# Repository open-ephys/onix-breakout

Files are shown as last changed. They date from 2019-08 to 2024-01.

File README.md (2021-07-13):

# ONIX Breakout Board
This board allows bench access to the IO provided by the [ONIX FMC Host
Board](https://github.com/open-ephys/onix-fmc-host). It features:

- 4x coax headstage ports, each with a physical power switch
- BNC, IDC (ribbon), or direct wire access to 12 analog inputs or outputs
- IDC (ribbon) or direct wire access to 8 digital outputs and 8 digital inputs
  (5 volt tolerate)
- 6x buttons for marking experimental events
- 41x state-indication LEDs
- 3x high-speed clock feed throughs
- Full-speed, USB 2.0 access to the onboard [TinyFPGA
  BX](https://www.crowdsupply.com/tinyfpga/tinyfpga-bx) for communication,
  programming, and customization 
- [HARP bus](https://www.cf-hw.org/harp)
- Rugged M6 or 1/4-20 mounting options compliant with 19" racks and optical
  tables
- Open-source [gateware](./gateware) created using open-source FPGA toolchain:
  [yosys](http://www.clifford.at/yosys/) & [nextpnr](https://github.com/YosysHQ/nextpnr)

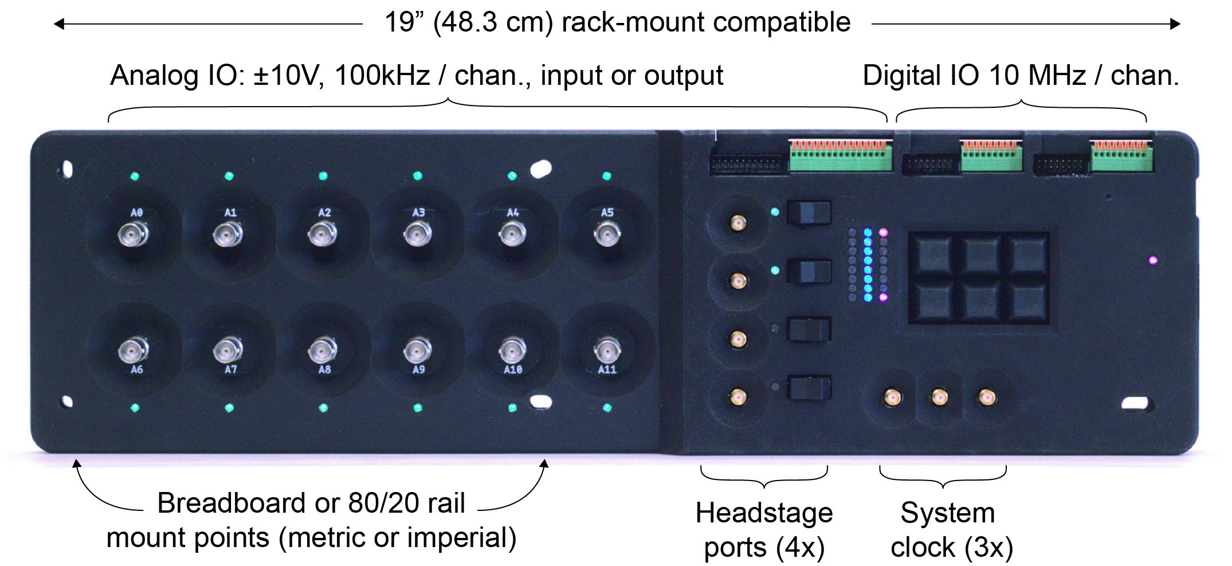
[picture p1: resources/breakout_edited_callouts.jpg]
ONIX Breakout Board revision 1.5


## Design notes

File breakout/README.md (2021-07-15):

## Bill of Materials
The bill of materials for this device can be found
[here](https://docs.google.com/spreadsheets/d/1dZ0ANEF8czLGsupTHfIfsVSbmfPmiTM9wAFmvc-KBbU/edit?usp=sharing).

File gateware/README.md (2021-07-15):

# Breakout Board Gateware
The breakout board contains a [TinyFPGA BX](https://tinyfpga.com/bx/guide.html)
(Lattice ICE40 breakout board) for digital input serialization, digital output
deserialization, interpreting user input, and driving indication LEDs.

## Build Steps
The build process is governed by the included Makefile. There are a few key
targets:

1. `make`: makes the bit file
1. `make sim`: Perform RTL-level simuatation using iverilog
1. `make postsim`: Perform RTL-level simuatation using iverilog
1. `make prog`: makes the bit file and attempts to programm the FPGA using `tinyprog`
1. `make test`: makes the testbenches
1. `make view-test`: makes the testbenches if required and attempts to view resulting waveforms using GTKWave
1. `make clean`: cleans all built artifacts

To build and program the bit file, you will need the
[`yosys`](http://www.clifford.at/yosys/),
[`nextpnr`](https://github.com/YosysHQ/nextpnr), and
[`tinyprog`](https://pypi.org/project/tinyprog/). To build, simulate, and view
the testbenches you will need `yosys`,
[`iverilog`](http://iverilog.icarus.com/), and
[`gtkwave`](http://gtkwave.sourceforge.net/).

### Installing the Toolchain
Install `yosys`:

```
sudo apt install yosys
```

Next, you will need to build and install `nextpnr` as described
[here](https://github.com/YosysHQ/nextpnr#nextpnr-ice40).

### Installing the Programmer
Install `APIO` and `tinyprog`, open up a terminal and run the following
commands:

```
pip install apio==0.4.0b5 tinyprog
apio install system scons icestorm iverilog
apio drivers --serial-enable
```

On Unix systems, you may need to add yourself to the dialout group in order for
your user to be able to access serial ports. You can do that by running:

```
sudo usermod -a -G dialout $USER
```

Connect your TinyFPGA BX board(s) and make sure the bootloader is up to date by
running the following command:

```
tinyprog --update-bootloader
```

Now you can program the FPGA using

```
make prog
```

This will create all required bit files etc before programming

### Building and Examining the Testbenches
Simulation is done with Icrarus Verilog

```
sudo apt install iverilog
sudo apt install gtkwave
```

Then simply `make sim`. You can look at the resulting `.vcd` files using
gtkwave using `make view-test`.

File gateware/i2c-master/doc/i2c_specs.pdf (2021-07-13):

I

2

# C-Master Core Specification

# Author: Richard Herveille

### rherveille@opencores.org

### Rev. 0.9 July 3, 2003

## This page has been intentionally left blank

### Revision History

Rev. | Date | Author | Description
0.1 | 17/02/01 | Richard Herveille | First draft release
0.2 | 01/03/01 | Richard Herveille | Some cleaning up throughout the document Added ‘Programming Examples’ section
0.3 | | Richard Herveille | Added some comments after core-changes - added BUSY bit (status register) - changed I2C IO for ASIC support - added comment for FGPA IO
0.4 | 10/19/01 | Richard Herveille | Changed core’s databus size to 8bit. Changed documentation to reflect changes. Changed port names to new naming convention.
0.5 | 18/02/02 | Richard Herveille | Changed table headers. Added OpenCores logo.
0.5a | 05/02/02 | Richard Herveille | Reviewed entire document.
0.6 | 21/03/02 | Richard Herveille | Added Appendix A, Synthesis Results
0.7 | 25/06/02 | Richard Herveille | Changed Prescale Register formula
0.8 | 30/12/02 | Richard Herveille | Added Multi-Master capabilities. New timing diagrams.
0.9 | 03/07/03 | Richard Herveille | Changed ‘0x5C’ to ‘0xAC’ in Example1. Changed ‘RW’ to ‘W’ in Command Register. Changed ‘RW’ to ‘W’ in Transmit Register.

OpenCores | I²
C-Master core | 7/3/2003
www.opencores.org | Rev 0.8 Preliminary | 1 of 15

1

# Introduction

I

2
C is a two-wire, bi-directional serial bus that provides a simple and efficient method of data exchange between devices. It is most suitable for applications requiring occasional communication over a short distance between many devices. The I²
C standard is a true
multi-master bus including collision detection and arbitration that prevents data corruption if two or more masters attempt to control the bus simultaneously.

The interface defines 3 transmission speeds:
- Normal: 100Kbps
- Fast: 400Kbps
- High speed: 3.5Mbps

Only 100Kbps and 400Kbps modes are supported directly. For High speed special IOs are needed. If these IOs are available and used, then High speed is also supported.

## FEATURES

- Compatible with Philips I²
C standard
- Multi Master Operation
- Software programmable clock frequency
- Clock Stretching and Wait state generation
- Software programmable acknowledge bit
- Interrupt or bit-polling driven byte-by-byte data-transfers
- Arbitration lost interrupt, with automatic transfer cancelation
- Start/Stop/Repeated Start/Acknowledge generation
- Start/Stop/Repeated Start detection
- Bus busy detection
- Supports 7 and 10bit addressing mode
- Operates from a wide range of input clock frequencies
- Static synchronous design
- Fully synthesizable

2

# IO ports

## 2.1 Core Parameters

Parameter | Type | Default | Description
ARST_LVL | Bit | 1’b0 | Asynchronous reset level

### 2.1.1 ARST_LVL

The asynchronous reset level can be set to either active high (1’b1) or active low (1’b0).

## 2.2 WISHBONE interface signals

Port | Width | Direction | Description
wb_clk_i | 1 | Input | Master clock
wb_rst_i | 1 | Input | Synchronous reset, active high
arst_i | 1 | Input | Asynchronous reset
wb_adr_i | 3 | Input | Lower address bits
wb_dat_i | 8 | Input | Data towards the core
wb_dat_o | 8 | Output | Data from the core
wb_we_i | 1 | Input | Write enable input
wb_stb_i | 1 | Input | Strobe signal/Core select input
wb_cyc_i | 1 | Input | Valid bus cycle input
wb_ack_o | 1 | Output | Bus cycle acknowledge output
wb_inta_o | 1 | Output | Interrupt signal output

The core features a WISHBONE RevB.3 compliant WISHBONE Classic interface. All output signals are registered. Each access takes 2 clock cycles.
arst_i is not a WISHBONE compatible signal. It is provided for FPGA implementations. Using [arst_i] instead of [wb_rst_i] can result in lower cell-usage and higher performance, because most FPGAs provide a dedicated asynchronous reset path. Use either [arst_i] or [wb_rst_i], tie the other to a negated state.

## 2.3 External connections

Port | Width | Direction | Description
scl_pad_i | 1 | Input | Serial Clock line input
scl_pad_o | 1 | Output | Serial Clock line output
scl_pad_oe | 1 | Output | Serial Clock line output enable
sda_pad_i | 1 | Input | Serial Data line input
sda_pad_o | 1 | Output | Serial Data line output
sda_pad_oe | 1 | Output | Serial Data line output enable

The I²
C interface uses a serial data line (SDA) and a serial clock line (SCL) for data transfers. All devices connected to these two signals must have open drain or open collector outputs. Both lines must be pulled-up to VCC by external resistors.

The tri-state buffers for the SCL and SDA lines must be added at a higher hierarchical level. Connections should be made according to the following figure:

For FPGA designs the compiler can automatically insert these buffers using the following VHDL code:

scl <= scl_pad_o when (scl_padoen_oe = ‘0’) else ‘Z’;
sda <= sda_pad_o when (sda_padoen_oe = ‘0’) else ‘Z’;
scl_pad_i <= scl;
scl_pad_i <= sda;

Verilog code:

assign scl = scl_padoen_oe ? 1’bz : scl_pad_o; assign sda = sda_padoen_oe ? 1’bz: sda_pad_o; assign scl_pad_i = scl;
assign sda_pad_i = sda;

scl_pad_i

scl_pad_o

scl_padoen_o
sda_pad_i

sda_pad_o

sda_padoen_o

SCL

SDA

3

# Registers

## 3.1 Registers list

Name | Address | Width | Access | Description
PRERlo | 0x00 | 8 | RW | Clock Prescale register lo-byte
PRERhi | 0x01 | 8 | RW | Clock Prescale register hi-byte
CTR | 0x02 | 8 | RW | Control register
TXR | 0x03 | 8 | W | Transmit register
RXR | 0x03 | 8 | R | Receive register
CR | 0x04 | 8 | W | Command register
SR | 0x04 | 8 | R | Status register

## 3.2 Register description

### 3.2.1 Prescale Register

This register is used to prescale the SCL clock line. Due to the structure of the I² C
interface, the core uses a 5*SCL clock internally. The prescale register must be programmed to this 5*SCL frequency (minus 1). Change the value of the prescale register only when the ‘EN’ bit is cleared.

Example: wb_clk_i = 32MHz, desired SCL = 100KHz
1 | 63 ( | ) | 3 ( | ) 5 100
32 | dec | F hex
KHz
MHz prescale | − = | = ∗ =

Reset value: 0xFFFF

### 3.2.2 Control register

Bit # | Access | Description
7 | RW | EN, I² C core enable bit. When set to ‘1’, the core is enabled. When set to ‘0’, the core is disabled.
6 | RW | IEN, I² C core interrupt enable bit. When set to ‘1’, interrupt is enabled. When set to ‘0’, interrupt is disabled.
5:0 | RW | Reserved
Reset Value: 0x00

The core responds to new commands only when the ‘EN’ bit is set. Pending commands are finished. Clear the ‘EN’ bit only when no transfer is in progress, i.e. after a STOP command, or when the command register has the STO bit set. When halted during a transfer, the core can hang the I²
C bus.

### 3.2.3 Transmit register

Bit # | Access | Description
7:1 | W | Next byte to transmit via I² C
0 | W | In case of a data transfer this bit represent the data’s LSB. In case of a slave address transfer this bit represents the RW bit. ‘1’ = reading from slave ‘0’ = writing to slave

Reset value: 0x00

### 3.2.4 Receive register

Bit # | Access | Description
7:0 | R | Last byte received via I² C
Reset value: 0x00

### 3.2.5 Command register

Bit # | Access | Description
7 | W | STA, generate (repeated) start condition
6 | W | STO, generate stop condition
5 | W | RD, read from slave
4 | W | WR, write to slave
3 | W | ACK, when a receiver, sent ACK (ACK = ‘0’) or NACK (ACK = ‘1’)
2:1 | W | Reserved
0 | W | IACK, Interrupt acknowledge. When set, clears a pending interrupt.
Reset Value: 0x00

The STA, STO, RD, WR, and IACK bits are cleared automatically. These bits are always read as zeros.

### 3.2.6 Status register

Bit # | Access | Description
7 | R | RxACK, Received acknowledge from slave. This flag represents acknowledge from the addressed slave. ‘1’ = No acknowledge received ‘0’ = Acknowledge received
6 | R | Busy, I² C bus busy ‘1’ after START signal detected ‘0’ after STOP signal detected
5 | R | AL, Arbitration lost This bit is set when the core lost arbitration. Arbitration is lost when: • a STOP signal is detected, but non requested • The master drives SDA high, but SDA is low. See bus-arbitration section for more information.
4:2 | R | Reserved
1 | R | TIP, Transfer in progress. ‘1’ when transferring data ‘0’ when transfer complete
0 | R | IF, Interrupt Flag. This bit is set when an interrupt is pending, which will cause a processor interrupt request if the IEN bit is set. The Interrupt Flag is set when: • one byte transfer has been completed • arbitration is lost

Reset Value: 0x00

Please note that all reserved bits are read as zeros. To ensure forward compatibility, they should be written as zeros.

4

# Operation

## 4.1 System Configuration

The I²
C system uses a serial data line (SDA) and a serial clock line (SCL) for data transfers. All devices connected to these two signals must have open drain or open collector outputs. The logic AND function is exercised on both lines with external pull-up resistors.

Data is transferred between a Master and a Slave synchronously to SCL on the SDA line on a byte-by-byte basis. Each data byte is 8 bits long. There is one SCL clock pulse for each data bit with the MSB being transmitted first. An acknowledge bit follows each transferred byte. Each bit is sampled during the high period of SCL; therefore, the SDA line may be changed only during the low period of SCL and must be held stable during the high period of SCL. A transition on the SDA line while SCL is high is interpreted as a command (see START and STOP signals).

## 4.2 I² C Protocol

Normally, a standard communication consists of four parts:
1) START signal generation
2) Slave address transfer
3) Data transfer
4) STOP signal generation
S | A7 | A6 | A5 | A4 | A3 | A2 | A1 | RW ACK | D7 | D6 | D5 | D4 | D3 | D2 | D1 | D0 NACK | P

SCL

SDA

1 | 2 | 3 | 4 | 5 | 6 | 7 | 8 | 9
MSB | LSB
1 | 2 | 3 | 4 | 5 | 6 | 7 | 8 | 9
MSB | LSB

### 4.2.1 START signal

When the bus is free/idle, meaning no master device is engaging the bus (both SCL and SDA lines are high), a master can initiate a transfer by sending a START signal. A START signal, usually referred to as the S-bit, is defined as a high-to-low transition of SDA while SCL is high. The START signal denotes the beginning of a new data transfer. A Repeated START is a START signal without first generating a STOP signal. The master uses this method to communicate with another slave or the same slave in a different transfer direction (e.g. from writing to a device to reading from a device) without releasing the bus.

The core generates a START signal when the STA-bit in the Command Register is set and the RD or WR bits are set. Depending on the current status of the SCL line, a START or Repeated START is generated.

### 4.2.2 Slave Address Transfer

The first byte of data transferred by the master immediately after the START signal is the slave address. This is a seven-bits calling address followed by a RW bit. The RW bit signals the slave the data transfer direction. No two slaves in the system can have the same address. Only the slave with an address that matches the one transmitted by the master will respond by returning an acknowledge bit by pulling the SDA low at the 9th SCL clock cycle.

Note: The core supports 10bit slave addresses by generating two address transfers. See the Philips I²
C specifications for more details.

The core treats a Slave Address Transfer as any other write action. Store the slave device’s address in the Transmit Register and set the WR bit. The core will then transfer the slave address on the bus.

### 4.2.3 Data Transfer

Once successful slave addressing has been achieved, the data transfer can proceed on a byte-by-byte basis in the direction specified by the RW bit sent by the master. Each transferred byte is followed by an acknowledge bit on the 9th SCL clock cycle. If the slave signals a No Acknowledge, the master can generate a STOP signal to abort the data transfer or generate a Repeated START signal and start a new transfer cycle.

If the master, as the receiving device, does not acknowledge the slave, the slave releases the SDA line for the master to generate a STOP or Repeated START signal.

To write data to a slave, store the data to be transmitted in the Transmit Register and set the WR bit. To read data from a slave, set the RD bit. During a transfer the core set the TIP flag, indicating that a Transfer is In Progress. When the transfer is done the TIP flag is reset, the IF flag set and, when enabled, an interrupt generated. The Receive Register contains valid data after the IF flag has been set. The user may issue a new write or read command when the TIP flag is reset.

### 4.2.4 STOP signal

The master can terminate the communication by generating a STOP signal. A STOP signal, usually referred to as the P-bit, is defined as a low-to-high transition of SDA while SCL is at logical ‘1’.

## 4.3 Arbitration Procedure

### 4.3.1 Clock Synchronization

The I²
C bus is a true multimaster bus that allows more than one master to be connected on it. If two or more masters simultaneously try to control the bus, a clock synchronization procedure determines the bus clock. Because of the wired-AND connection of the I²
C signals a high to low transition affects all devices connected to the bus. Therefore a high to low transition on the SCL line causes all concerned devices to count off their low period. Once a device clock has gone low it will hold the SCL line in that state until the clock high state is reached. Due to the wired-AND connection the SCL line will therefore be held low by the device with the longest low period, and held high by the device with the shortest high period.

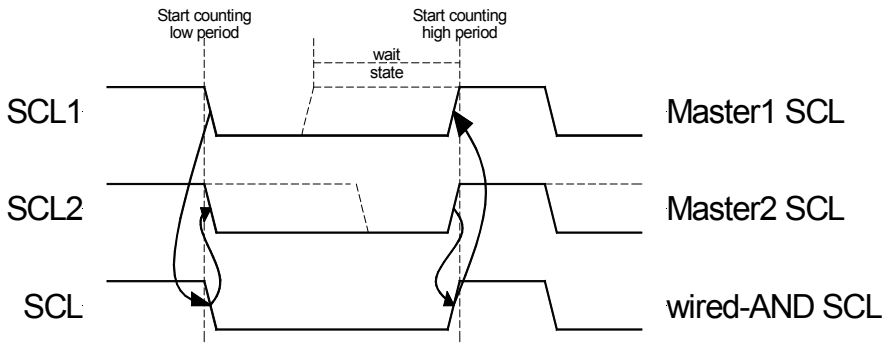
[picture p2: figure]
Start counting low period; wait state; Start counting high period; SCL1; SCL2; SCL; Master1 SCL; Master2 SCL; wired-AND SCL

### 4.3.2 Clock Stretching

Slave devices can use the clock synchronization mechanism to slow down the transfer bit rate. After the master has driven SCL low, the slave can drive SCL low for the required period and then release it. If the slave’s SCL low period is greater than the master’s SCL low period, the resulting SCL bus signal low period is stretched, thus inserting wait-states.

5

# Architecture

The I2C core is built around four primary blocks; the Clock Generator, the Byte Command Controller, the Bit Command Controller and the DataIO Shift Register. All other blocks are used for interfacing or for storing temporary values.

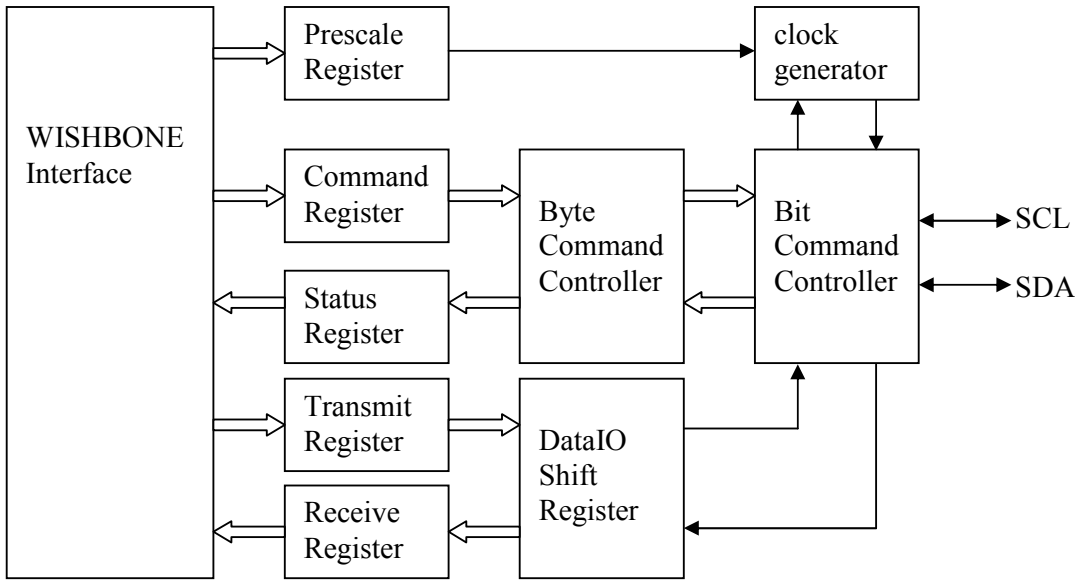
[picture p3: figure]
SCL; SDA; Prescale Register; clock generator; Command Register; Status Register; Byte Command Controller; Bit Command Controller; WISHBONE Interface; Transmit Register; Receive Register; DataIO Shift Register

## 5.1 Clock Generator

The Clock Generator generates an internal 4*Fscl clock enable signal that triggers all synchronous elements in the Bit Command Controller. It also handles clock stretching needed by some slaves.

## 5.2 Byte Command Controller

The Byte Command Controller handles I2C traffic at the byte level. It takes data from the Command Register and translates it into sequences based on the transmission of a single byte. By setting the START, STOP, and READ bit in the Command Register, for example, the Byte Command Controller generates a sequence that results in the

Fig. 5.1 Internal structure I2C Master Core

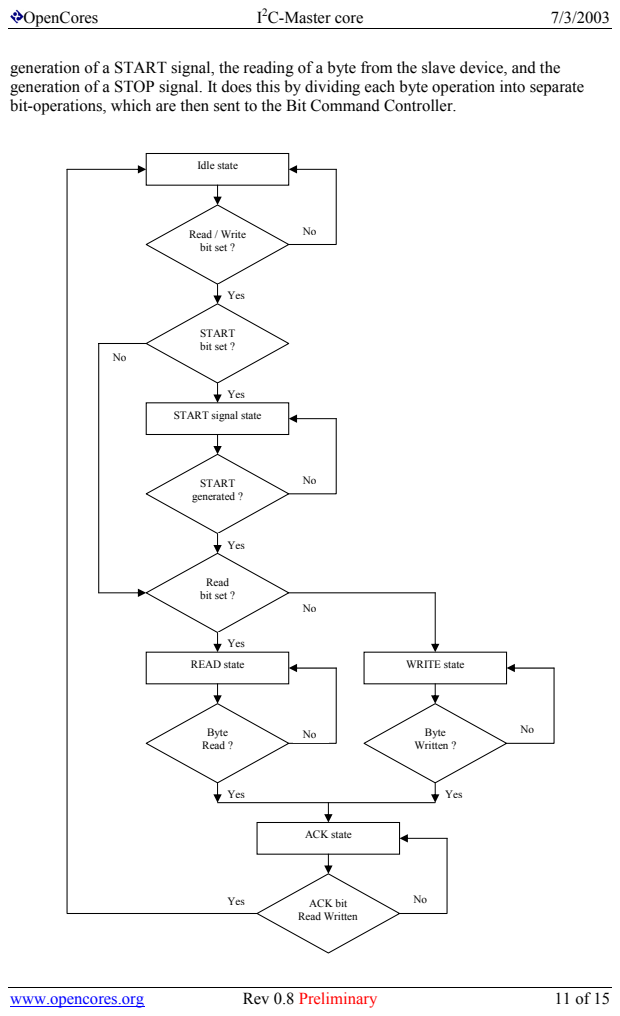
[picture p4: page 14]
Idle state; Read / Write bit set ?; Yes; START bit set ?; Read bit set ?; READ state; Byte Read ?; ACK state; WRITE state; Byte Written ?; ACK bit Read Written

generation of a START signal, the reading of a byte from the slave device, and the
generation of a STOP signal. It does this by dividing each byte operation into separate
bit-operations, which are then sent to the Bit Command Controller.

START signal state

START generated ?

## 5.3 Bit Command Controller

The Bit Command Controller handles the actual transmission of data and the generation of the specific levels for START, Repeated START, and STOP signals by controlling the SCL and SDA lines. The Byte Command Controller tells the Bit Command Controller which operation has to be performed. For a single byte read, the Bit Command Controller receives 8 separate read commands. Each bit-operation is divided into 5 pieces (idle and A, B, C, and D), except for a STOP operation which is divided into 4 pieces (idle and A, B, and C).

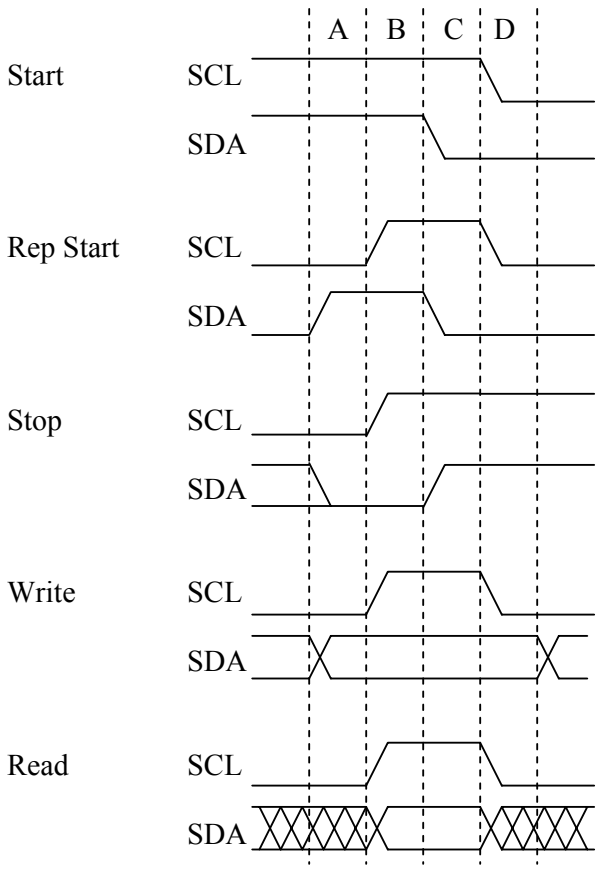
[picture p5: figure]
Start; SCL; SDA; Rep Start; Stop; Write; Read

## 5.4 DataIO Shift Register

The DataIO Shift Register contains the data associated with the current transfer. During a read action, data is shifted in from the SDA line. After a byte has been read the contents are copied into the Receive Register. During a write action, the Transmit Register’s contents are copied into the DataIO Shift Register and are then transmitted onto the SDA line.

6

# Programming examples

## Example 1

Write 1 byte of data to a slave.

Slave address = 0x51 (b”1010001”) Data to write = 0xAC

I2C Sequence:
1) generate start command
2) write slave address + write bit
3) receive acknowledge from slave
4) write data
5) receive acknowledge from slave
6) generate stop command

Commands:
1) write 0xA2 (address + write bit) to Transmit Register, set STA bit, set WR bit. -- wait for interrupt or TIP flag to negate --
2) read RxACK bit from Status Register, should be ‘0’.
write 0xAC to Transmit register, set STO bit, set WR bit.
-- wait for interrupt or TIP flag to negate --
3) read RxACK bit from Status Register, should be ‘0’.

Please note that the time for the Interrupt Service Routine is not shown here. It is assumed that the ISR is much faster then the I²
C cycle time, and therefore not visible.

## Example 2

Read a byte of data from an I2C memory device.

Slave address = 0x4E
Memory location to read from = 0x20

I2C sequence:
1) generate start signal
2) write slave address + write bit
3) receive acknowledge from slave
4) write memory location
5) receive acknowledge from slave
6) generate repeated start signal
7) write slave address + read bit
8) receive acknowledge from slave
9) read byte from slave
10) write no acknowledge (NACK) to slave, indicating end of transfer
11) generate stop signal

Commands:
1) write 0x9C (address + write bit) to Transmit Register, set STA bit, set WR bit. -- wait for interrupt or TIP flag to negate --
2) read RxACK bit from Status Register, should be ‘0’.
write 0x20 to Transmit register, set WR bit.
-- wait for interrupt or TIP flag to negate --
3) read RxACK bit from Status Register, should be ‘0’.
write 0x9D (address + read bit) to Transmit Register, set STA bit, set WR bit. -- wait for interrupt or TIP flag to negate --
4) set RD bit, set ACK to ‘1’ (NACK), set STO bit

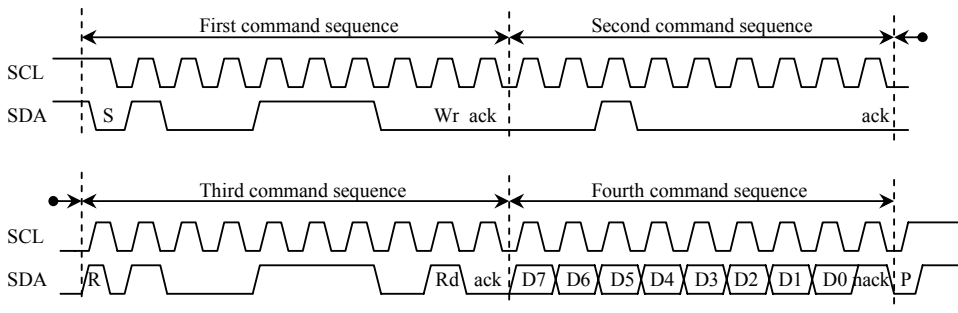
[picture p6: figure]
First command sequence; Second command sequence; SDA; Wr ack; ack; SCL; Third command sequence; Fourth command sequence

Please note that the time for the Interrupt Service Routine is not shown here. It is assumed that the ISR is much faster then the I²
C cycle time, and therefore not visible.
SDA | R | Rd ack | D7 D6 D5 D4 D3 D2 D1 D0 nack | P

# Appendix A

# Synthesis results

Synthesis tool: Synplify Pro

Technology | Device | Speed grade | Fmax | Resource usage
ACTEL | A54SX16ATQ100 | std | 58MHz | Modules: 352
Altera | EP10K50ETC144 | -3 | 82MHz | LCs: 294
| EP20K30ETC144 | -3 | 74MHz | ATOMS: 257
Xilinx | 2s15CS144 | -5 | 82MHz | LUTs: 229
| XCV50ECS144 | -8 | 118MHz | LUTs: 230

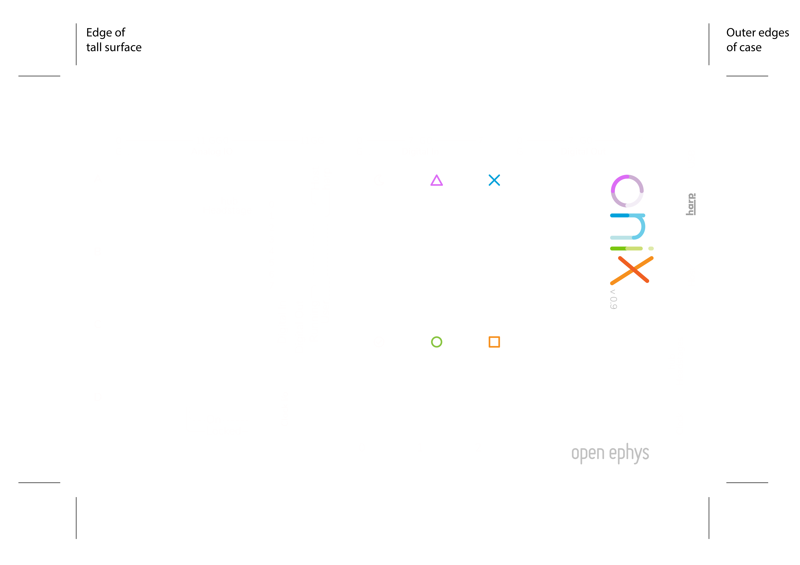
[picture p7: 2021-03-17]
mechanical/label/top_label_600ppi.png

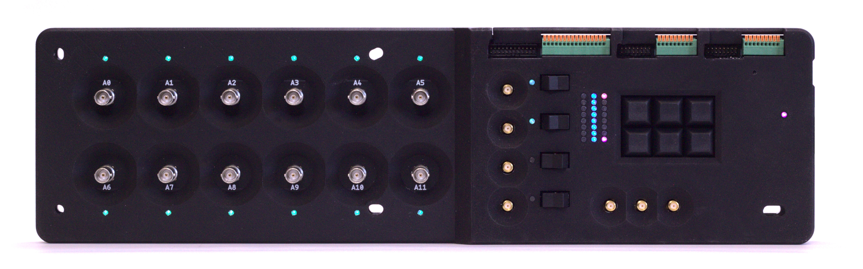
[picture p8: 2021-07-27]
resources/breakout_edited.jpg

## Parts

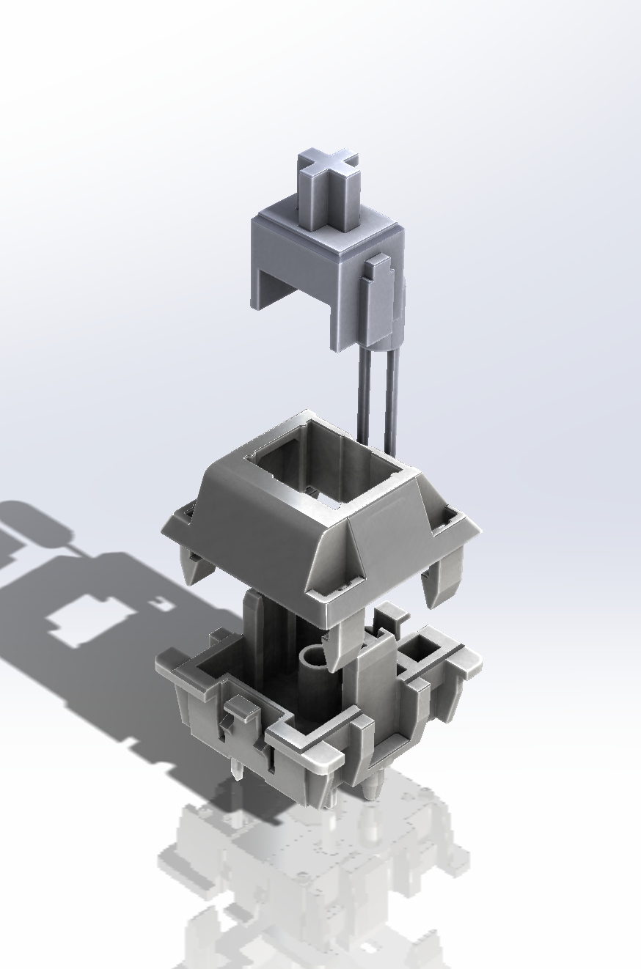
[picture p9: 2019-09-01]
mechanical/case/components/cherryMX/Renderings/屏幕截图(27)_副本.jpg

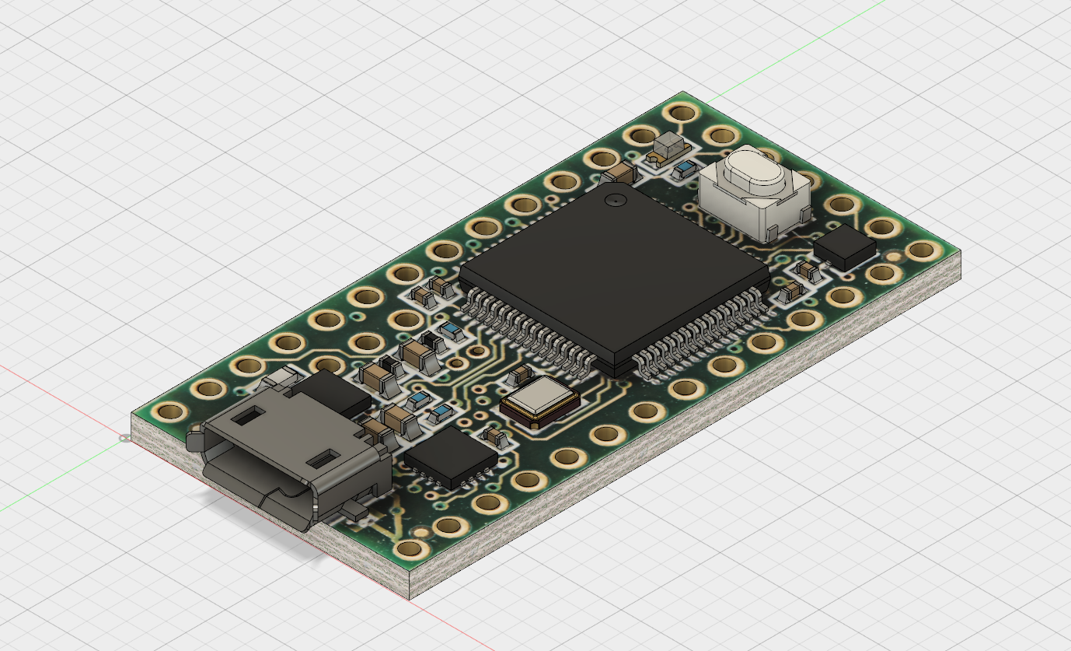
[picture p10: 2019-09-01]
mechanical/case/components/teensy/Teensy_3_1 v13.png

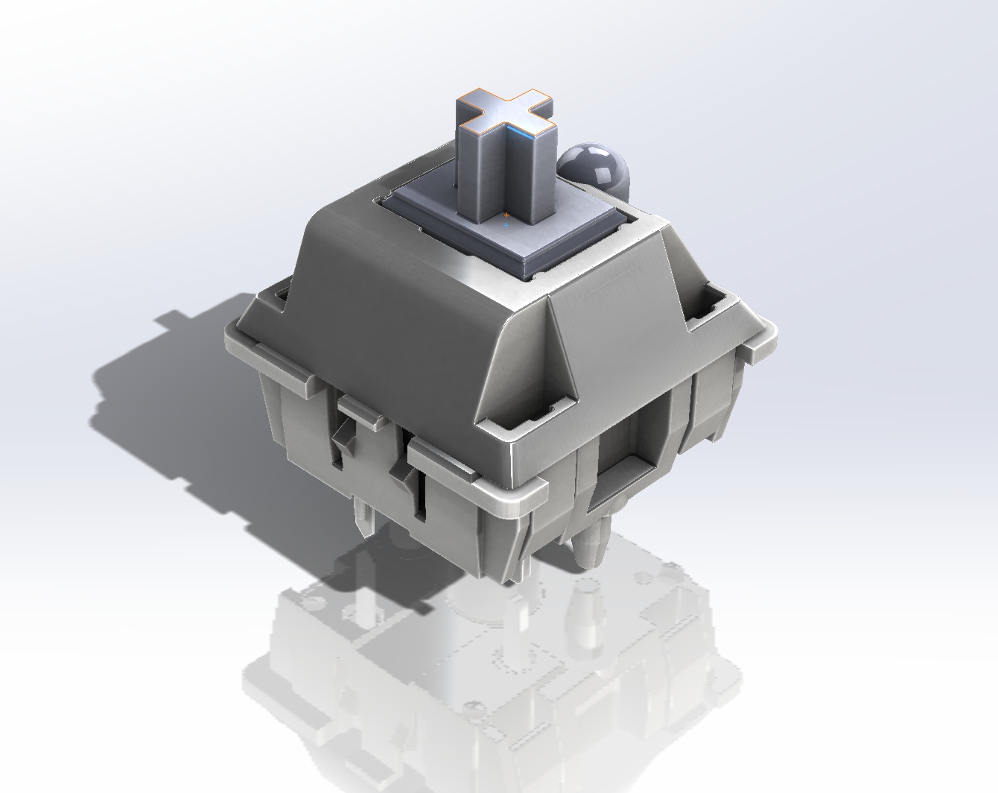
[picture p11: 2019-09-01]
mechanical/case/components/cherryMX/Renderings/屏幕截图(23).jpg

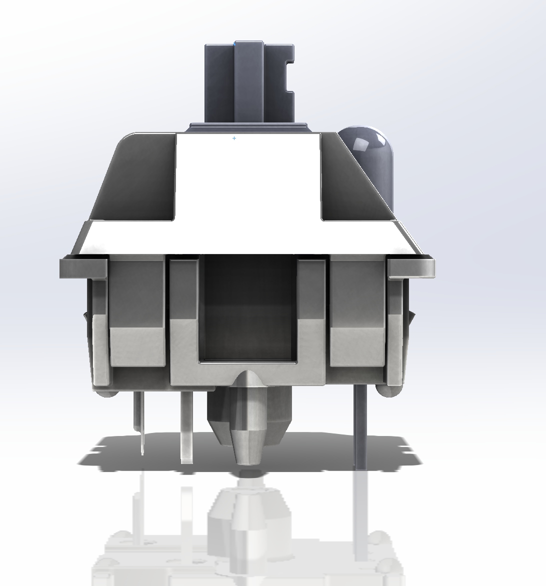
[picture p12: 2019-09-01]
mechanical/case/components/cherryMX/Renderings/屏幕截图(26).jpg

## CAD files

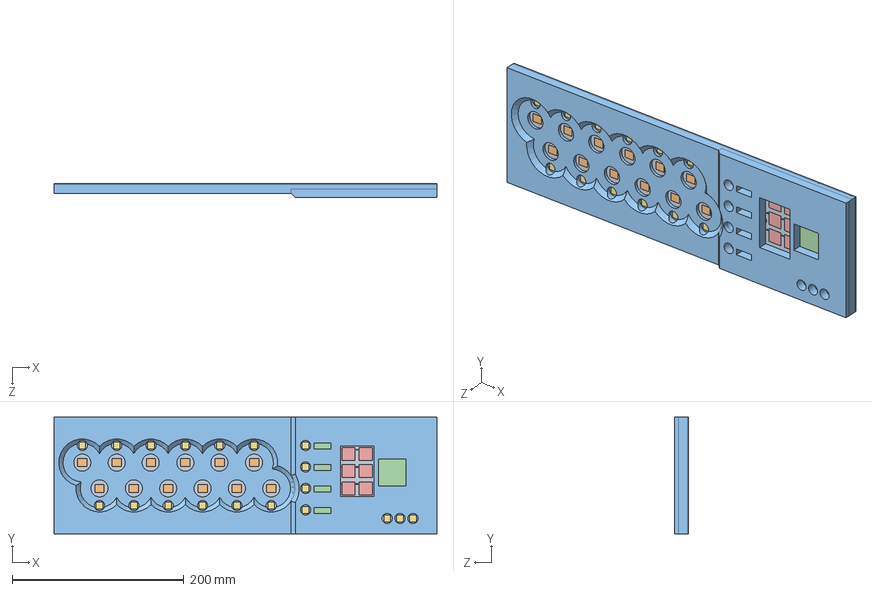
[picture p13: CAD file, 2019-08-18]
case/analog-io-breakout_assembly.SLDASM
446.0 x 136.0 x 16.6 mm
Board.step
0731010360.step x 12
FE10-2.step
MMCX-J-P-X-RA-SM1.step x 7
SCREW2.step x 2
SCREW8.step x 2
SMA_JACK_142-0701-201.step x 19
TESTPOINT_2MM.step
DIODE-ESD-BIDIRECTIONALDO-214AA.step x 12
TEENSY_3.1_BASIC.step
1503_02.step
ADAFRUIT_1_5_OLED.step
CHERRY-MX.step x 6
12226-8250-00FR.step
1k.step x 34
SJ_2_0201.step x 2
LTC2875_DFN.step
FIN1032MTCX.step
SN65LVDS9638DGN.step x 2
ROCKER_SWITCH.step x 4
G6KU-2F-RF-TR09DC5.step x 4
LTM4622A.step
10uF.step
47uF.step x 2
B1,27.step x 2
TCA9555.step
breakout_case_top_shell

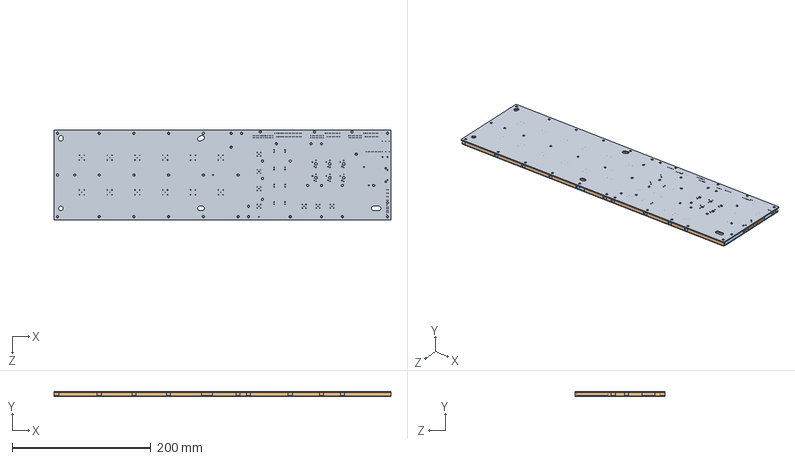
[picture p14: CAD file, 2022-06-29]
mechanical/case/breakout_assembly_bottom_only_lasercut.SLDASM
485.0 x 7.10 x 130.0 mm
breakout_case_pcb_3
pcb_spacer_lasercut
pcb_bottom_waterjet

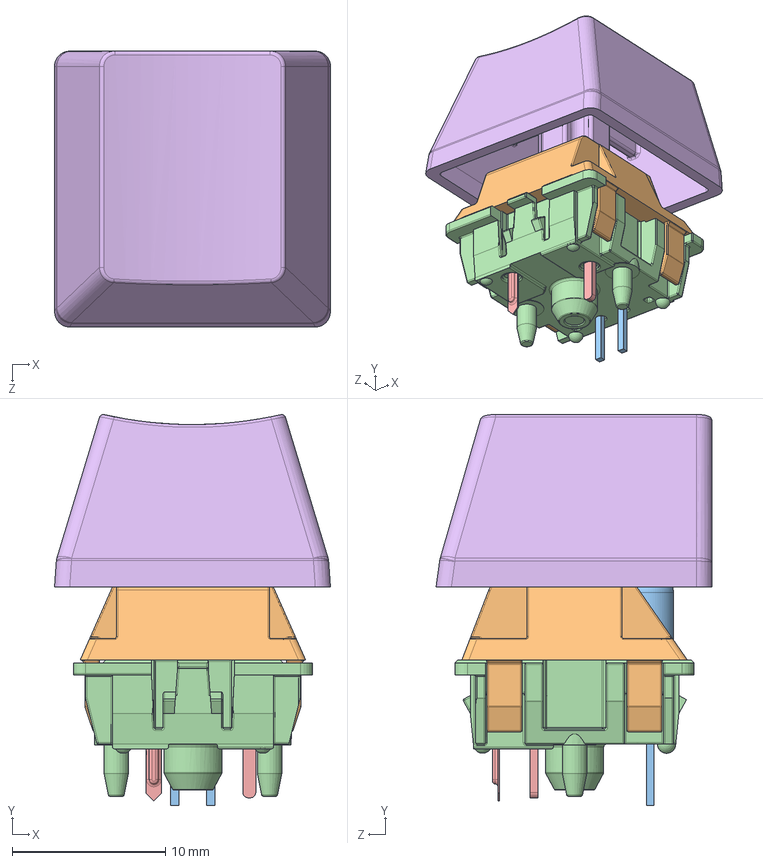
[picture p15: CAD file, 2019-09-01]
mechanical/case/components/cherryMX/MX 按键.SLDASM
18.0 x 25.5 x 18.0 mm
MX 轴 按键
MX 轴 轴体
MX轴 无帽LED
MX轴 轴体 底部
针脚
MX 轴标准键帽

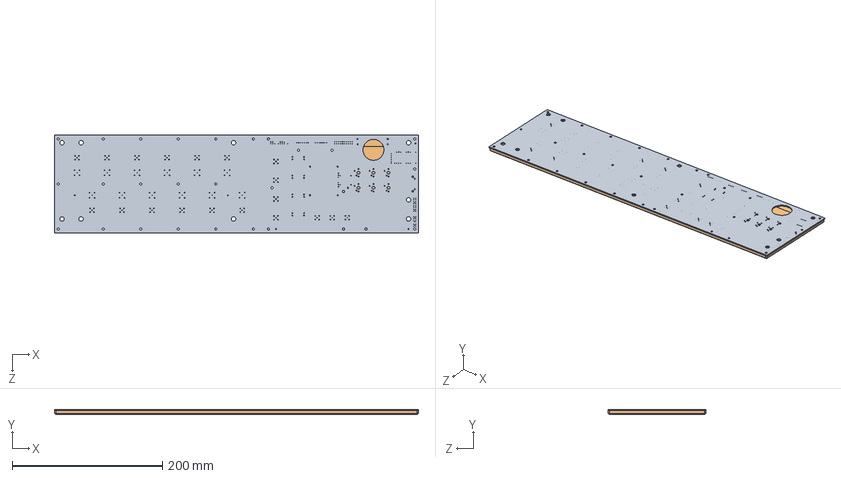
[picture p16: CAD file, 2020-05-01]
mechanical/case/breakout_assembly_bottom_only.SLDASM
485.0 x 6.60 x 130.0 mm

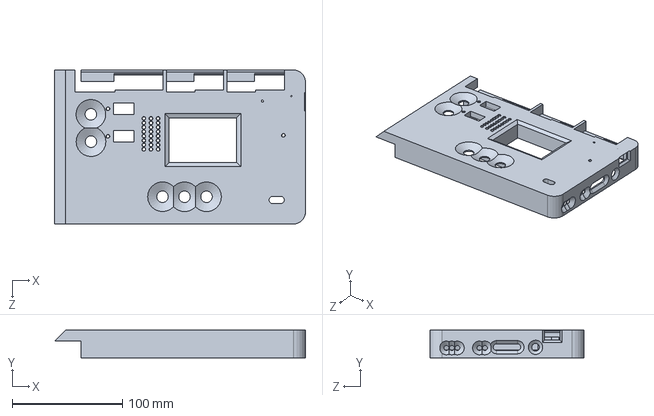
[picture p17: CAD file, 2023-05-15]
mechanical/case/breakout_case_top_shell_2-headstage_b.SLDPRT
228.0 x 25.0 x 140.0 mm

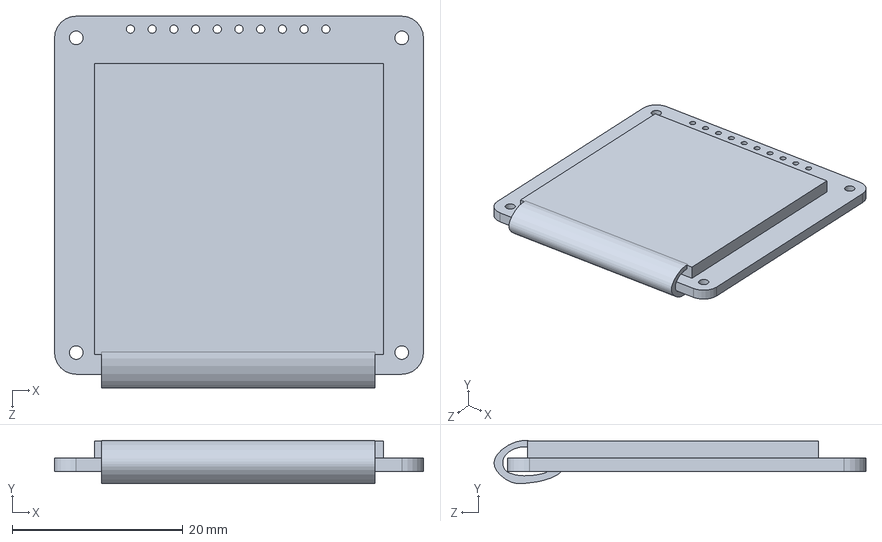
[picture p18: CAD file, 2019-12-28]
mechanical/case/components/1_5_inch_screen/oled_module.SLDPRT
43.2 x 5.05 x 43.5 mm

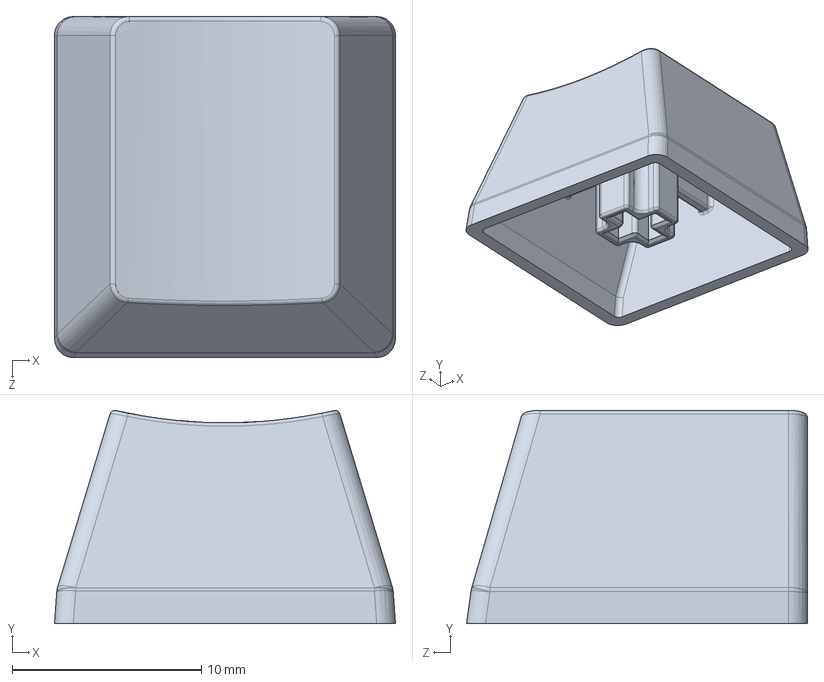
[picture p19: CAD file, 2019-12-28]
mechanical/case/components/cherryMX/MX 轴标准键帽.SLDPRT
18.0 x 11.3 x 18.0 mm

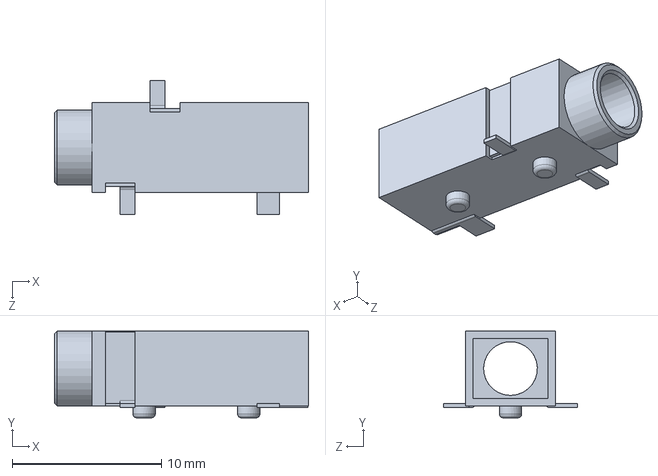
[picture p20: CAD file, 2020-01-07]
mechanical/case/components/CUI_DEVICES_SJ-3523-SMT-TR.sldprt
17.0 x 5.80 x 9.00 mm

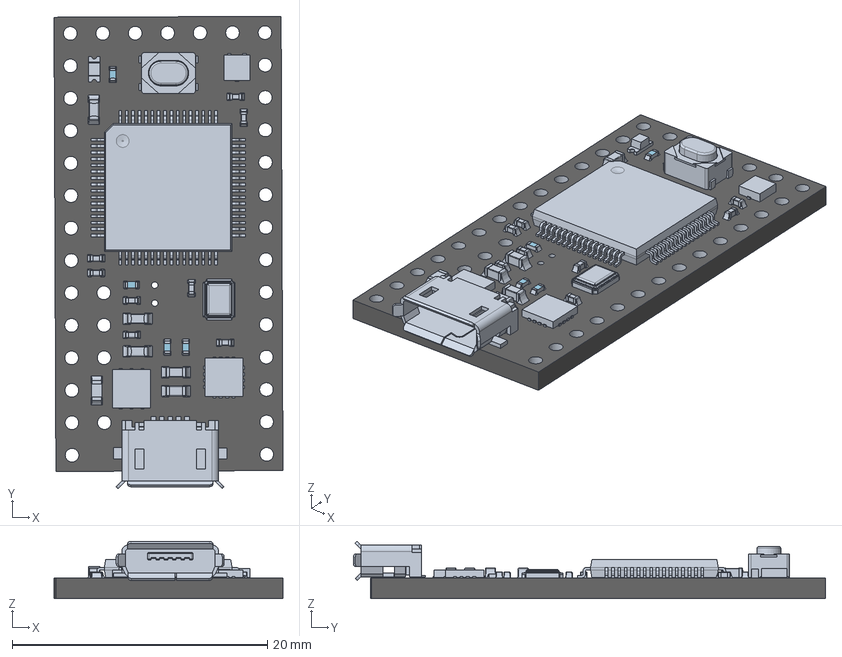
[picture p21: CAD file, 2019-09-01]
mechanical/case/components/teensy/Teensy_3_1.stp
17.9 x 37.0 x 4.49 mm
board
micro_usb_plastic (1)
micro_usb_shell (1)
lead
package (1)
lead (3) x 64
package
lead (1)
cap0402 v2 x 6
lead (2)
diode_0402 v1 x 4
cap0603_03 v3 x 5
cap0402 v2 (1) x 2
smt_led_0805 v2
resistor_0603 v3

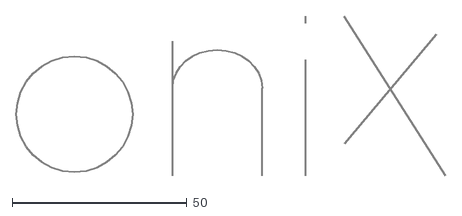
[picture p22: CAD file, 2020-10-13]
mechanical/label/onix_logo_bw.dxf
122.9 x 45.6

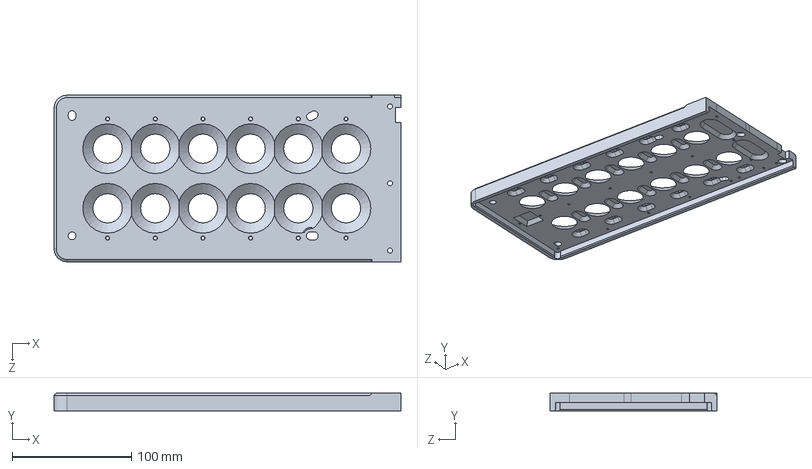
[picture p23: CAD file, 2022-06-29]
mechanical/case/breakout_case_top_shell_2-headstage_a.SLDPRT
291.2 x 15.0 x 140.0 mm

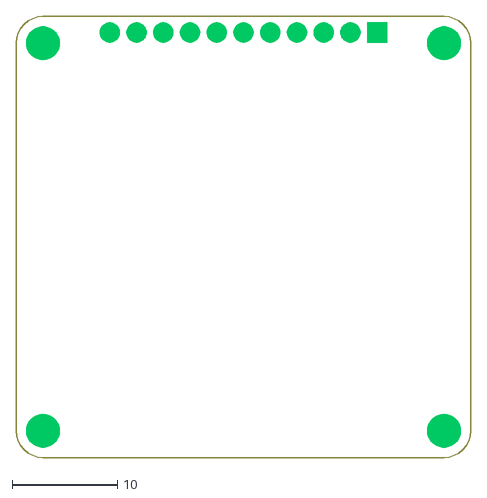
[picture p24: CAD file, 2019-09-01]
mechanical/case/components/1_5_inch_screen/Adafruit_1.5_128x128_RGB_OLED.dxf
43.2 x 41.9

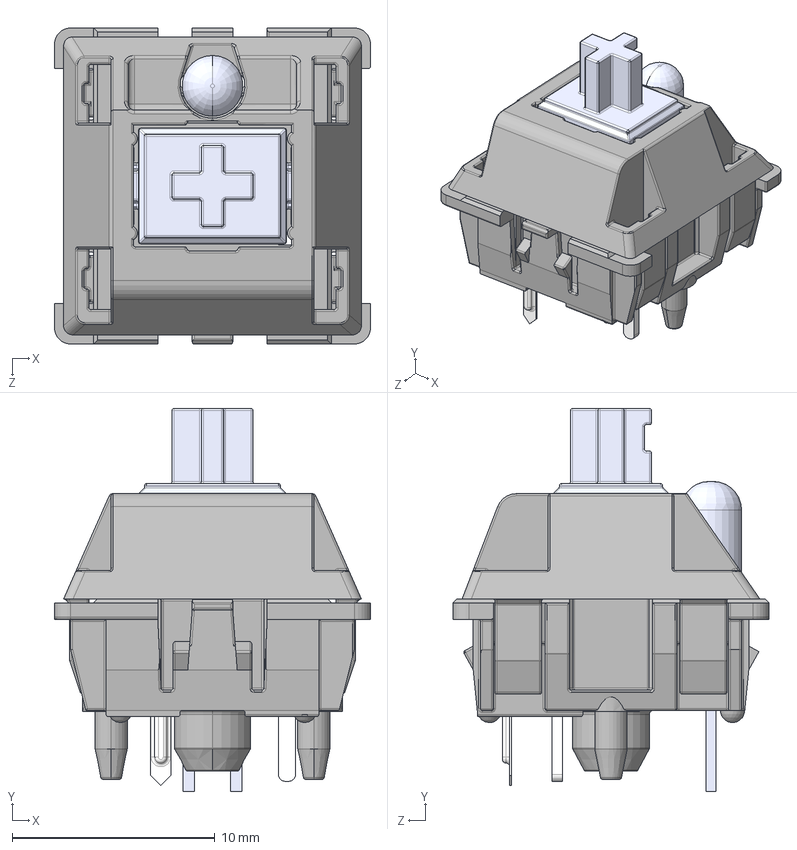
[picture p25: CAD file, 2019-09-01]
mechanical/case/components/cherryMX/MX .STEP
15.6 x 18.9 x 15.6 mm
MX 轴 按键′_ü___¨1
MX 轴 轴体áì_¨￠¨__
MX粣 拸簽LEDLEDLED
MX轴 轴体 底部 μ×2__默认_á2____è_
针脚___默认__è_

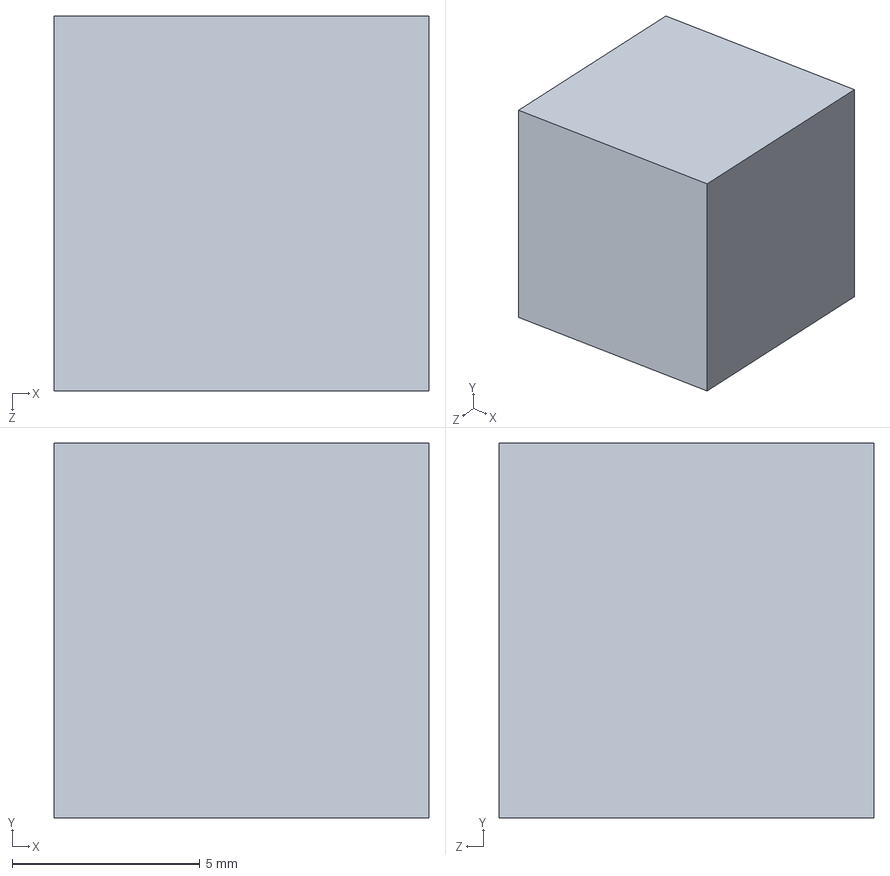
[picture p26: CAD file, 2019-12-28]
mechanical/case/components/header_height_spacer_10mm.SLDPRT
10.0 x 10.0 x 10.0 mm

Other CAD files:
mechanical/case/components/switch_7101J1V3BE2/7101J1V3BE2.sldasm
mechanical/case/components/switch_7101J1V3BE2/1_2.sldprt
mechanical/case/components/cherryMX/MX轴 轴体 底部.SLDPRT
mechanical/case/components/mmcx_through_hole.SLDPRT
mechanical/case/LPA-C011302S-2_lightpipe.SLDPRT
mechanical/case/Part157.SLDPRT
mechanical/case/WP154A4SEJ3VBDZGW-CA_rgb-led.SLDPRT
mechanical/case/breakout_case_pcb.SLDPRT
mechanical/case/breakout_case_top_shell_2-headstage.SLDPRT
mechanical/case/components/audio_plug_CUI_SJ1-3514-SMT-TR.sldprt
mechanical/case/components/bnc_112538.SLDPRT
mechanical/case/components/bnc_112538.igs
mechanical/case/components/cameralink_12226-8250-00FR.SLDPRT
mechanical/case/components/cameralink_12226-8250-00FR.stp
mechanical/case/components/cherryMX/MX 轴 按键.SLDPRT
mechanical/case/components/cherryMX/MX 轴 轴体.SLDPRT
mechanical/case/components/cherryMX/MX轴 无帽LED.SLDPRT
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

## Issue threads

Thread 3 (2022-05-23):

LEDs sometimes turn off during acquisition

jonnew, 2022-05-23:
Sometimes, the LEDs all turn off during acquisition as if the "moon" button was pressed. This bug is hard to reproduce and appears to be quite random. Some possibilities include an issue with the gateware on the breakout board that causes the internal `dark` https://github.com/open-ephys/onix-breakout/blob/429921714c6153bc001e9827c4994195a73d1834/gateware/neopix_controller.v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 bit to toggle. A more serious potential cause is communication error with host that causes this bit to flip when it should not.

jonnew, 2022-06-25:
They can also turn back on. This happens during register reading. One time I was examining a register in Bonsai and they turned off. Another time I was examining the same register, several hours later, and they turned back on.

jonnew, 2023-02-28:
This was a host firmware bug that was fixed in 0.6.

Closed 2023-02-28.

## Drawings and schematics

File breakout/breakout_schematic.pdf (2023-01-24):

# Status LEDs

PWR | HST0 | HARP | LOCK

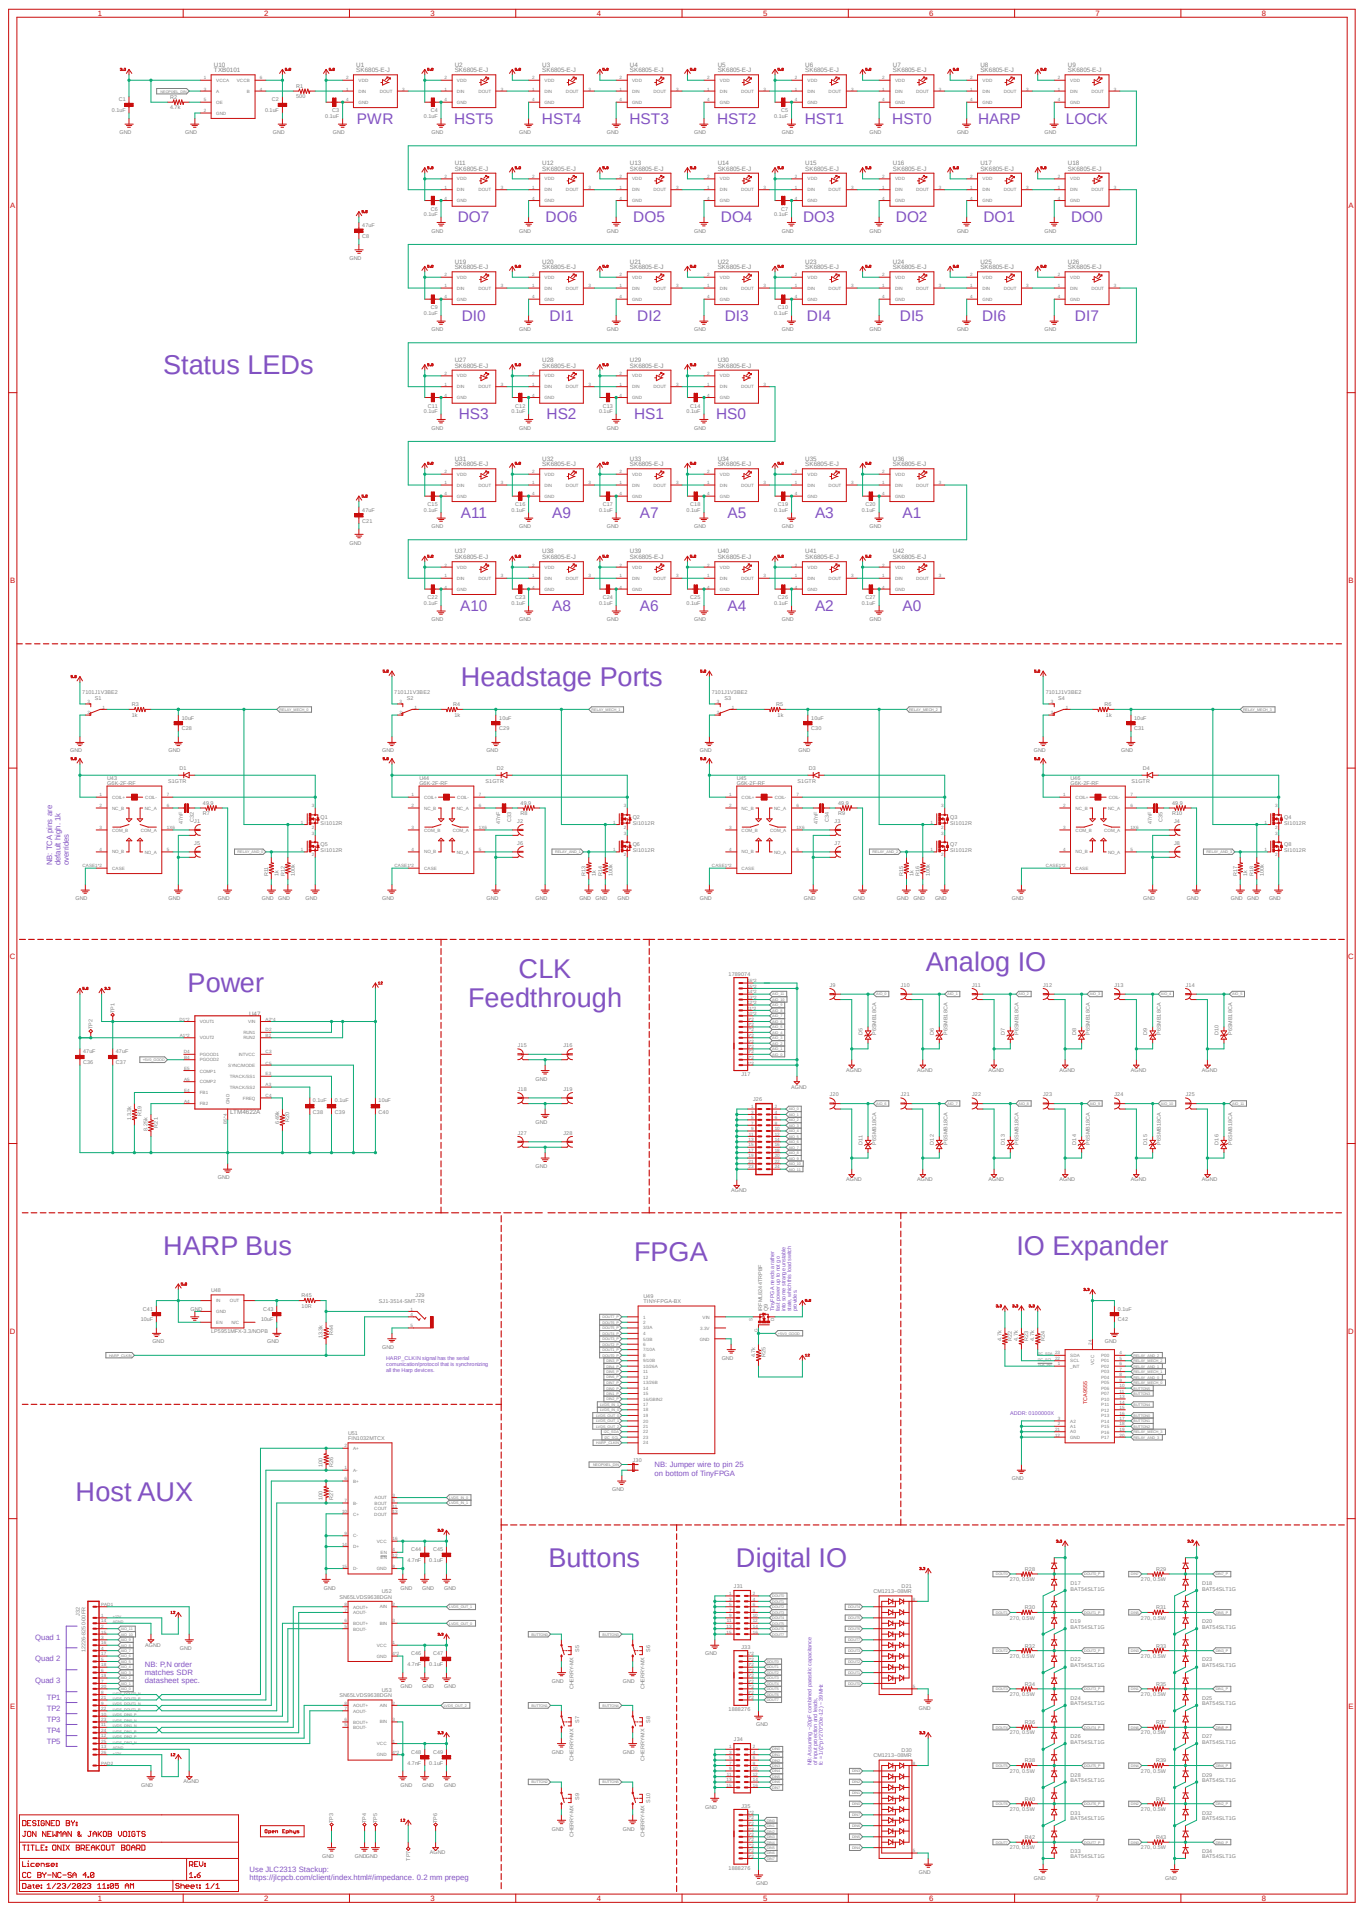
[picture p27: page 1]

all the Harp devices. HARP Bus

HARP_CLKIN signal has the serial
comunication/protocol that is synchronizing

ADDR: 0100000X NB: Assuming ~20pF combined parasitic capacitance of input proection and leads, fc = 1/(2*pi*270*20e⁻12⁾ ~ 39MHz

NB: Jumper wire to pin 25
on bottom of TinyFPGA

Use JLC2313 Stackup:
https://jlcpcb.com/client/index.html#/impedance. 0.2 mm prepeg

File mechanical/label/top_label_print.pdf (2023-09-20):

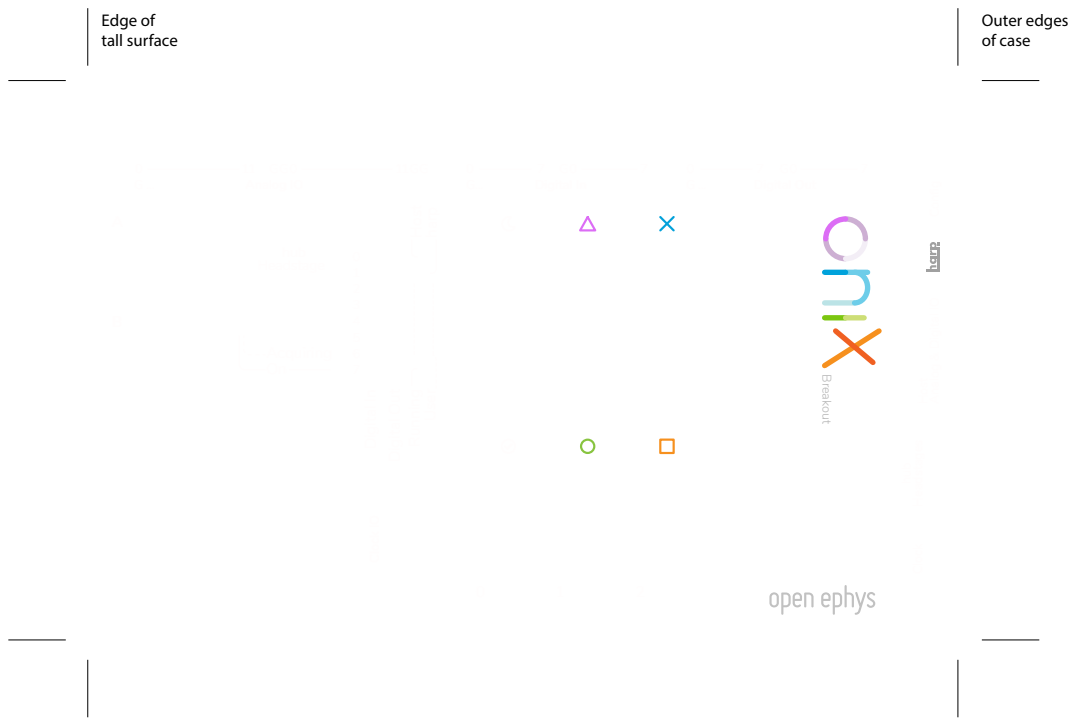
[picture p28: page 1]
Outer edges of case; Edge of tall surface; Breakout; Clock Host; 11 G G Digital In Digital Out Clock IO; Running User Host harp; 210ABCD; Analog IO; Digital In; Digital Out; hub Headstage; hub; Headstages; Acquiring On

Analog & Digital IO Config

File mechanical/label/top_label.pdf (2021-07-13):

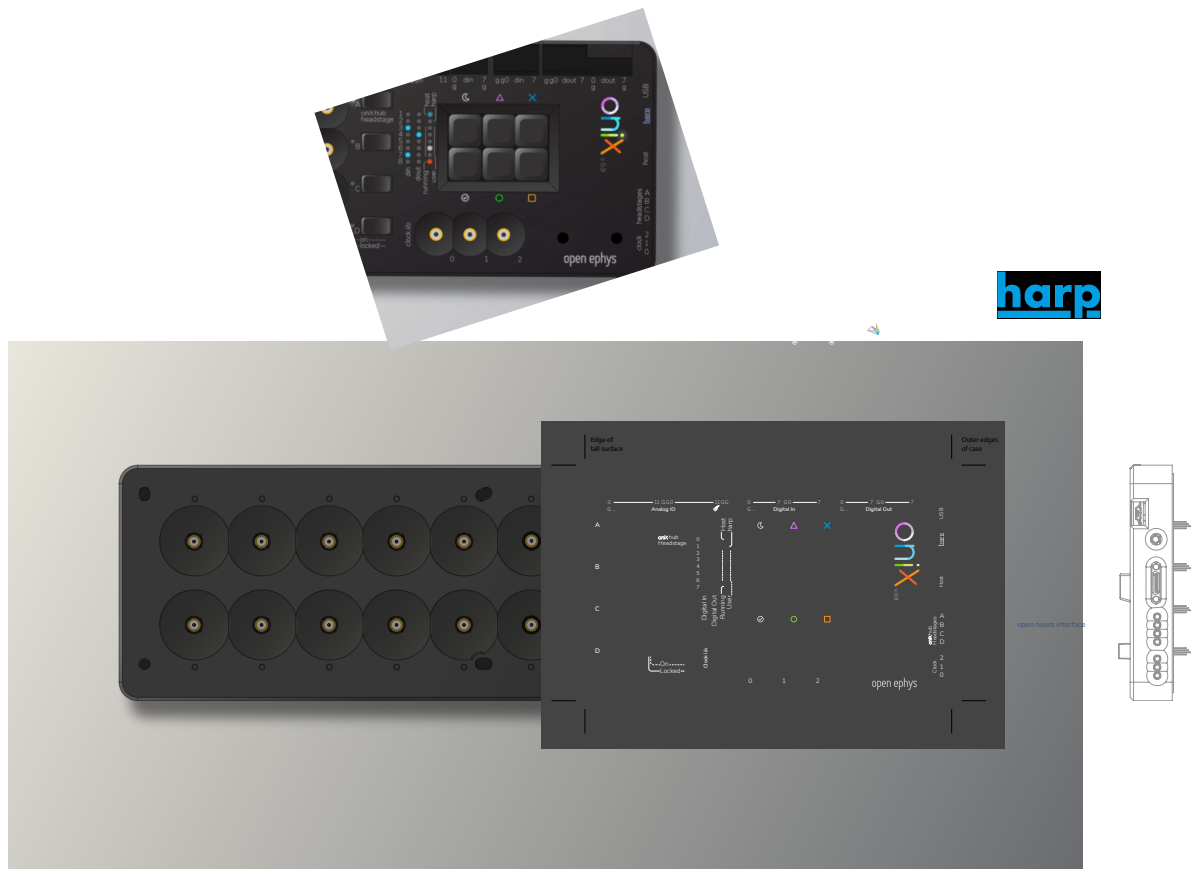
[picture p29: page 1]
Outer edges of case; Edge of tall surface; Clock; Host USB; On Locked; 11 G G Digital In Digital Out Clock i/o; Running User Host harp; Analog IO; Digital In; Digital Out; hub Headstage; hub; Headstages

open neuro interface

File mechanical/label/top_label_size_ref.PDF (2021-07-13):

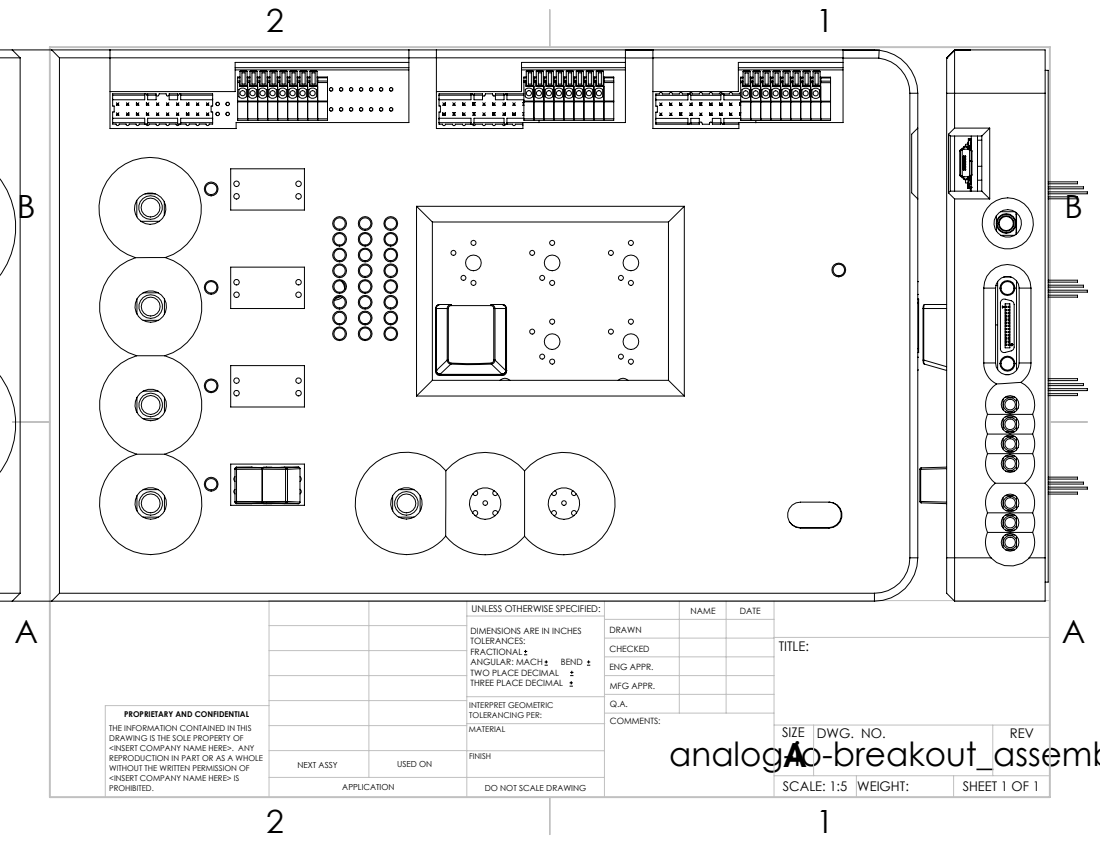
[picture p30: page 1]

UNLESS OTHERWISE SPECIFIED: | | NAME | DATE
DIMENSIONS ARE IN INCHES TOLERANCES: FRACTIONAL ANGULAR: MACH BEND TWO PLACE DECIMAL THREE PLACE DECIMAL | DRAWN

CHECKED | | | TITLE:

ENG APPR.
MFG APPR.

INTERPRET GEOMETRIC TOLERANCING PER: | Q.A.
MATERIAL | | SIZE A | DWG. NO. | REV

PROPRIETARY AND CONFIDENTIAL
THE INFORMATION CONTAINED IN THIS
DRAWING IS THE SOLE PROPERTY OF
<INSERT COMPANY NAME HERE>. ANY
REPRODUCTION IN PART OR AS A WHOLE
WITHOUT THE WRITTEN PERMISSION OF
<INSERT COMPANY NAME HERE> IS
PROHIBITED.

NEXT ASSY | USED ON | FINISH

APPLICATION | DO NOT SCALE DRAWING | | SCALE: 1:5 | WEIGHT: | SHEET 1 OF 1

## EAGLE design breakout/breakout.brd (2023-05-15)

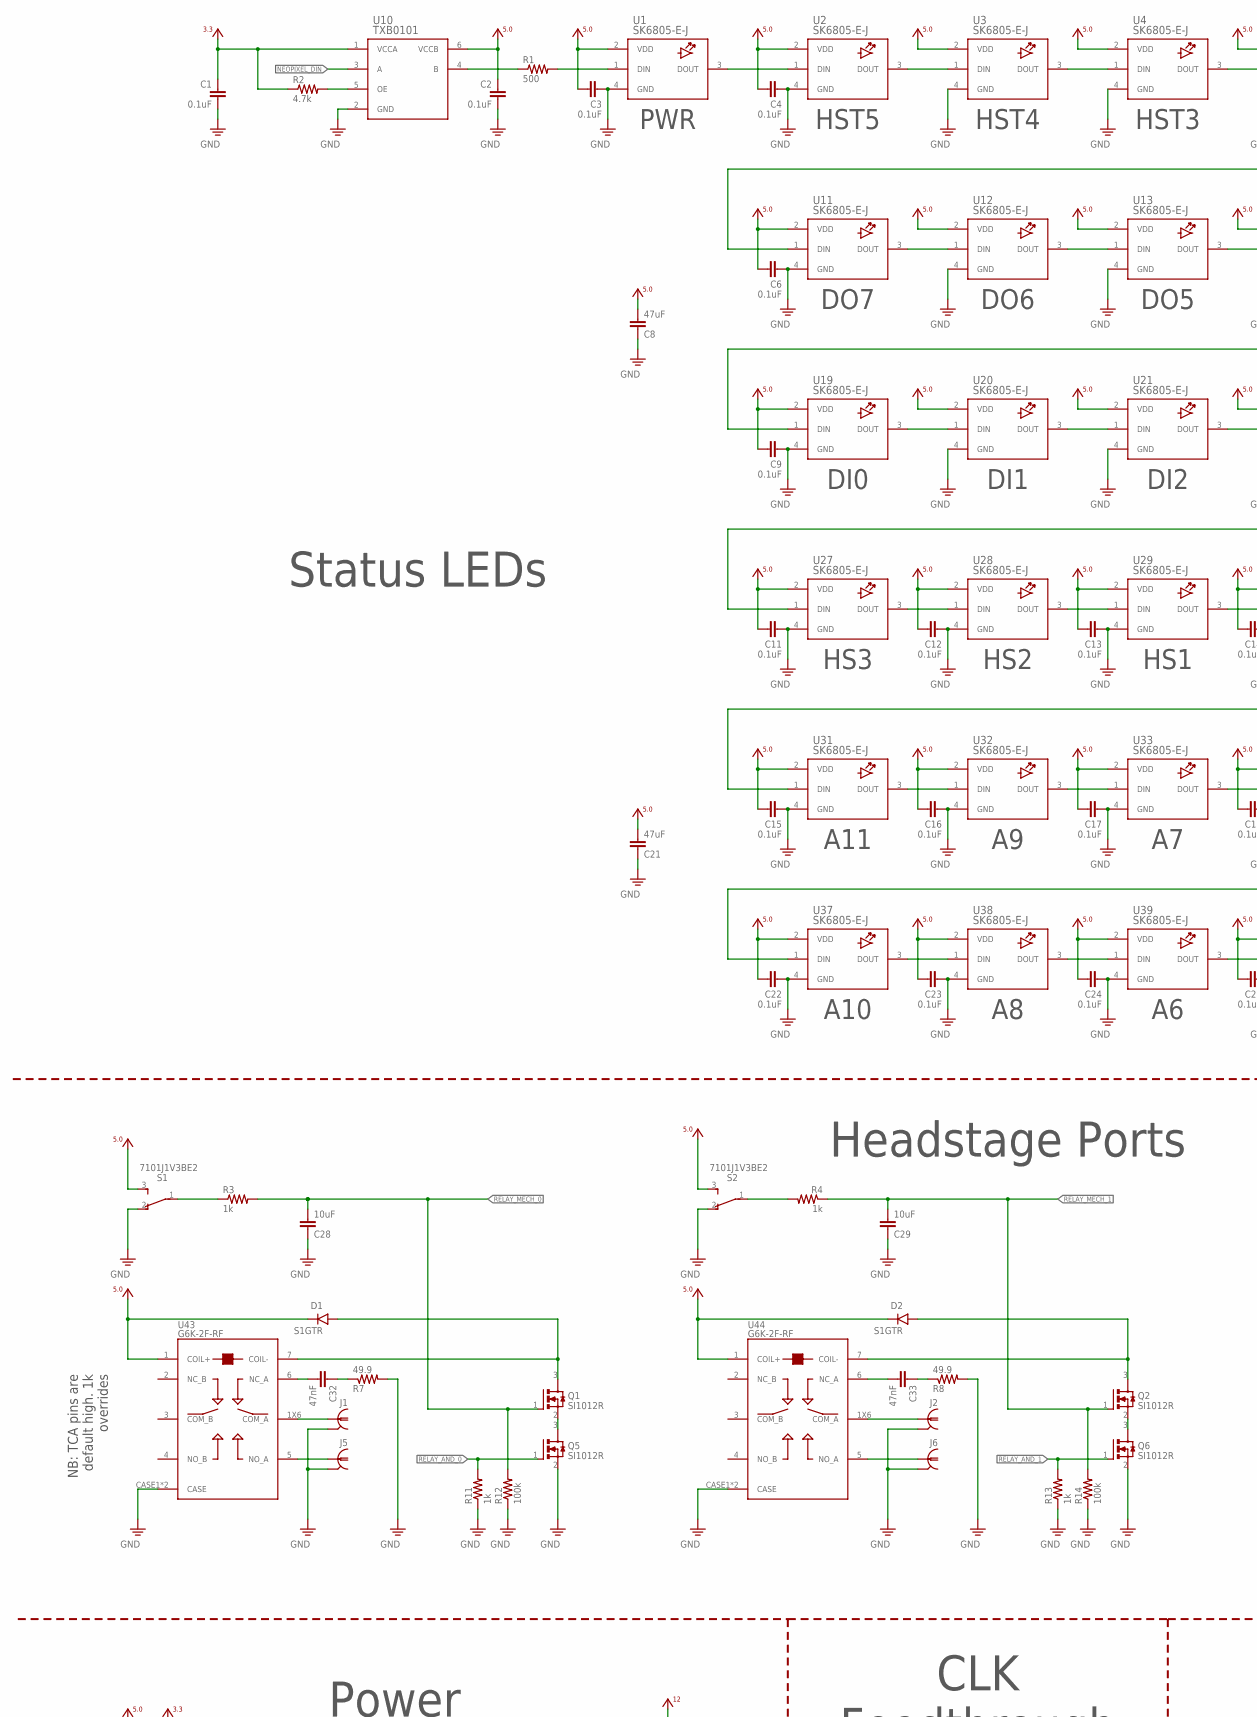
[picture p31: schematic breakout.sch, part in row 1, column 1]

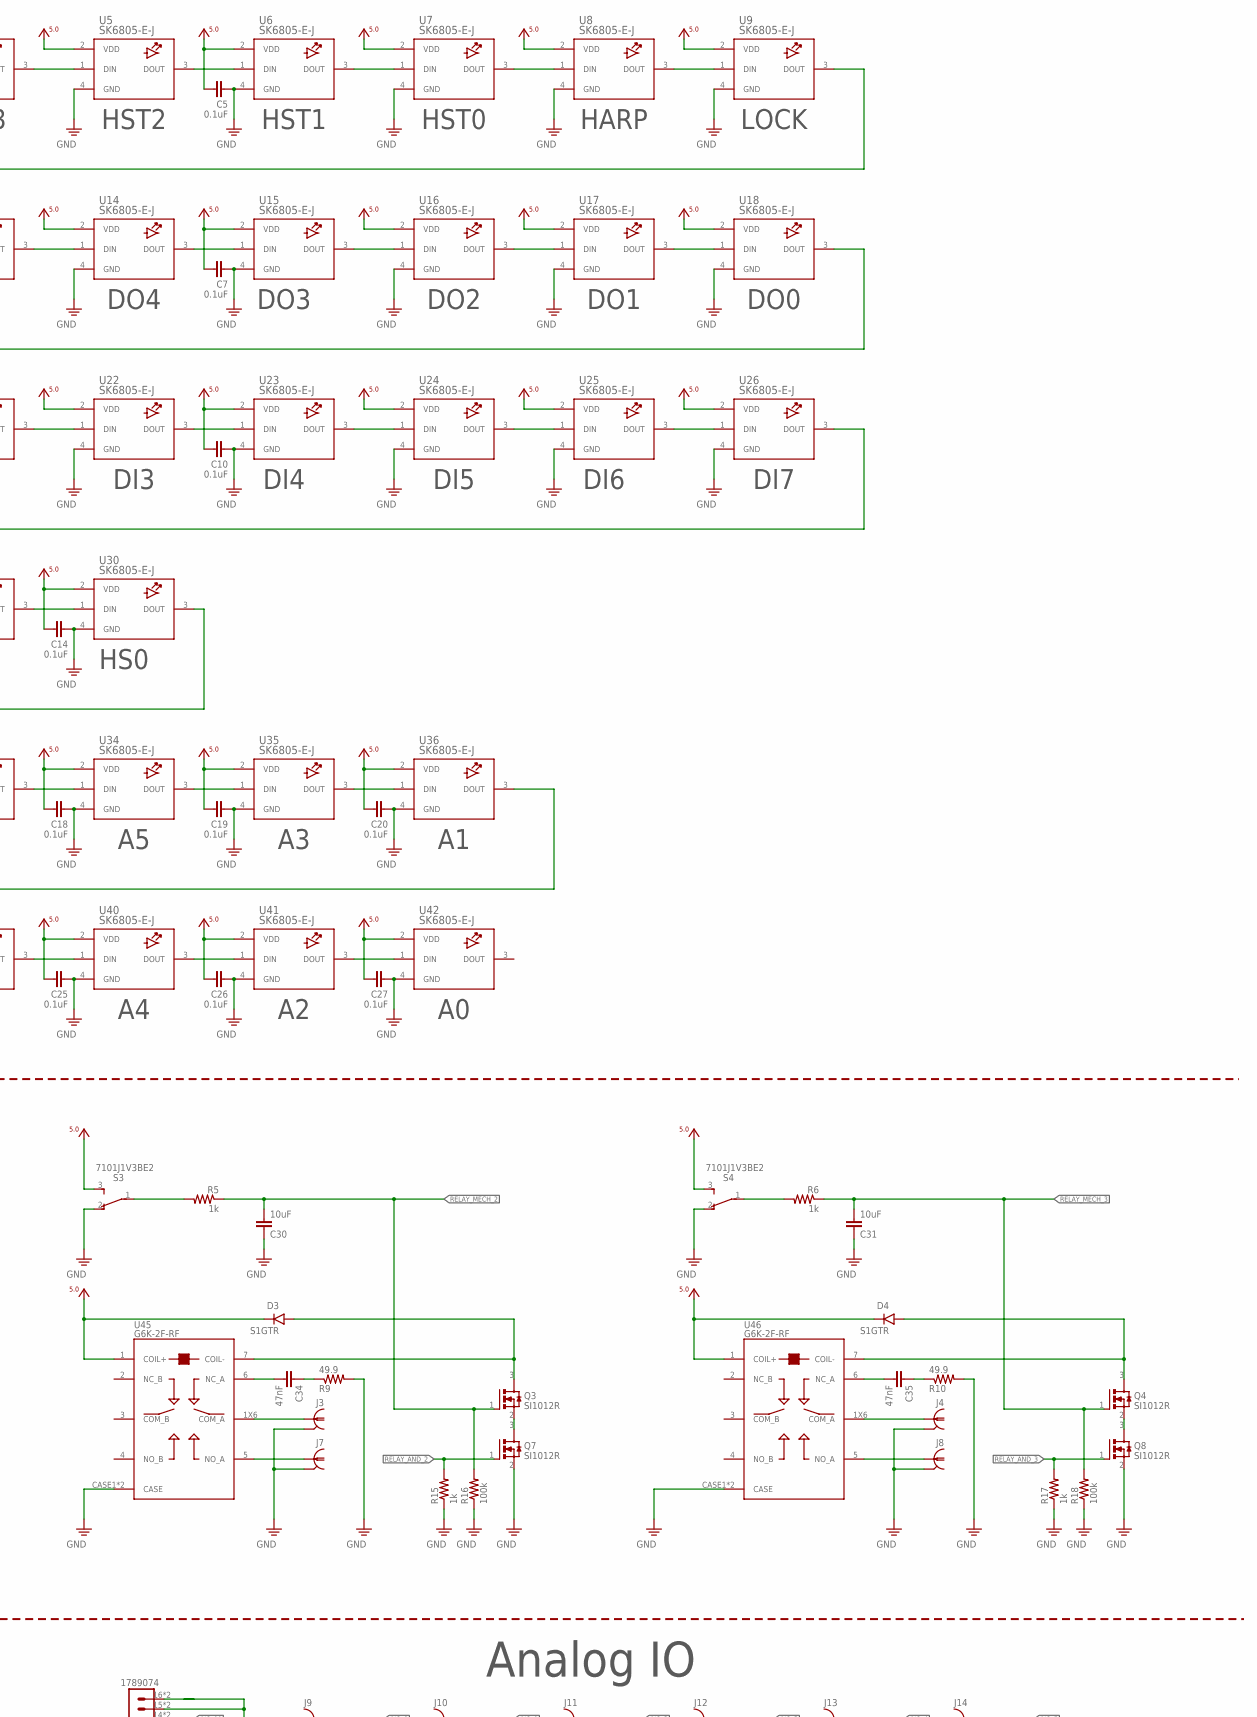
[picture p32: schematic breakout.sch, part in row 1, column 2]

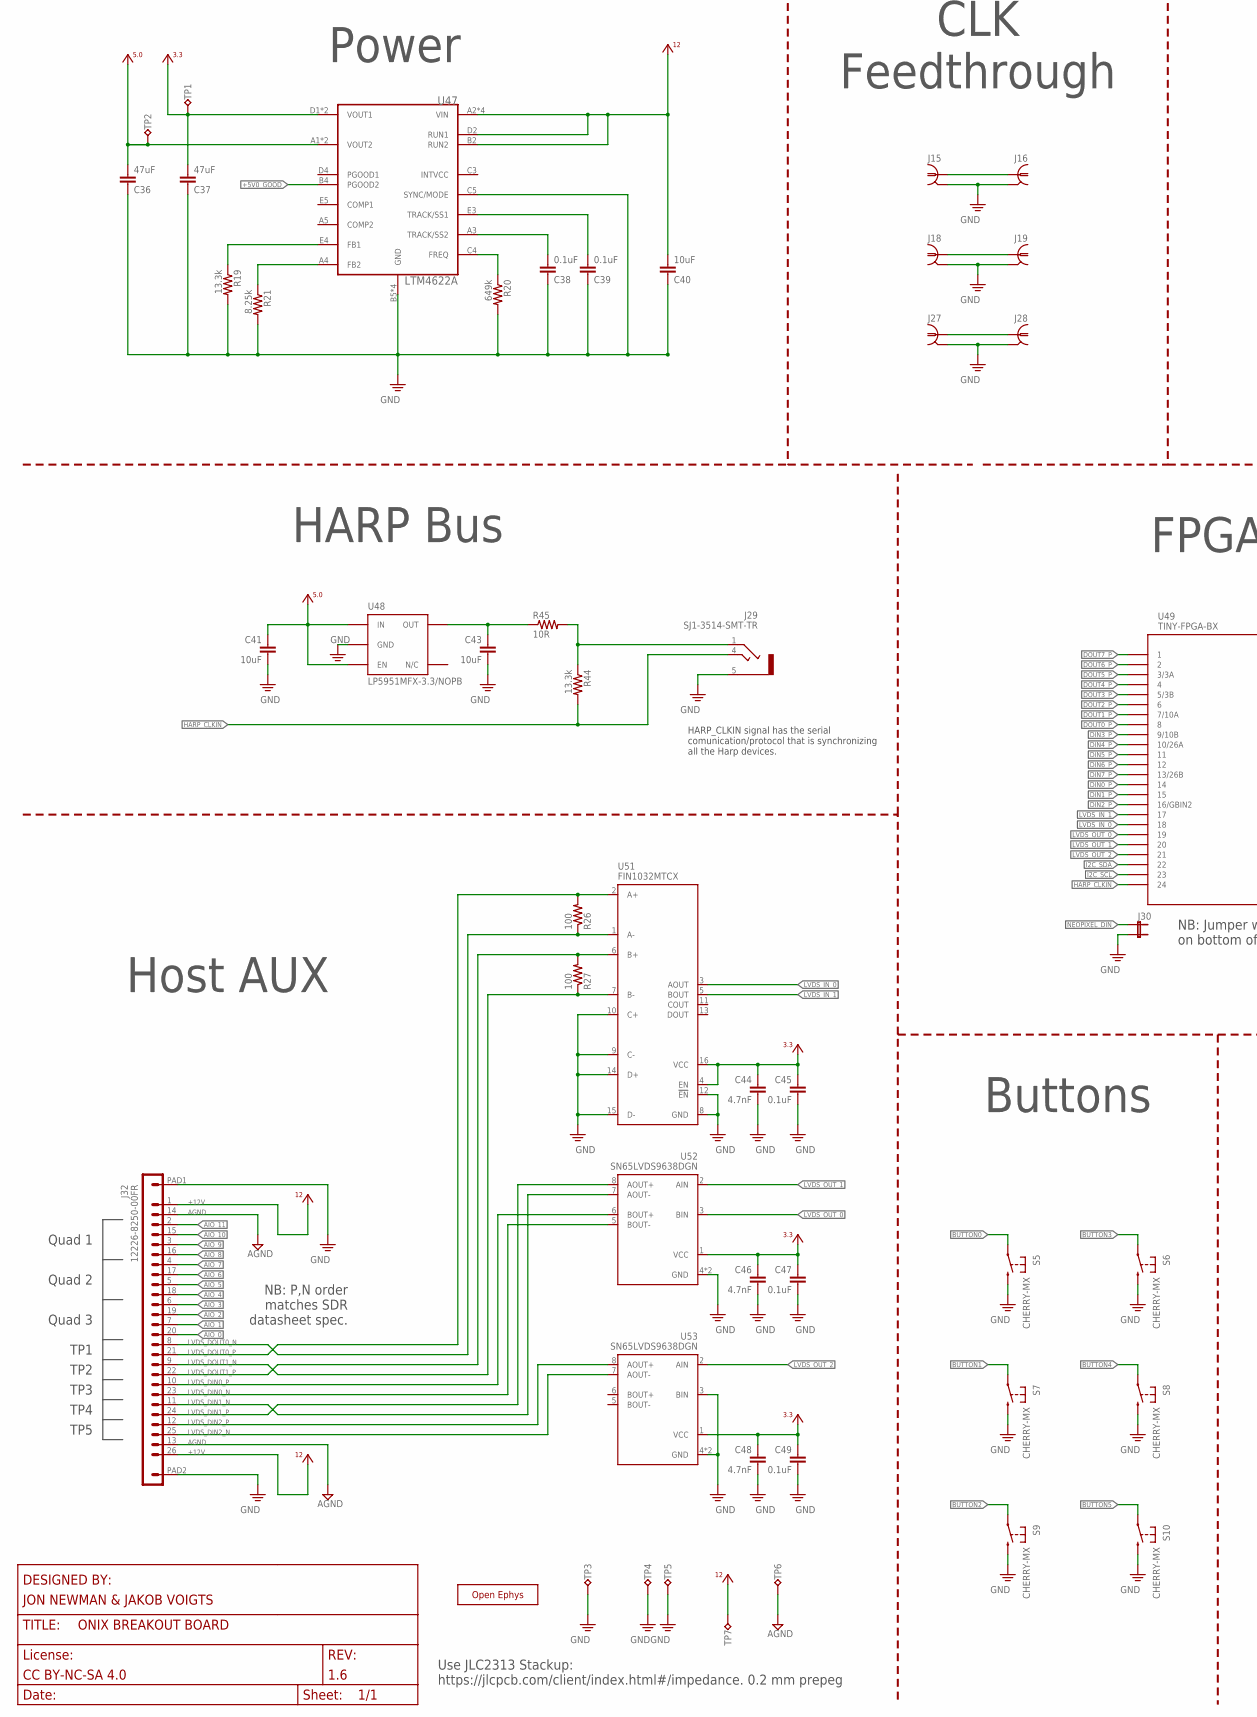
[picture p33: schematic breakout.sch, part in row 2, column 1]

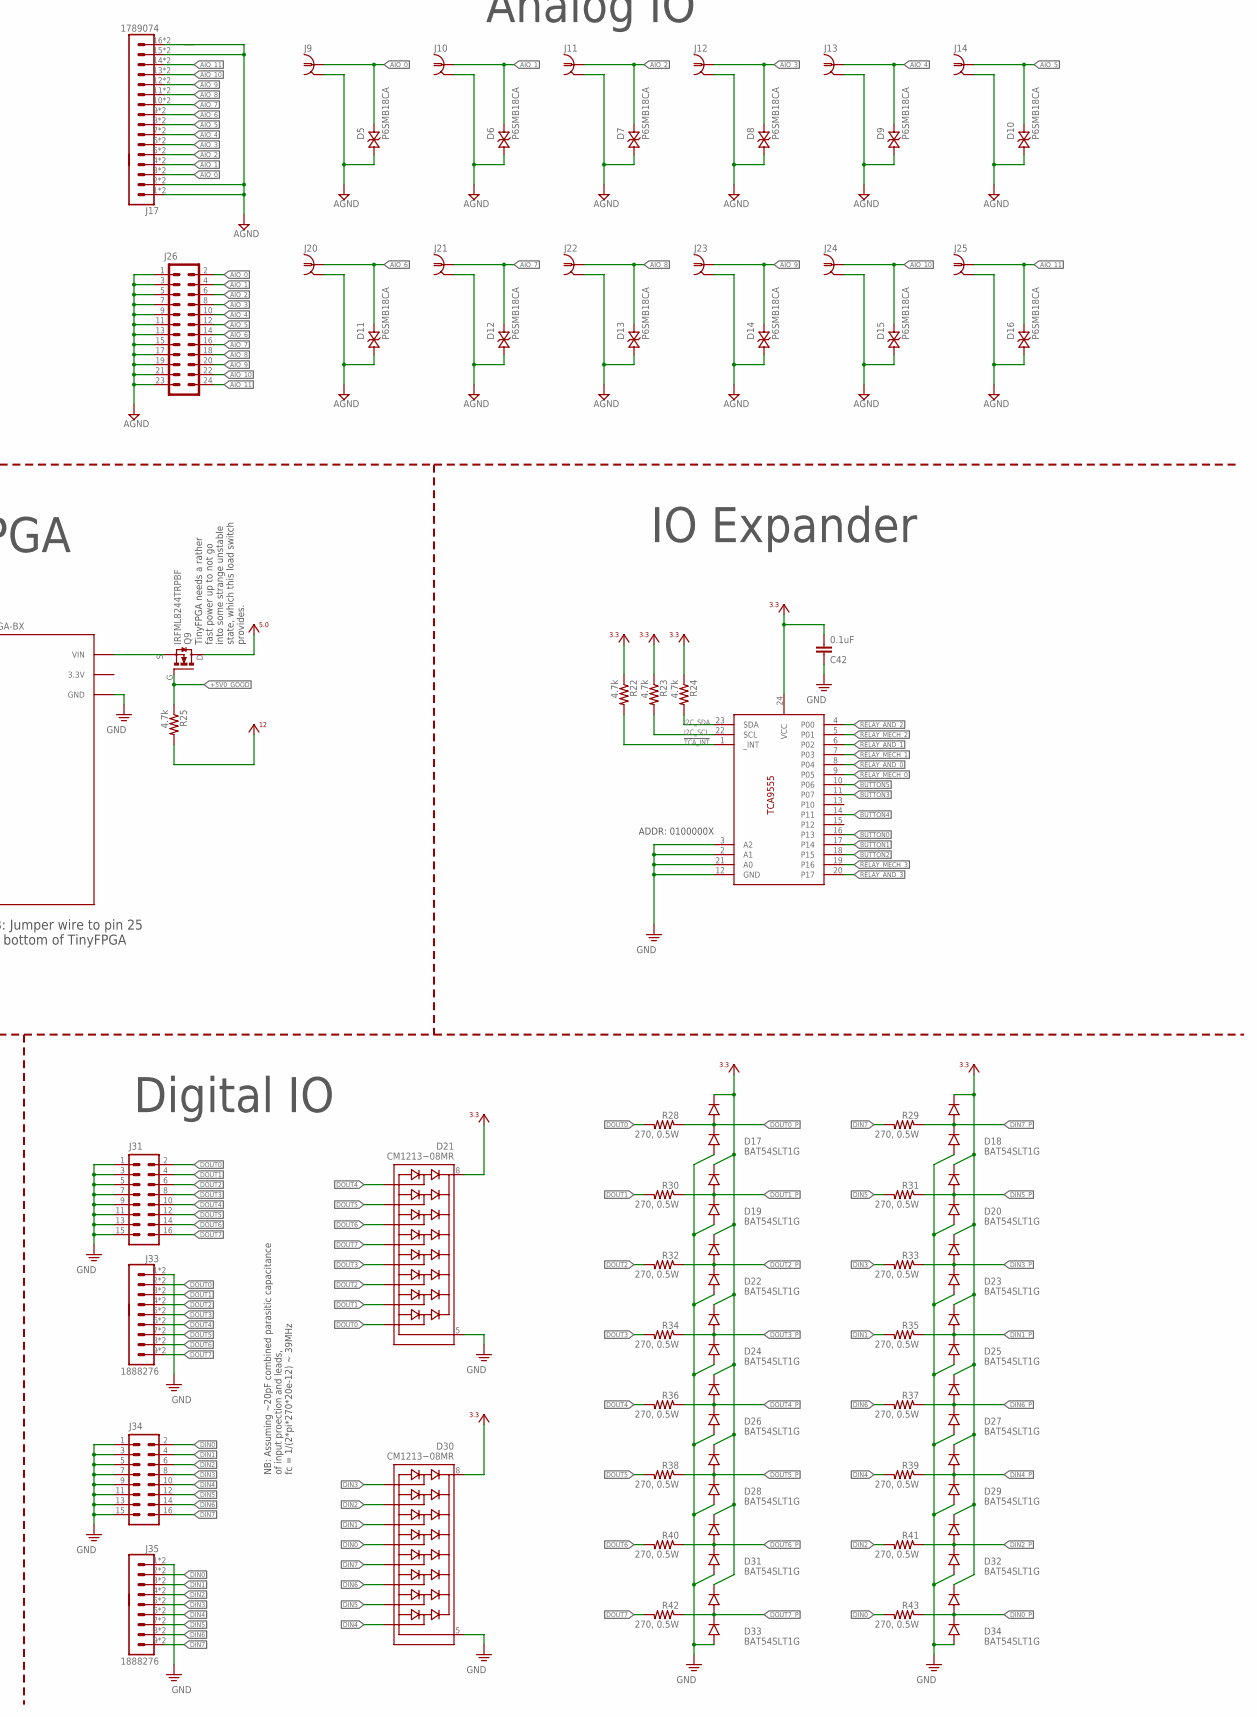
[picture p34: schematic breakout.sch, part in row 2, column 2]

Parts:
C1, C2, C3, C4, C5, C6, C7, C9, C10, C11, C12, C13, C14, C15, C16, C17, C18, C19, C20, C22, C23, C24, C25, C26, C27, C38, C39, C42, C45, C47, C49: 0.1uF; 0402
C8, C21, C36, C37: 47uF; 1210
C28, C29, C30, C31, C40, C41, C43: 10uF; 0805
C32, C33, C34, C35: 47nF; 0402
C44, C46, C48: 4.7nF; 0402
D1, D2, D3, D4: S1GTR; SMA-DO214AC
D5, D6, D7, D8, D9, D10, D11, D12, D13, D14, D15, D16: P6SMB18CA; SMA-DO214AC
D17, D18, D19, D20, D22, D23, D24, D25, D26, D27, D28, D29, D31, D32, D33, D34: BAT54SLT1G; SOT23
D21, D30: CM1213−08MR; MSOP-10-3X3
J1, J2, J3, J4, J16, J19, J28: COAX_SMA-VERT; SMA_JACK_142-0701-201
J5, J6, J7, J8, J15, J18, J27: COAX_MMCX-THRU; MMCX-THRU
J9, J10, J11, J12, J13, J14, J20, J21, J22, J23, J24, J25: COAX_0731010360; 0731010360
J17: 1789074; SCREW16-2
J26: 69168-124HLF; 2X12-BIG
J29: SJ1-3514-SMT-TR; 35RASMT2BHNTRX
J30: JP2E_THRU-HOLE; JP2
J31, J34: 69168-116HLF; 2X08-BIG
J32: 12226-8250-00FR; 12226-82X0-00XX
J33, J35: 1888276; SCREW9-2
Q1, Q2, Q3, Q4, Q5, Q6, Q7, Q8: SI1012R; SC75
Q9: IRFML8244TRPBF; SOT23-GSD
R1: 500; 0402
R2, R22, R23, R24, R25: 4.7k; 0402
R3, R4, R5, R6, R11, R13, R15, R17: 1k; 0402
R7, R8, R9, R10: 49.9; 0402
R12, R14, R16, R18: 100k; 0402
R19, R44: 13.3k; 0402
R20: 649k; 0402
R21: 8.25k; 0402
R26, R27: 100; 0402
R28, R29, R30, R31, R32, R33, R34, R35, R36, R37, R38, R39, R40, R41, R42, R43: 270, 0.5W; 0805
R45: 10R; 0402
S1, S2, S3, S4: 7101J1V3BE2; CK_7101J1V3QE2
S5, S6, S7, S8, S9, S10: CHERRY-MX
TP1, TP2: TPTP19R; TP19R
TP3, TP4, TP5, TP6, TP7: TP_2MM; TESTPOINT_2MM
U1, U2, U3, U4, U5, U6, U7, U8, U9, U11, U12, U13, U14, U15, U16, U17, U18, U19, U20, U21, U22, U23, U24, U25, U26, U27, U28, U29, U30, U31, U32, U33, U34, U35, U36, U37, U38, U39, U40, U41, U42: SK6805-E-J; NEOPIXEL-1.5X1.5
U10: TXB0101; SOT23-6
U43, U44, U45, U46: G6K-2F-RF; G6KU-2F-RF
U47: LTM4622A; BGA_5X5_625X625
U48: LP5951MFX-3.3/NOPB; TSOT23-5; MPN TLV70033DDCR
U49: TINY-FPGA-BX; TINY-FPGA-BX_BASIC
U50: TCA9555; TSSOP-24
U51: FIN1032MTCX; TSSOP-16
U52, U53: SN65LVDS9638DGN; MSOP-8-PAD-3X3
X: OE-LOGO_28X20; OE-LOGO-28X20

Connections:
!TCA_INT: R22.2, U50.1 (_INT)
+3V3: C1.1, C37.2, C42.2, C44.1, C45.1, C46.1, C47.1, C48.1, C49.1, D17.2 (C), D18.2 (C), D19.2 (C), D20.2 (C), D21.8 (VCC), D22.2 (C), D23.2 (C), D24.2 (C), D25.2 (C), D26.2 (C), D27.2 (C), D28.2 (C), D29.2 (C), D30.8 (VCC), D31.2 (C), D32.2 (C), D33.2 (C), D34.2 (C), R2.1, R22.1, R23.1, R24.1, TP1.TP, U10.1 (VCCA), U47.D1 (VOUT1), U47.E1 (VOUT1), U50.24 (VCC), U51.4 (EN), U51.16 (VCC), U52.1 (VCC), U53.1 (VCC)
+5V0: C2.1, C3.2, C4.2, C5.2, C6.2, C7.2, C8.2, C9.2, C10.2, C11.2, C12.2, C13.2, C14.2, C15.2, C16.2, C17.2, C18.2, C19.2, C20.2, C21.2, C22.2, C23.2, C24.2, C25.2, C26.2, C27.2, C36.2, C41.1, D1.C, D2.C, D3.C, D4.C, Q9.D, S1.3, S2.3, S3.3, S4.3, TP2.TP, U1.2 (VDD), U2.2 (VDD), U3.2 (VDD), U4.2 (VDD), U5.2 (VDD), U6.2 (VDD), U7.2 (VDD), U8.2 (VDD), U9.2 (VDD), U10.6 (VCCB), U11.2 (VDD), U12.2 (VDD), U13.2 (VDD), U14.2 (VDD), U15.2 (VDD), U16.2 (VDD), U17.2 (VDD), U18.2 (VDD), U19.2 (VDD), U20.2 (VDD), U21.2 (VDD), U22.2 (VDD), U23.2 (VDD), U24.2 (VDD), U25.2 (VDD), U26.2 (VDD), U27.2 (VDD), U28.2 (VDD), U29.2 (VDD), U30.2 (VDD), U31.2 (VDD), U32.2 (VDD), U33.2 (VDD), U34.2 (VDD), U35.2 (VDD), U36.2 (VDD), U37.2 (VDD), U38.2 (VDD), U39.2 (VDD), U40.2 (VDD), U41.2 (VDD), U42.2 (VDD), U43.1 (COIL+), U44.1 (COIL+), U45.1 (COIL+), U46.1 (COIL+), U47.A1 (VOUT2), U47.B1 (VOUT2), U48.1 (IN), U48.3 (EN)
+5V0_GOOD: Q9.G, R25.1, U47.B4 (PGOOD2)
+12V: C40.2, J32.1, J32.26, R25.2, TP7.1, U47.A2 (VIN), U47.B2 (RUN2), U47.B3 (VIN), U47.D2 (RUN1), U47.D3 (VIN), U47.E2 (VIN)
AGND: D5.A (1), D6.A (1), D7.A (1), D8.A (1), D9.A (1), D10.A (1), D11.A (1), D12.A (1), D13.A (1), D14.A (1), D15.A (1), D16.A (1), J9.2, J9.3 (2), J9.4 (2), J9.5 (2), J10.2, J10.3 (2), J10.4 (2), J10.5 (2), J11.2, J11.3 (2), J11.4 (2), J11.5 (2), J12.2, J12.3 (2), J12.4 (2), J12.5 (2), J13.2, J13.3 (2), J13.4 (2), J13.5 (2), J14.2, J14.3 (2), J14.4 (2), J14.5 (2), J17.1, J17.2, J17.15, J17.16, J17.17 (1), J17.18 (2), J17.31 (15), J17.32 (16), J20.2, J20.3 (2), J20.4 (2), J20.5 (2), J21.2, J21.3 (2), J21.4 (2), J21.5 (2), J22.2, J22.3 (2), J22.4 (2), J22.5 (2), J23.2, J23.3 (2), J23.4 (2), J23.5 (2), J24.2, J24.3 (2), J24.4 (2), J24.5 (2), J25.2, J25.3 (2), J25.4 (2), J25.5 (2), J26.1, J26.3, J26.5, J26.7, J26.9, J26.11, J26.13, J26.15, J26.17, J26.19, J26.21, J26.23, J32.13, J32.14, TP6.1
AIO_0: D5.C (2), J9.1, J17.3, J17.19 (3), J26.2, J32.20
AIO_1: D6.C (2), J10.1, J17.4, J17.20 (4), J26.4, J32.7
AIO_2: D7.C (2), J11.1, J17.5, J17.21 (5), J26.6, J32.19
AIO_3: D8.C (2), J12.1, J17.6, J17.22 (6), J26.8, J32.6
AIO_4: D9.C (2), J13.1, J17.7, J17.23 (7), J26.10, J32.18
AIO_5: D10.C (2), J14.1, J17.8, J17.24 (8), J26.12, J32.5
AIO_6: D11.C (2), J17.9, J17.25 (9), J20.1, J26.14, J32.17
AIO_7: D12.C (2), J17.10, J17.26 (10), J21.1, J26.16, J32.4
AIO_8: D13.C (2), J17.11, J17.27 (11), J22.1, J26.18, J32.16
AIO_9: D14.C (2), J17.12, J17.28 (12), J23.1, J26.20, J32.3
AIO_10: D15.C (2), J17.13, J17.29 (13), J24.1, J26.22, J32.15
AIO_11: D16.C (2), J17.14, J17.30 (14), J25.1, J26.24, J32.2
BUTTON0: S5.SW1, U50.16 (P13)
BUTTON1: S7.SW1, U50.17 (P14)
BUTTON2: S9.SW1, U50.18 (P15)
BUTTON3: S6.SW1, U50.11 (P07)
BUTTON4: S8.SW1, U50.14 (P11)
BUTTON5: S10.SW1, U50.10 (P06)
DIN0: D30.4 (CH4), J34.2, J35.2, J35.11 (2), R43.2
DIN0_P: D34.3 (COMM), R43.1, U49.14
DIN1: D30.3 (CH3), J34.4, J35.3, J35.12 (3), R35.2
DIN1_P: D25.3 (COMM), R35.1, U49.15
DIN2: D30.2 (CH2), J34.6, J35.4, J35.13 (4), R41.2
DIN2_P: D32.3 (COMM), R41.1, U49.16 (16/GBIN2)
DIN3: D30.1 (CH1), J34.8, J35.5, J35.14 (5), R33.2
DIN3_P: D23.3 (COMM), R33.1, U49.9 (9/10B)
DIN4: D30.10 (CH8), J34.10, J35.6, J35.15 (6), R39.2
DIN4_P: D29.3 (COMM), R39.1, U49.10 (10/26A)
DIN5: D30.9 (CH7), J34.12, J35.7, J35.16 (7), R31.2
DIN5_P: D20.3 (COMM), R31.1, U49.11
DIN6: D30.7 (CH6), J34.14, J35.8, J35.17 (8), R37.2
DIN6_P: D27.3 (COMM), R37.1, U49.12
DIN7: D30.6 (CH5), J34.16, J35.9, J35.18 (9), R29.2
DIN7_P: D18.3 (COMM), R29.1, U49.13 (13/26B)
DOUT0: D21.10 (CH8), J31.2, J33.2, J33.11 (2), R28.2
DOUT0_P: D17.3 (COMM), R28.1, U49.8
DOUT1: D21.9 (CH7), J31.4, J33.3, J33.12 (3), R30.2
DOUT1_P: D19.3 (COMM), R30.1, U49.7 (7/10A)
DOUT2: D21.7 (CH6), J31.6, J33.4, J33.13 (4), R32.2
DOUT2_P: D22.3 (COMM), R32.1, U49.6
DOUT3: D21.6 (CH5), J31.8, J33.5, J33.14 (5), R34.2
DOUT3_P: D24.3 (COMM), R34.1, U49.5 (5/3B)
DOUT4: D21.1 (CH1), J31.10, J33.6, J33.15 (6), R36.2
DOUT4_P: D26.3 (COMM), R36.1, U49.4
DOUT5: D21.2 (CH2), J31.12, J33.7, J33.16 (7), R38.2
DOUT5_P: D28.3 (COMM), R38.1, U49.3 (3/3A)
DOUT6: D21.3 (CH3), J31.14, J33.8, J33.17 (8), R40.2
DOUT6_P: D31.3 (COMM), R40.1, U49.2
DOUT7: D21.4 (CH4), J31.16, J33.9, J33.18 (9), R42.2
DOUT7_P: D33.3 (COMM), R42.1, U49.1
GND: C1.2, C2.2, C3.1, C4.1, C5.1, C6.1, C7.1, C8.1, C9.1, C10.1, C11.1, C12.1, C13.1, C14.1, C15.1, C16.1, C17.1, C18.1, C19.1, C20.1, C21.1, C22.1, C23.1, C24.1, C25.1, C26.1, C27.1, C28.1, C29.1, C30.1, C31.1, C36.1, C37.1, C38.1, C39.1, C40.1, C41.2, C42.1, C43.2, C44.2, C45.2, C46.2, C47.2, C48.2, C49.2, D17.1 (A), D18.1 (A), D19.1 (A), D20.1 (A), D21.5 (VSS), D22.1 (A), D23.1 (A), D24.1 (A), D25.1 (A), D26.1 (A), D27.1 (A), D28.1 (A), D29.1 (A), D30.5 (VSS), D31.1 (A), D32.1 (A), D33.1 (A), D34.1 (A), J1.GND$1 (2), J1.GND$2 (2), J1.GND$3 (2), J1.GND$4 (2), J2.GND$1 (2), J2.GND$2 (2), J2.GND$3 (2), J2.GND$4 (2), J3.GND$1 (2), J3.GND$2 (2), J3.GND$3 (2), J3.GND$4 (2), J4.GND$1 (2), J4.GND$2 (2), J4.GND$3 (2), J4.GND$4 (2), J5.GND@1 (2), J5.GND@2 (2), J5.GND@3 (2), J5.GND@4 (2), J6.GND@1 (2), J6.GND@2 (2), J6.GND@3 (2), J6.GND@4 (2), J7.GND@1 (2), J7.GND@2 (2), J7.GND@3 (2), J7.GND@4 (2), J8.GND@1 (2), J8.GND@2 (2), J8.GND@3 (2), J8.GND@4 (2), J15.GND@1 (2), J15.GND@2 (2), J15.GND@3 (2), J15.GND@4 (2), J16.GND$1 (2), J16.GND$2 (2), J16.GND$3 (2), J16.GND$4 (2), J18.GND@1 (2), J18.GND@2 (2), J18.GND@3 (2), J18.GND@4 (2), J19.GND$1 (2), J19.GND$2 (2), J19.GND$3 (2), J19.GND$4 (2), J27.GND@1 (2), J27.GND@2 (2), J27.GND@3 (2), J27.GND@4 (2), J28.GND$1 (2), J28.GND$2 (2), J28.GND$3 (2), J28.GND$4 (2), J29.5, J30.2, J31.1, J31.3, J31.5, J31.7, J31.9, J31.11, J31.13, J31.15, J32.PAD1, J32.PAD2, J33.1, J33.10 (1), J34.1, J34.3, J34.5, J34.7, J34.9, J34.11, J34.13, J34.15, J35.1, J35.10 (1), Q5.2 (S), Q6.2 (S), Q7.2 (S), Q8.2 (S), R7.2, R8.2, R9.2, R10.2, R11.1, R12.1, R13.1, R14.1, R15.1, R16.1, R17.1, R18.1, R19.2, R20.2, R21.2, S1.2 (1), S2.2 (1), S3.2 (1), S4.2 (1), S5.SW2 (S), S6.SW2 (S), S7.SW2 (S), S8.SW2 (S), S9.SW2 (S), S10.SW2 (S), TP3.1, TP4.1, TP5.1, U1.4 (GND), U2.4 (GND), U3.4 (GND), U4.4 (GND), U5.4 (GND), U6.4 (GND), U7.4 (GND), U8.4 (GND), U9.4 (GND), U10.2 (GND), U11.4 (GND), U12.4 (GND), U13.4 (GND), U14.4 (GND), U15.4 (GND), U16.4 (GND), U17.4 (GND), U18.4 (GND), U19.4 (GND), U20.4 (GND), U21.4 (GND), U22.4 (GND), U23.4 (GND), U24.4 (GND), U25.4 (GND), U26.4 (GND), U27.4 (GND), U28.4 (GND), U29.4 (GND), U30.4 (GND), U31.4 (GND), U32.4 (GND), U33.4 (GND), U34.4 (GND), U35.4 (GND), U36.4 (GND), U37.4 (GND), U38.4 (GND), U39.4 (GND), U40.4 (GND), U41.4 (GND), U42.4 (GND), U43.CASE1 (CASE), U43.CASE2 (CASE), U44.CASE1 (CASE), U44.CASE2 (CASE), U45.CASE1 (CASE), U45.CASE2 (CASE), U46.CASE1 (CASE), U46.CASE2 (CASE), U47.B5 (GND), U47.C1 (GND), U47.C2 (GND), U47.C5 (SYNC/MODE), U47.D5 (GND), U48.2 (GND), U49.GND@1 (GND), U49.GND@2 (GND), U50.2 (A1), U50.3 (A2), U50.12 (GND), U50.21 (A0), U51.8 (GND), U51.9 (C-), U51.10 (C+), U51.12 (!EN), U51.14 (D+), U51.15 (D-), U52.4 (GND), U52.PAD (GND), U53.3 (BIN), U53.4 (GND), U53.PAD (GND)
HARP_CLKIN: J29.4, R44.2, U49.24
I2C_SCL: R23.2, U49.23, U50.22 (SCL)
I2C_SDA: R24.2, U49.22, U50.23 (SDA)
LOCKED: U9.3 (DOUT), U11.1 (DIN)
LVDS_DIN0_N: J32.23, U52.5 (BOUT-)
LVDS_DIN0_P: J32.10, U52.6 (BOUT+)
LVDS_DIN1_N: J32.11, U52.7 (AOUT-)
LVDS_DIN1_P: J32.24, U52.8 (AOUT+)
LVDS_DIN2_N: J32.25, U53.7 (AOUT-)
LVDS_DIN2_P: J32.12, U53.8 (AOUT+)
LVDS_DOUT0_N: J32.8, R26.1, U51.1 (A-)
LVDS_DOUT0_P: J32.21, R26.2, U51.2 (A+)
LVDS_DOUT1_N: J32.9, R27.1, U51.7 (B-)
LVDS_DOUT1_P: J32.22, R27.2, U51.6 (B+)
LVDS_IN_0: U49.18, U51.3 (AOUT)
LVDS_IN_1: U49.17, U51.5 (BOUT)
LVDS_OUT_0: U49.19, U52.3 (BIN)
LVDS_OUT_1: U49.20, U52.2 (AIN)
LVDS_OUT_2: U49.21, U53.2 (AIN)
unnamed: J15.SIG (1), J16.CLK (1)
unnamed: J18.SIG (1), J19.CLK (1)
unnamed: J27.SIG (1), J28.CLK (1)
unnamed: D1.A, Q1.3 (D), U43.7 (COIL-)
unnamed: Q1.2 (S), Q5.3 (D)
unnamed: U11.3 (DOUT), U12.1 (DIN)
unnamed: U12.3 (DOUT), U13.1 (DIN)
unnamed: U13.3 (DOUT), U14.1 (DIN)
unnamed: U36.3 (DOUT), U37.1 (DIN)
unnamed: U31.3 (DOUT), U32.1 (DIN)
unnamed: D2.A, Q2.3 (D), U44.7 (COIL-)
unnamed: U15.3 (DOUT), U16.1 (DIN)
unnamed: U16.3 (DOUT), U17.1 (DIN)
unnamed: C32.2, U43.6 (NC_A)
unnamed: J29.1, R44.1, R45.2
unnamed: J6.SIG (1), U44.5 (NO_A)
unnamed: U17.3 (DOUT), U18.1 (DIN)
unnamed: U1.3 (DOUT), U2.1 (DIN)
unnamed: C33.1, R8.1
unnamed: R3.1, S1.1 (2)
unnamed: R21.1, U47.A4 (FB2)
unnamed: R19.1, U47.E4 (FB1)
unnamed: C38.2, U47.A3 (TRACK/SS2)
unnamed: C39.2, U47.E3 (TRACK/SS1)
unnamed: J5.SIG (1), U43.5 (NO_A)
unnamed: J1.CLK (1), U43.1X6 (COM_A)
unnamed: C32.1, R7.1
unnamed: C33.2, U44.6 (NC_A)
unnamed: Q3.2 (S), Q7.3 (D)
unnamed: C34.1, R9.1
unnamed: J2.CLK (1), U44.1X6 (COM_A)
unnamed: R4.2, S2.1 (2)
unnamed: C34.2, U45.6 (NC_A)
unnamed: J7.SIG (1), U45.5 (NO_A)
unnamed: R5.2, S3.1 (2)
unnamed: Q2.2 (S), Q6.3 (D)
unnamed: U2.3 (DOUT), U3.1 (DIN)
unnamed: U3.3 (DOUT), U4.1 (DIN)
unnamed: J3.CLK (1), U45.1X6 (COM_A)
unnamed: R6.2, S4.1 (2)
unnamed: C35.1, R10.1
unnamed: C35.2, U46.6 (NC_A)
unnamed: J8.SIG (1), U46.5 (NO_A)
unnamed: J4.CLK (1), U46.1X6 (COM_A)
unnamed: U4.3 (DOUT), U5.1 (DIN)
unnamed: D3.A, Q3.3 (D), U45.7 (COIL-)
unnamed: U6.3 (DOUT), U7.1 (DIN)
unnamed: U7.3 (DOUT), U8.1 (DIN)
unnamed: U8.3 (DOUT), U9.1 (DIN)
unnamed: R1.2, U1.1 (DIN)
unnamed: R1.1, U10.4 (B)
unnamed: U5.3 (DOUT), U6.1 (DIN)
unnamed: R2.2, U10.5 (OE)
unnamed: U14.3 (DOUT), U15.1 (DIN)
unnamed: D4.A, Q4.3 (D), U46.7 (COIL-)
unnamed: Q4.2 (S), Q8.3 (D)
unnamed: Q9.S, U49.VIN
unnamed: U32.3 (DOUT), U33.1 (DIN)
unnamed: U33.3 (DOUT), U34.1 (DIN)
unnamed: U34.3 (DOUT), U35.1 (DIN)
unnamed: U35.3 (DOUT), U36.1 (DIN)
unnamed: U37.3 (DOUT), U38.1 (DIN)
unnamed: U38.3 (DOUT), U39.1 (DIN)
unnamed: U39.3 (DOUT), U40.1 (DIN)
unnamed: U40.3 (DOUT), U41.1 (DIN)
unnamed: U41.3 (DOUT), U42.1 (DIN)
unnamed: U18.3 (DOUT), U19.1 (DIN)
unnamed: U19.3 (DOUT), U20.1 (DIN)
unnamed: U20.3 (DOUT), U21.1 (DIN)
unnamed: U21.3 (DOUT), U22.1 (DIN)
unnamed: U22.3 (DOUT), U23.1 (DIN)
unnamed: U23.3 (DOUT), U24.1 (DIN)
unnamed: U24.3 (DOUT), U25.1 (DIN)
unnamed: U25.3 (DOUT), U26.1 (DIN)
unnamed: U26.3 (DOUT), U27.1 (DIN)
unnamed: U27.3 (DOUT), U28.1 (DIN)
unnamed: U28.3 (DOUT), U29.1 (DIN)
unnamed: U29.3 (DOUT), U30.1 (DIN)
unnamed: U30.3 (DOUT), U31.1 (DIN)
unnamed: C43.1, R45.1, U48.5 (OUT)
unnamed: R20.1, U47.C4 (FREQ)
NEOPIXEL_DIN: J30.1, U10.3 (A)
RELAY_AND_0: Q5.1 (G), R11.2, U50.8 (P04)
RELAY_AND_1: Q6.1 (G), R13.2, U50.6 (P02)
RELAY_AND_2: Q7.1 (G), R15.2, U50.4 (P00)
RELAY_AND_3: Q8.1 (G), R17.2, U50.20 (P17)
RELAY_MECH_0: C28.2, Q1.1 (G), R3.2, R12.2, U50.9 (P05)
RELAY_MECH_1: C29.2, Q2.1 (G), R4.1, R14.2, U50.7 (P03)
RELAY_MECH_2: C30.2, Q3.1 (G), R5.1, R16.2, U50.5 (P01)
RELAY_MECH_3: C31.2, Q4.1 (G), R6.1, R18.2, U50.19 (P16)

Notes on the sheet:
Use JLC2313 Stackup: https://jlcpcb.com/client/index.html#/impedance. 0.2 mm prepeg
NB: P,N order matches SDR datasheet spec.
Power
Host AUX
Headstage Ports
Analog IO
HARP_CLKIN signal has the serial comunication/protocol that is synchronizing all the Harp devices.
HARP Bus
CLK Feedthrough
Quad 1
Quad 2
Quad 3
TP1
TP2
TP3
TP4
TP5
IO Expander
Buttons
FPGA
Digital IO
Status LEDs
ADDR: 0100000X
NB: Assuming ~20pF combined parasitic capacitance of input proection and leads, fc = 1/(2*pi*270*20e-12) ~ 39MHz
NB: Jumper wire to pin 25 on bottom of TinyFPGA
PWR
HST0
HARP
LOCK
DO7
DO6
DO5
DO4
DO3
DO2
DO1
DO0
DI0
DI1
DI2

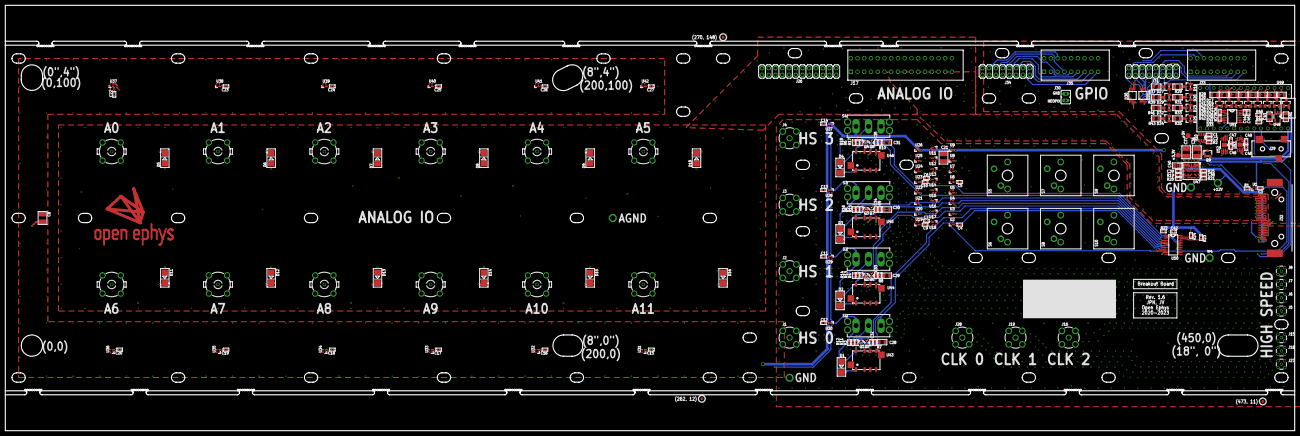
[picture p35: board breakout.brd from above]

Board: 4 copper layers, 485.0 x 160.0 mm, 246 parts (0 on the bottom side), 166 nets.

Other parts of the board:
E$1, E$3, E$5: FIDUCIAL

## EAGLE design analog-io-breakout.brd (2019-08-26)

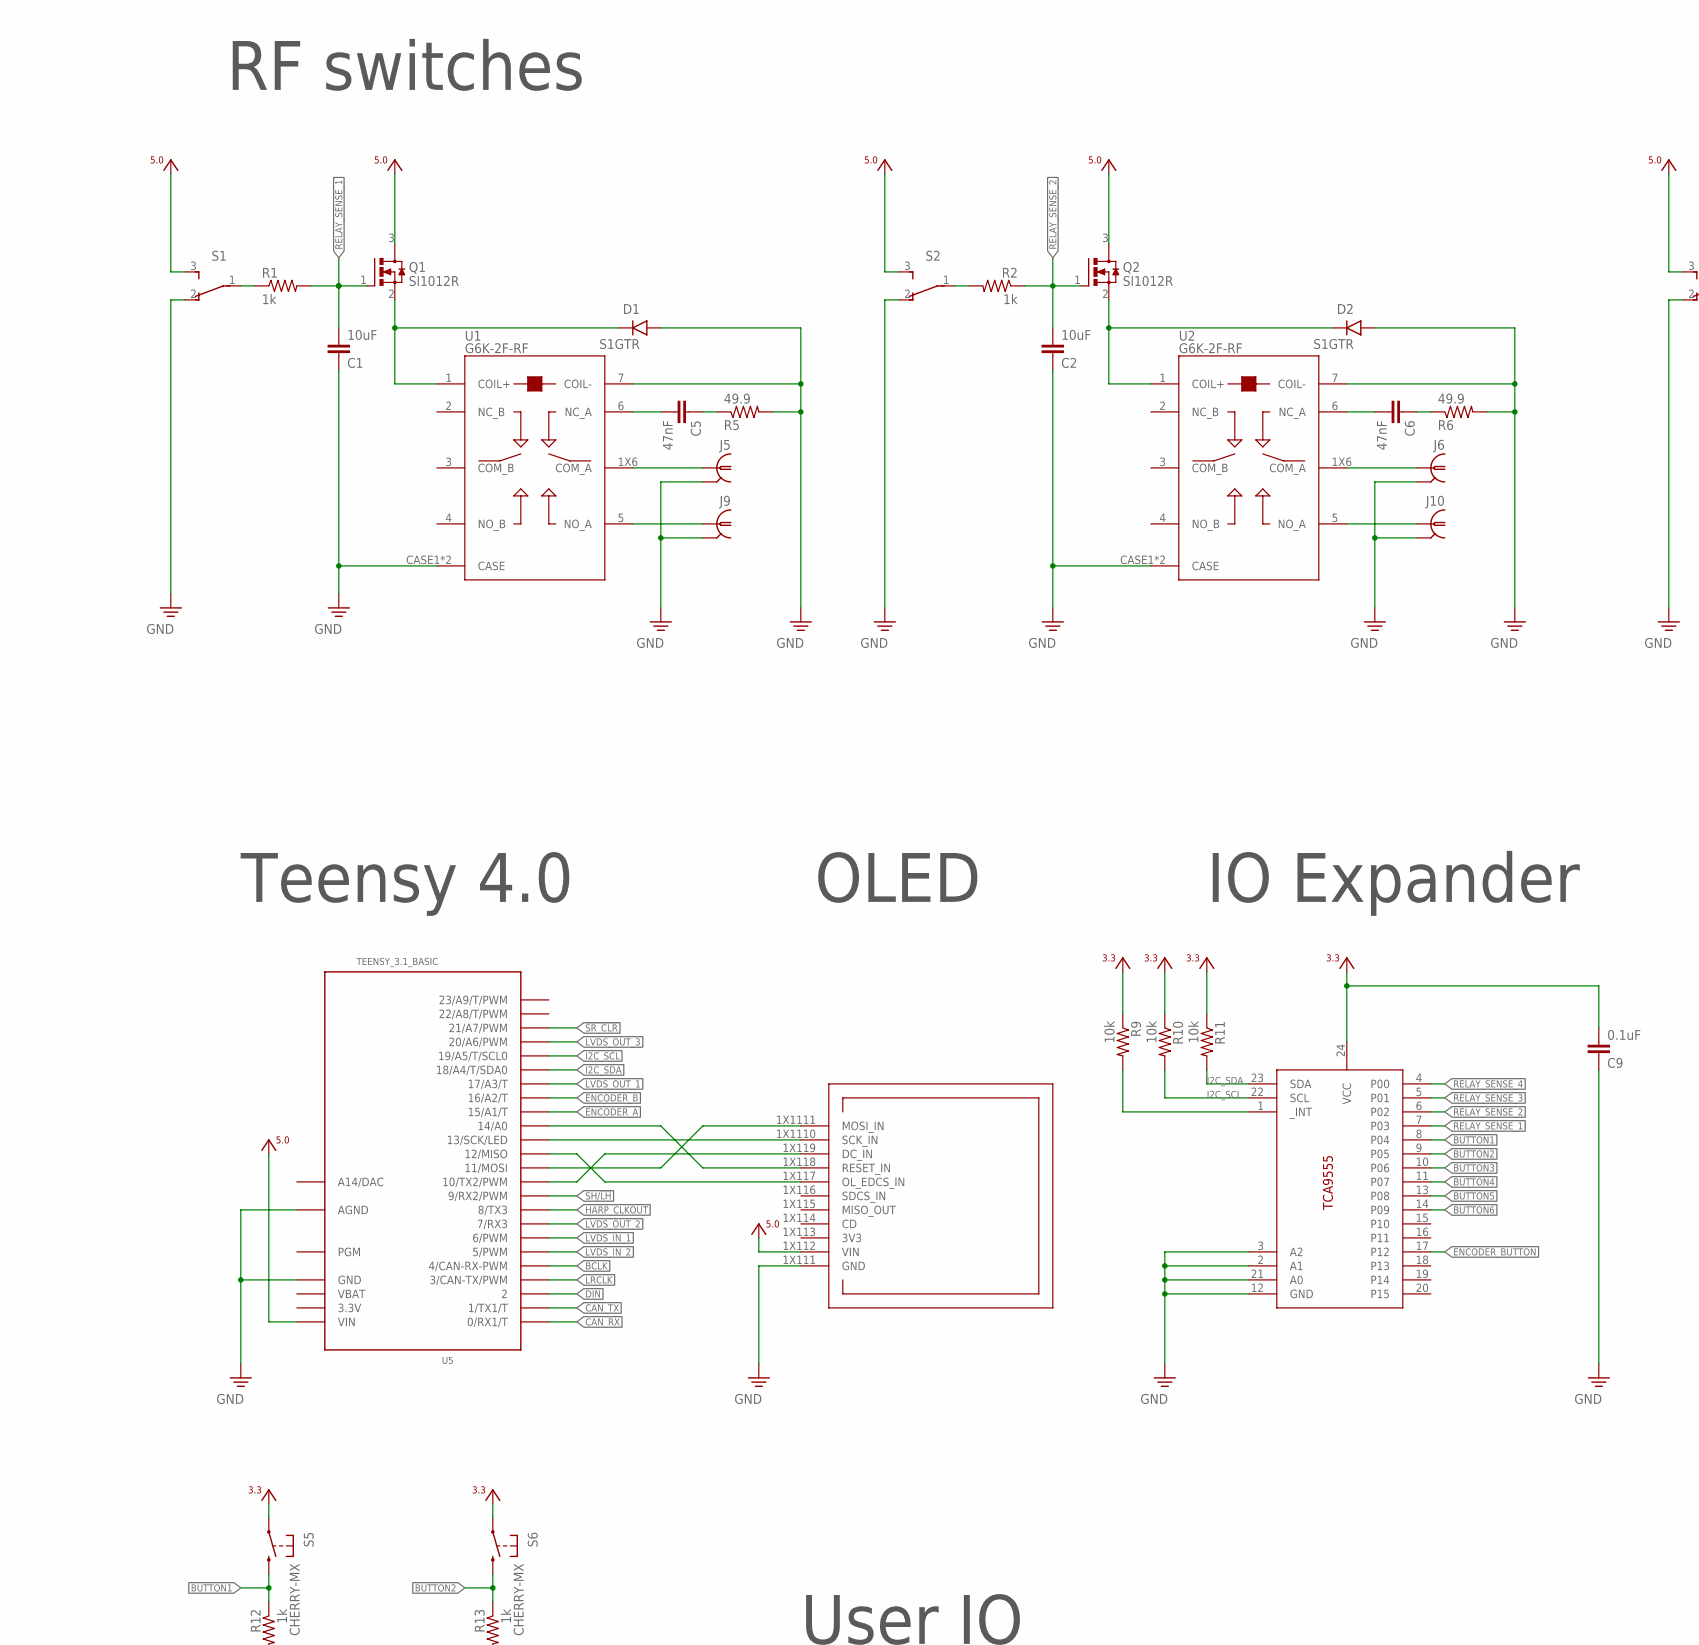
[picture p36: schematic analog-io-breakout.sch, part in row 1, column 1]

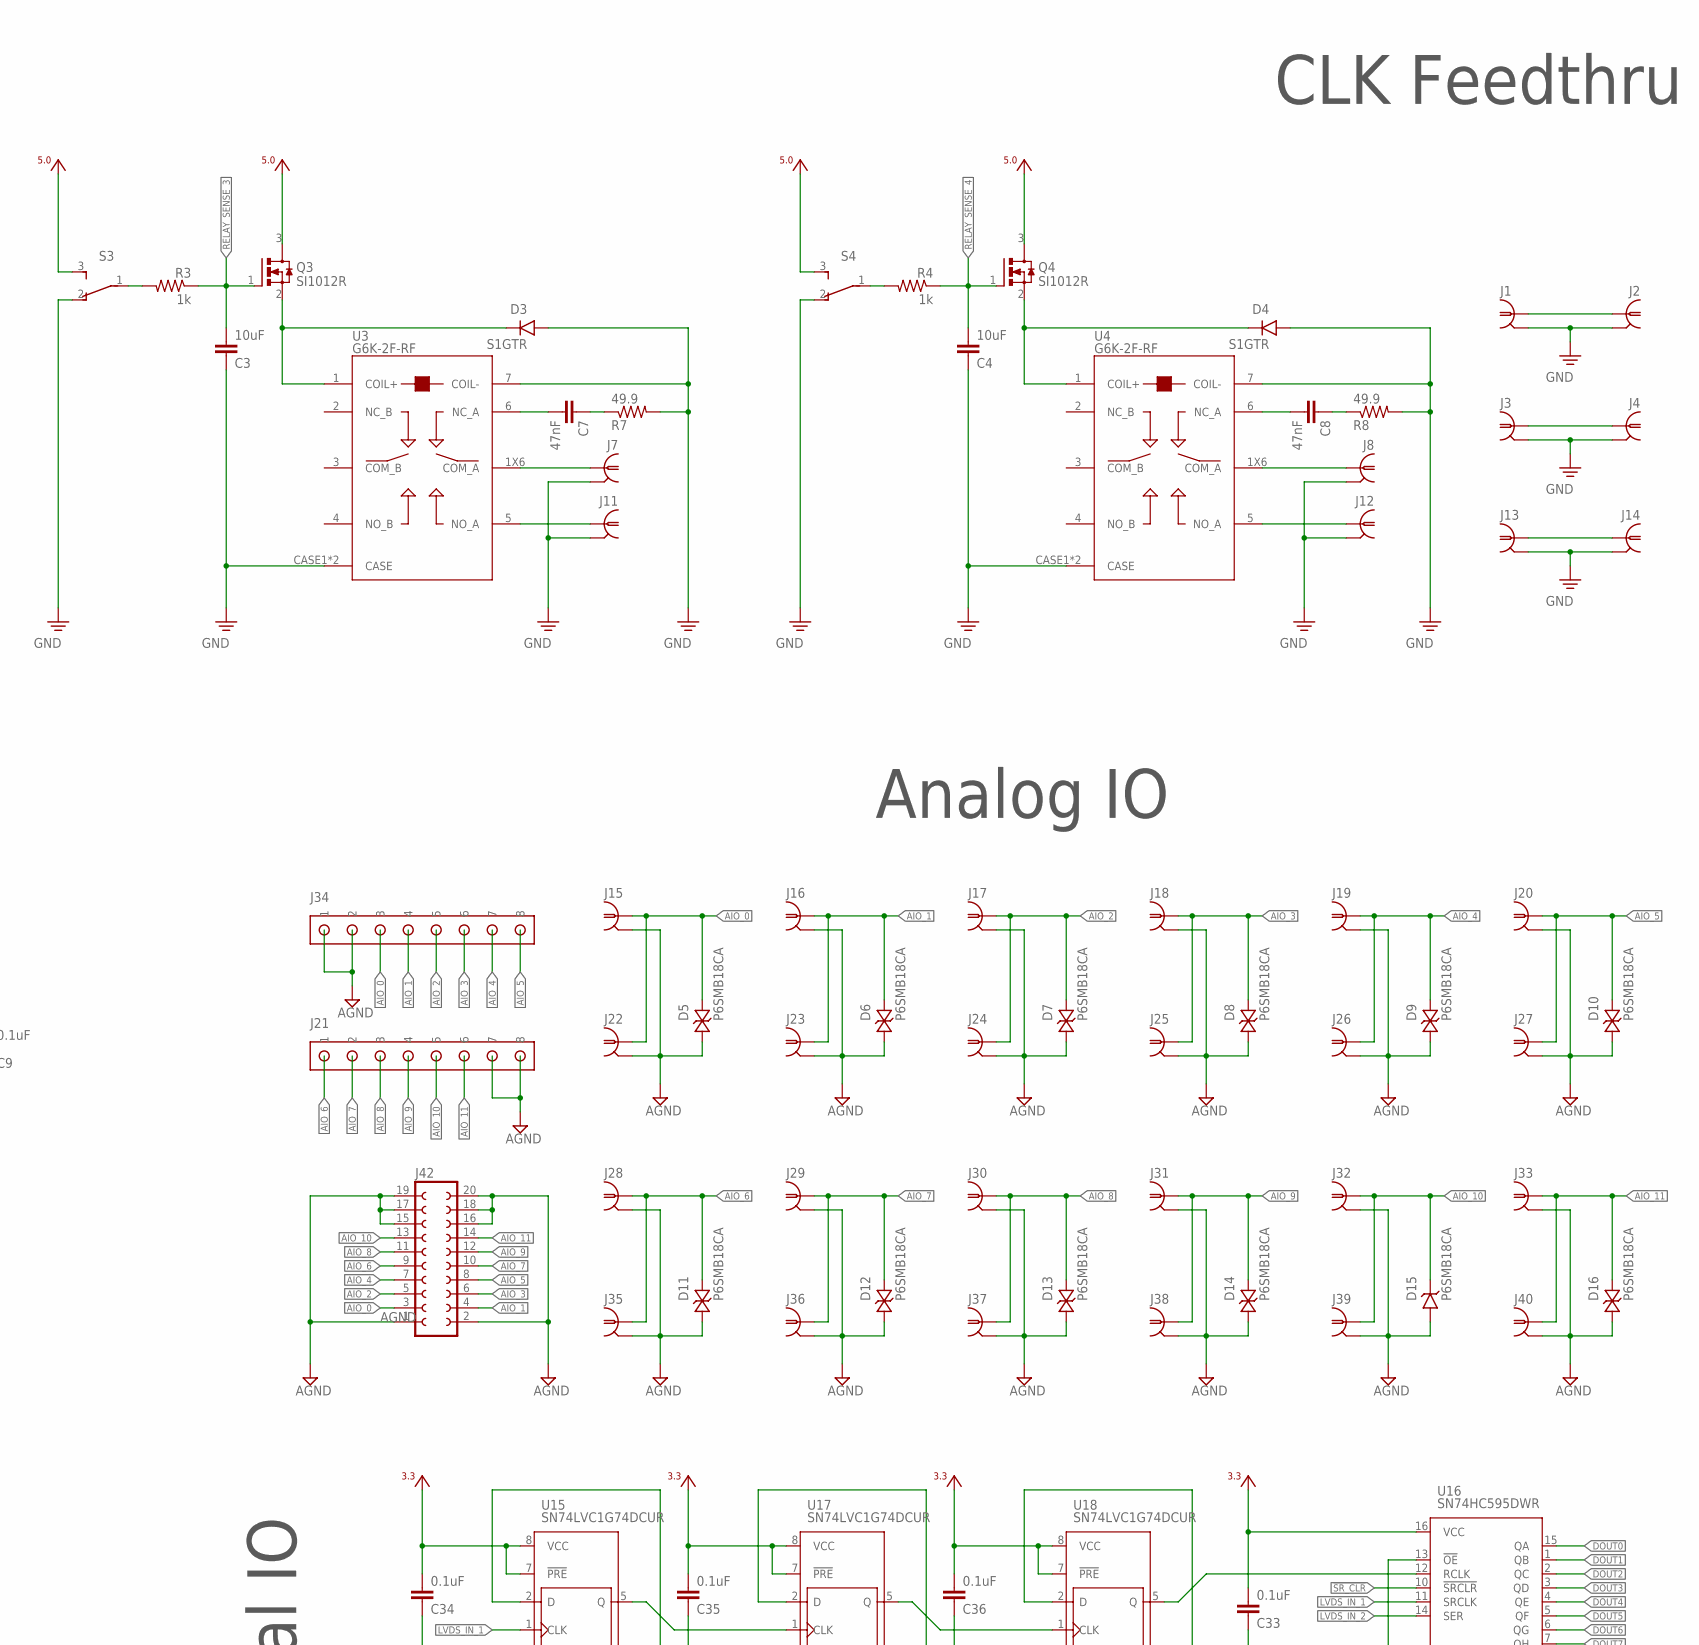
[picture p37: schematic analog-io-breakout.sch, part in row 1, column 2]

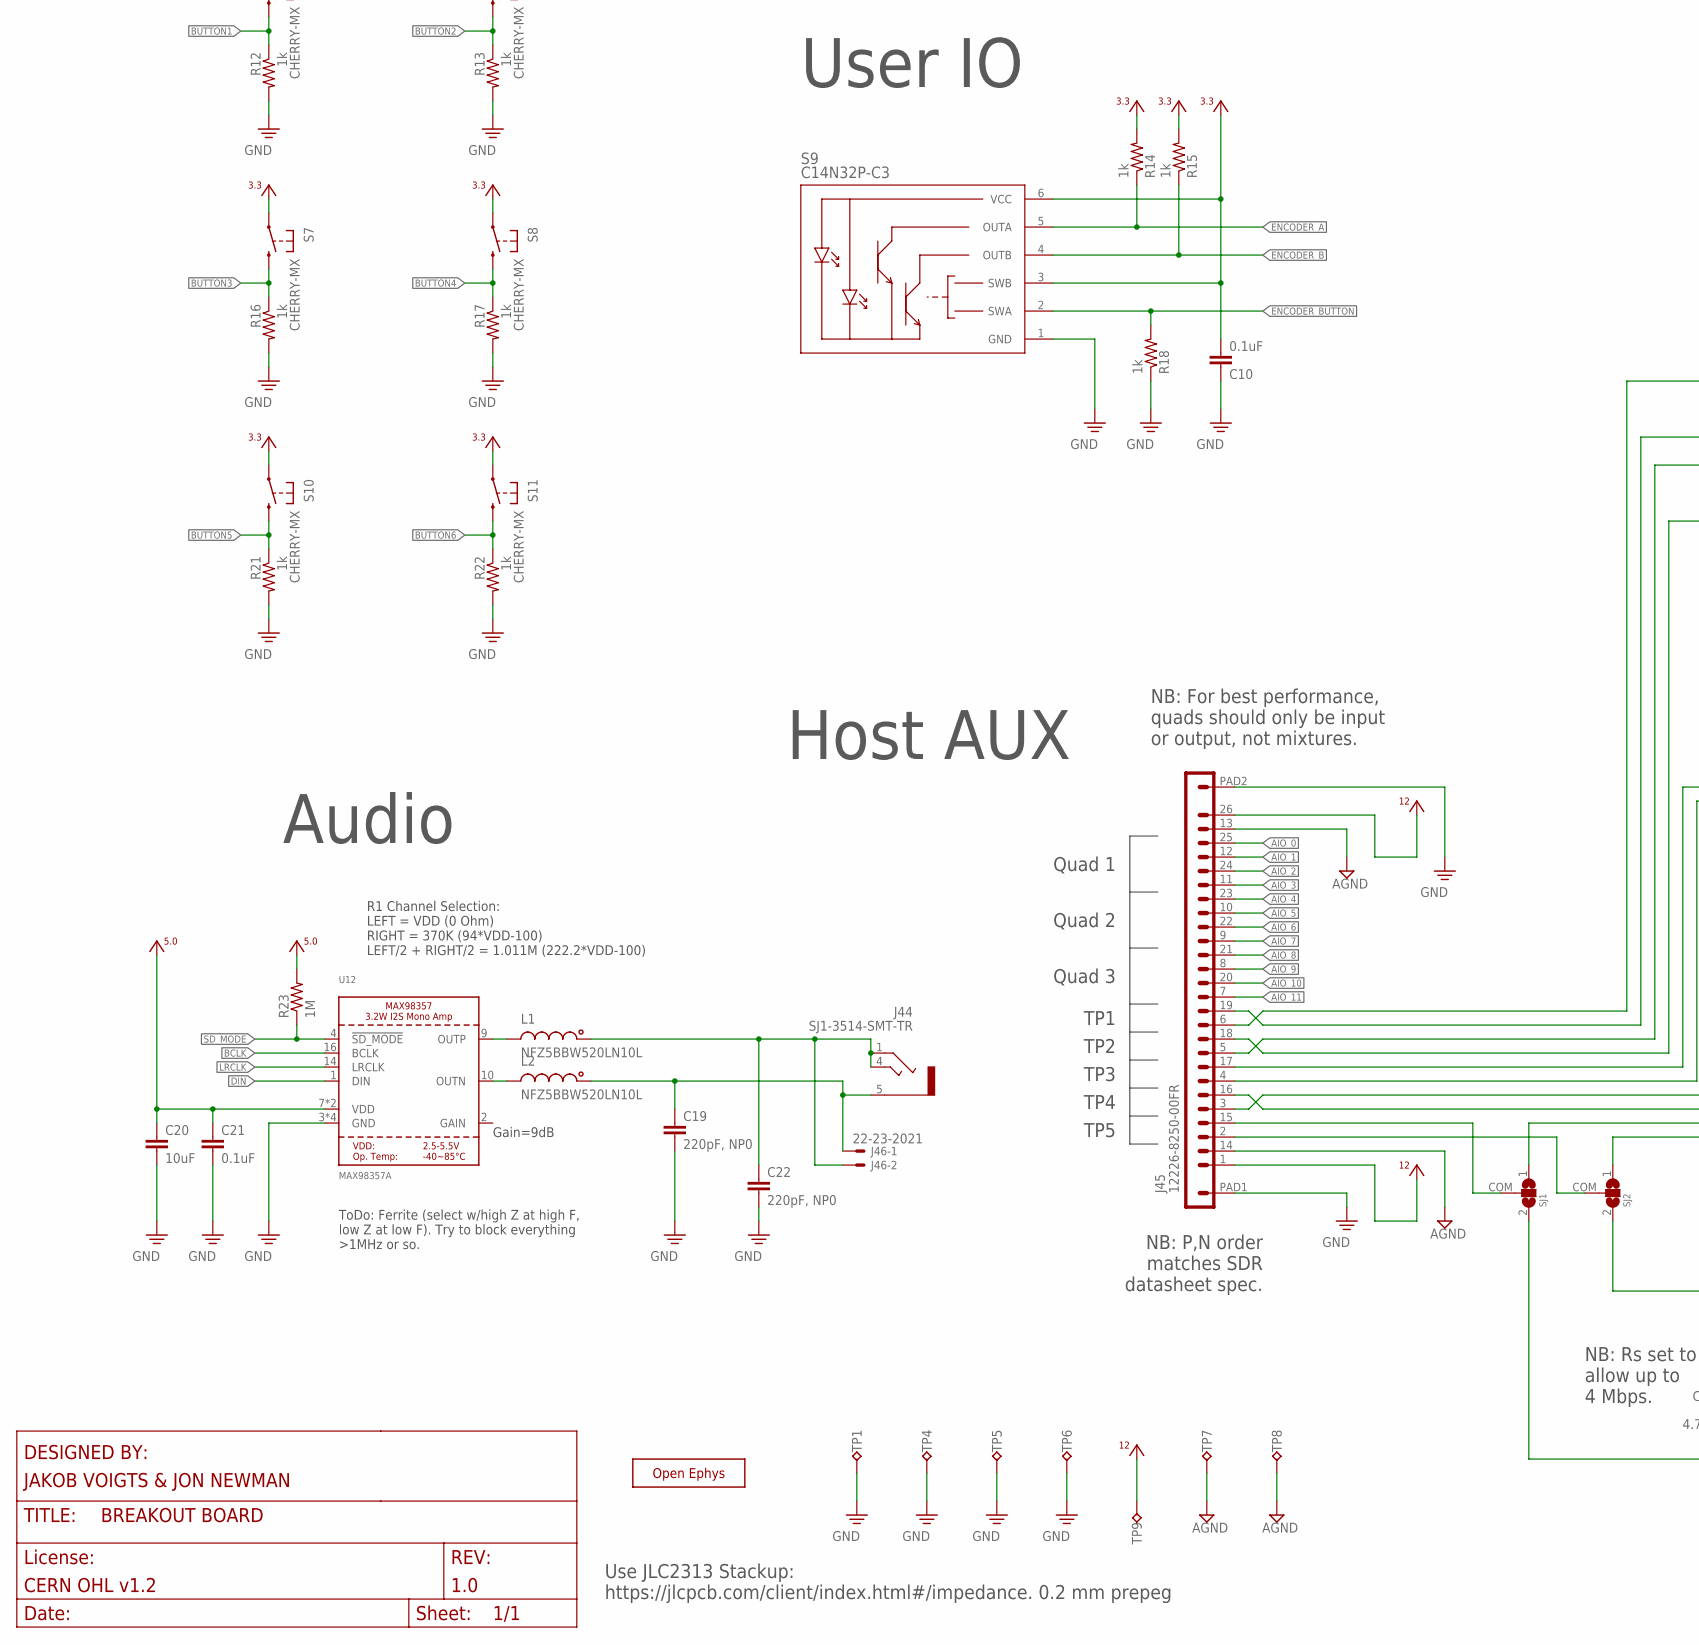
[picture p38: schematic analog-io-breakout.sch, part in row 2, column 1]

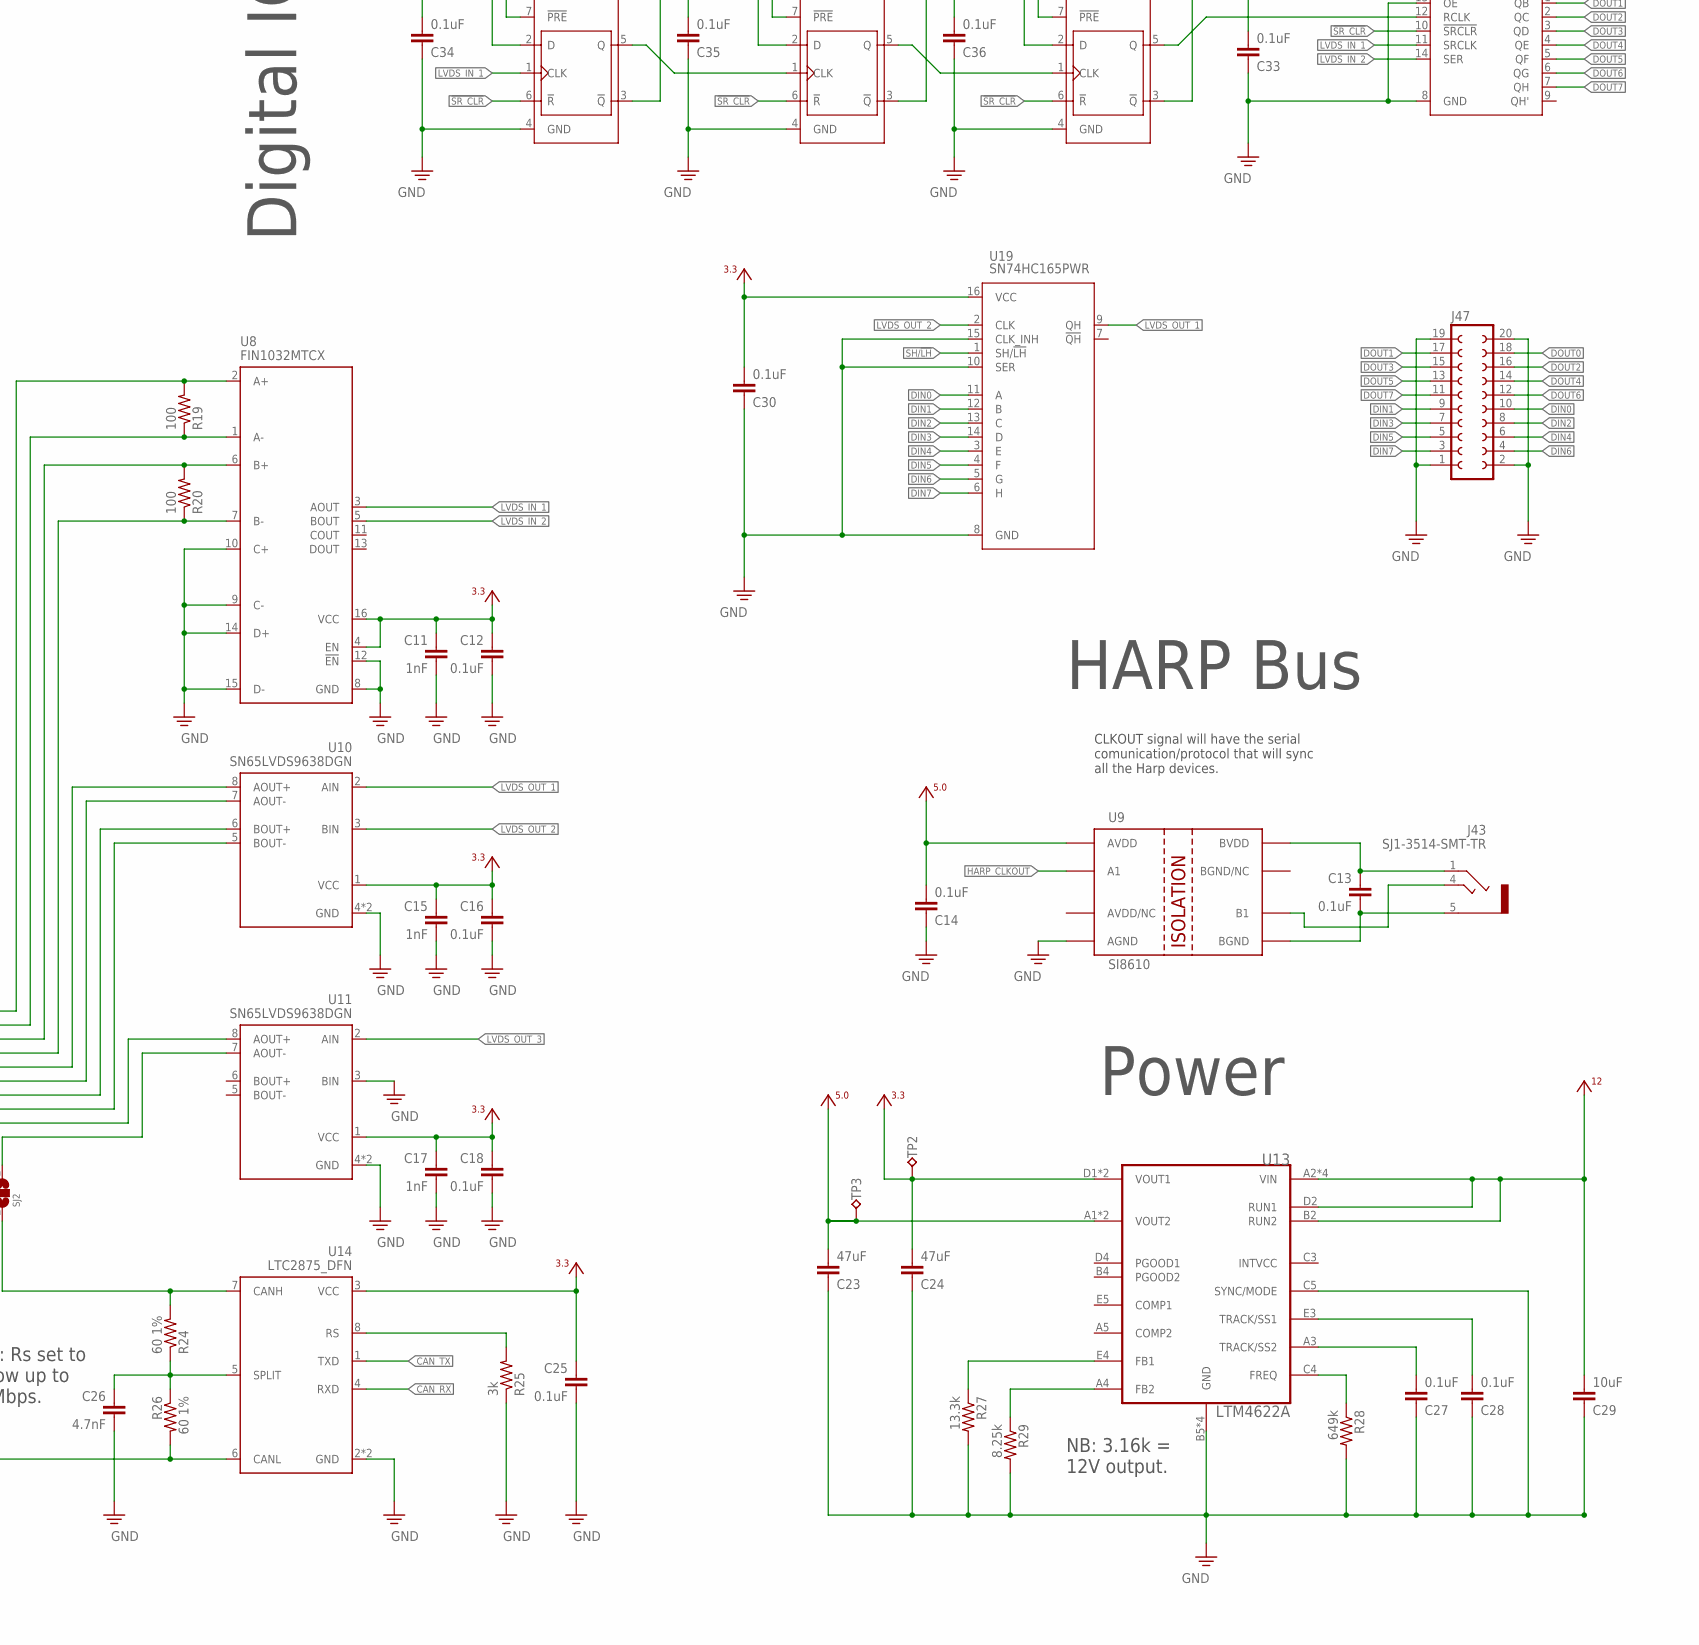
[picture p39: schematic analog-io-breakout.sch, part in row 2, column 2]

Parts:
C1, C2, C3, C4, C20, C29: 10uF; 0805
C5, C6, C7, C8: 47nF; 0402
C9, C10, C12, C13, C14, C16, C18, C21, C25, C27, C28, C30, C33, C34, C35, C36: 0.1uF; 0402
C11, C15, C17: 1nF; 0402
C19, C22: 220pF, NP0; 0402
C23, C24: 47uF; 1210
C26: 4.7nF; 0402
D1, D2, D3, D4: S1GTR; SMA-DO214AC
D5, D6, D7, D8, D9, D10, D11, D12, D13, D14, D15, D16: P6SMB18CA; SMA-DO214AC
J1, J3, J9, J10, J11, J12, J13: COAX_MMCX-THRU; MMCX-THRU
J2, J4, J5, J6, J7, J8, J14, J22, J23, J24, J25, J26, J27, J35, J36, J37, J38, J39, J40: COAX_SMA-VERT; SMA_JACK_142-0701-201
J15, J16, J17, J18, J19, J20, J28, J29, J30, J31, J32, J33: COAX_0731010360; 0731010360
J21, J34: SCREW8
J42, J47: FE10-2
J43, J44: SJ1-3514-SMT-TR; 35RASMT2BHNTRX
J45: 12226-8250-00FR; 12226-82X0-00XX
J46: 22-23-2021
L1, L2: NFZ5BBW520LN10L; 2020
Q1, Q2, Q3, Q4: SI1012R; SC75
R1, R2, R3, R4, R12, R13, R14, R15, R16, R17, R18, R21, R22: 1k; 0402
R5, R6, R7, R8: 49.9; 0402
R9, R10, R11: 10k; 0402
R19, R20: 100; 0402
R23: 1M; 0402
R24, R26: 60 1%; 0402
R25: 3k; 0402
R27: 13.3k; 0402
R28: 649k; 0402
R29: 8.25k; 0402
S1, S2, S3, S4: SPDT_CK-710; CK_7101J1V3QE2
S5, S6, S7, S8, S10, S11: CHERRY-MX
S9: C14N32P-C3
SJ1, SJ2: SJ2_0201; SJ_2_0201
TP1, TP4, TP5, TP6, TP7, TP8: TP_2MM; TESTPOINT_2MM
TP2, TP3: TPB1,27; B1,27
TP9: TPTP12R; TP12R
U1, U2, U3, U4: G6K-2F-RF; G6KU-2F-RF
U5: TEENSY_3.1_BASIC
U6: ADAFRUIT_1_5_OLED
U7: TCA9555; TSSOP-24
U8: FIN1032MTCX; TSSOP-16
U9: SI8610; SO-08
U10, U11: SN65LVDS9638DGN; MSOP-8-PAD-3X3
U12: MAX98357A; QFN16_3MM
U13: LTM4622A; BGA_5X5_625X625
U14: LTC2875_DFN; DFN83X3
U15, U17, U18: SN74LVC1G74DCUR; VSSOP-N8-3X3
U16: SN74HC595DWR; TSSOP-16
U19: SN74HC165PWR; TSSOP-16
X: OE-LOGO_28X20; OE-LOGO-28X20

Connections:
3.3V: U5.3.3V, U5.3.3V1 (3.3V)
!SR_CLR: U5.21/A7 (21/A7/PWM), U15.6 (!R), U16.10 (!SRCLR), U17.6 (!R), U18.6 (!R)
+3V3: C9.2, C10.2, C11.1, C12.1, C15.1, C16.1, C17.1, C18.1, C24.2, C25.1, C30.2, C33.2, C34.2, C35.2, C36.2, R9.1, R10.1, R11.1, R14.2, R15.2, S5.SW1, S6.SW1, S7.SW1, S8.SW1, S9.3 (SWB), S9.6 (VCC), S10.SW1, S11.SW1, TP2.TP, U7.24 (VCC), U8.4 (EN), U8.16 (VCC), U10.1 (VCC), U11.1 (VCC), U13.D1 (VOUT1), U13.E1 (VOUT1), U14.3 (VCC), U15.7 (!PRE), U15.8 (VCC), U16.16 (VCC), U17.7 (!PRE), U17.8 (VCC), U18.7 (!PRE), U18.8 (VCC), U19.16 (VCC)
+5V0: C14.2, C20.1, C21.1, C23.2, Q1.3 (D), Q2.3 (D), Q3.3 (D), Q4.3 (D), R23.2, S1.3, S2.3, S3.3, S4.3, TP3.TP, U5.VIN, U6.1X112 (VIN), U9.1 (AVDD), U12.7 (VDD), U12.8 (VDD), U13.A1 (VOUT2), U13.B1 (VOUT2)
+12V: C29.2, J45.1, J45.26, TP9.TP, U13.A2 (VIN), U13.B2 (RUN2), U13.B3 (VIN), U13.D2 (RUN1), U13.D3 (VIN), U13.E2 (VIN)
AGND: D5.A (1), D6.A (1), D7.A (1), D8.A (1), D9.A (1), D10.A (1), D11.A (1), D12.A (1), D13.A (1), D14.A (1), D15.A, D16.A (1), J15.2, J15.3 (2), J15.4 (2), J15.5 (2), J16.2, J16.3 (2), J16.4 (2), J16.5 (2), J17.2, J17.3 (2), J17.4 (2), J17.5 (2), J18.2, J18.3 (2), J18.4 (2), J18.5 (2), J19.2, J19.3 (2), J19.4 (2), J19.5 (2), J20.2, J20.3 (2), J20.4 (2), J20.5 (2), J21.7, J21.8, J22.GND$1 (2), J22.GND$2 (2), J22.GND$3 (2), J22.GND$4 (2), J23.GND$1 (2), J23.GND$2 (2), J23.GND$3 (2), J23.GND$4 (2), J24.GND$1 (2), J24.GND$2 (2), J24.GND$3 (2), J24.GND$4 (2), J25.GND$1 (2), J25.GND$2 (2), J25.GND$3 (2), J25.GND$4 (2), J26.GND$1 (2), J26.GND$2 (2), J26.GND$3 (2), J26.GND$4 (2), J27.GND$1 (2), J27.GND$2 (2), J27.GND$3 (2), J27.GND$4 (2), J28.2, J28.3 (2), J28.4 (2), J28.5 (2), J29.2, J29.3 (2), J29.4 (2), J29.5 (2), J30.2, J30.3 (2), J30.4 (2), J30.5 (2), J31.2, J31.3 (2), J31.4 (2), J31.5 (2), J32.2, J32.3 (2), J32.4 (2), J32.5 (2), J33.2, J33.3 (2), J33.4 (2), J33.5 (2), J34.1, J34.2, J35.GND$1 (2), J35.GND$2 (2), J35.GND$3 (2), J35.GND$4 (2), J36.GND$1 (2), J36.GND$2 (2), J36.GND$3 (2), J36.GND$4 (2), J37.GND$1 (2), J37.GND$2 (2), J37.GND$3 (2), J37.GND$4 (2), J38.GND$1 (2), J38.GND$2 (2), J38.GND$3 (2), J38.GND$4 (2), J39.GND$1 (2), J39.GND$2 (2), J39.GND$3 (2), J39.GND$4 (2), J40.GND$1 (2), J40.GND$2 (2), J40.GND$3 (2), J40.GND$4 (2), J42.1, J42.2, J42.15, J42.16, J42.17, J42.18, J42.19, J42.20, J45.13, J45.14, TP7.1, TP8.1
AIO_0: D5.C (2), J15.1, J22.CLK (1), J34.3, J42.3, J45.25
AIO_1: D6.C (2), J16.1, J23.CLK (1), J34.4, J42.4, J45.12
AIO_2: D7.C (2), J17.1, J24.CLK (1), J34.5, J42.5, J45.24
AIO_3: D8.C (2), J18.1, J25.CLK (1), J34.6, J42.6, J45.11
AIO_4: D9.C (2), J19.1, J26.CLK (1), J34.7, J42.7, J45.23
AIO_5: D10.C (2), J20.1, J27.CLK (1), J34.8, J42.8, J45.10
AIO_6: D11.C (2), J21.1, J28.1, J35.CLK (1), J42.9, J45.22
AIO_7: D12.C (2), J21.2, J29.1, J36.CLK (1), J42.10, J45.9
AIO_8: D13.C (2), J21.3, J30.1, J37.CLK (1), J42.11, J45.21
AIO_9: D14.C (2), J21.4, J31.1, J38.CLK (1), J42.12, J45.8
AIO_10: D15.C, J21.5, J32.1, J39.CLK (1), J42.13, J45.20
AIO_11: D16.C (2), J21.6, J33.1, J40.CLK (1), J42.14, J45.7
BCLK: U5.4 (4/CAN-RX-PWM), U12.16 (BCLK)
BUTTON1: R12.1, S5.SW2 (S), U7.8 (P04)
BUTTON2: R13.1, S6.SW2 (S), U7.9 (P05)
BUTTON3: R16.1, S7.SW2 (S), U7.10 (P06)
BUTTON4: R17.1, S8.SW2 (S), U7.11 (P07)
BUTTON5: R21.1, S10.SW2 (S), U7.13 (P08)
BUTTON6: R22.1, S11.SW2 (S), U7.14 (P09)
CAN_N: R26.2, SJ1.2, U14.6 (CANL)
CAN_P: R24.2, SJ2.2, U14.7 (CANH)
CAN_RX: U5.0 (0/RX1/T), U14.4 (RXD)
CAN_TX: U5.1 (1/TX1/T), U14.1 (TXD)
CLK/8: U16.12 (RCLK), U18.5 (Q)
DIN: U5.2, U12.1 (DIN)
DIN0: J47.10, U19.11 (A)
DIN1: J47.9, U19.12 (B)
DIN2: J47.8, U19.13 (C)
DIN3: J47.7, U19.14 (D)
DIN4: J47.6, U19.3 (E)
DIN5: J47.5, U19.4 (F)
DIN6: J47.4, U19.5 (G)
DIN7: J47.3, U19.6 (H)
DOUT0: J47.18, U16.15 (QA)
DOUT1: J47.17, U16.1 (QB)
DOUT2: J47.16, U16.2 (QC)
DOUT3: J47.15, U16.3 (QD)
DOUT4: J47.14, U16.4 (QE)
DOUT5: J47.13, U16.5 (QF)
DOUT6: J47.12, U16.6 (QG)
DOUT7: J47.11, U16.7 (QH)
ENCODER_A: R14.1, S9.5 (OUTA), U5.15/A1 (15/A1/T)
ENCODER_B: R15.1, S9.4 (OUTB), U5.16/A2 (16/A2/T)
ENCODER_BUTTON: R18.2, S9.2 (SWA), U7.17 (P12)
GND: C1.1, C2.1, C3.1, C4.1, C9.1, C10.1, C11.2, C12.2, C14.1, C15.2, C16.2, C17.2, C18.2, C19.2, C20.2, C21.2, C22.2, C23.1, C24.1, C25.2, C26.2, C27.1, C28.1, C29.1, C30.1, C33.1, C34.1, C35.1, C36.1, D1.A, D2.A, D3.A, D4.A, J1.GND@1 (2), J1.GND@2 (2), J1.GND@3 (2), J1.GND@4 (2), J2.GND$1 (2), J2.GND$2 (2), J2.GND$3 (2), J2.GND$4 (2), J3.GND@1 (2), J3.GND@2 (2), J3.GND@3 (2), J3.GND@4 (2), J4.GND$1 (2), J4.GND$2 (2), J4.GND$3 (2), J4.GND$4 (2), J5.GND$1 (2), J5.GND$2 (2), J5.GND$3 (2), J5.GND$4 (2), J6.GND$1 (2), J6.GND$2 (2), J6.GND$3 (2), J6.GND$4 (2), J7.GND$1 (2), J7.GND$2 (2), J7.GND$3 (2), J7.GND$4 (2), J8.GND$1 (2), J8.GND$2 (2), J8.GND$3 (2), J8.GND$4 (2), J9.GND@1 (2), J9.GND@2 (2), J9.GND@3 (2), J9.GND@4 (2), J10.GND@1 (2), J10.GND@2 (2), J10.GND@3 (2), J10.GND@4 (2), J11.GND@1 (2), J11.GND@2 (2), J11.GND@3 (2), J11.GND@4 (2), J12.GND@1 (2), J12.GND@2 (2), J12.GND@3 (2), J12.GND@4 (2), J13.GND@1 (2), J13.GND@2 (2), J13.GND@3 (2), J13.GND@4 (2), J14.GND$1 (2), J14.GND$2 (2), J14.GND$3 (2), J14.GND$4 (2), J45.PAD1, J45.PAD2, J47.1, J47.2, J47.19, J47.20, R5.2, R6.2, R7.2, R8.2, R12.2, R13.2, R16.2, R17.2, R18.1, R21.2, R22.2, R25.1, R27.2, R28.2, R29.2, S1.2 (1), S2.2 (1), S3.2 (1), S4.2 (1), S9.1 (GND), TP1.1, TP4.1, TP5.1, TP6.1, U1.7 (COIL-), U1.CASE1 (CASE), U1.CASE2 (CASE), U2.7 (COIL-), U2.CASE1 (CASE), U2.CASE2 (CASE), U3.7 (COIL-), U3.CASE1 (CASE), U3.CASE2 (CASE), U4.7 (COIL-), U4.CASE1 (CASE), U4.CASE2 (CASE), U5.AGND, U5.GND, U5.GND1 (GND), U6.1X111 (GND), U7.2 (A1), U7.3 (A2), U7.12 (GND), U7.21 (A0), U8.8 (GND), U8.9 (C-), U8.10 (C+), U8.12 (!EN), U8.14 (D+), U8.15 (D-), U9.4 (AGND), U10.4 (GND), U10.PAD (GND), U11.3 (BIN), U11.4 (GND), U11.PAD (GND), U12.3 (GND), U12.11 (GND), U12.15 (GND), U12.THERMAL (GND), U13.B5 (GND), U13.C1 (GND), U13.C2 (GND), U13.C5 (SYNC/MODE), U13.D5 (GND), U14.2 (GND), U14.PAD (GND), U15.4 (GND), U16.8 (GND), U16.13 (!OE), U17.4 (GND), U18.4 (GND), U19.8 (GND), U19.10 (SER), U19.15 (CLK_INH)
HARP_CLKOUT: U5.8 (8/TX3), U9.2 (A1)
I2C_SCL: R10.2, U5.19/A5 (19/A5/T/SCL0), U7.22 (SCL)
I2C_SDA: R11.2, U5.18/A4 (18/A4/T/SDA0), U7.23 (SDA)
LRCLK: U5.3 (3/CAN-TX/PWM), U12.14 (LRCLK)
LVDS_DIN0_N1: J45.4, U10.7 (AOUT-)
LVDS_DIN0_P1: J45.17, U10.8 (AOUT+)
LVDS_DIN1_N1: J45.16, U10.5 (BOUT-)
LVDS_DIN1_P1: J45.3, U10.6 (BOUT+)
LVDS_DIN2_N: SJ2.1, U11.7 (AOUT-)
LVDS_DIN2_P: SJ1.1, U11.8 (AOUT+)
LVDS_DOUT0_N1: J45.19, R19.1, U8.1 (A-)
LVDS_DOUT0_P1: J45.6, R19.2, U8.2 (A+)
LVDS_DOUT1_N1: J45.18, R20.1, U8.7 (B-)
LVDS_DOUT1_P1: J45.5, R20.2, U8.6 (B+)
LVDS_IN_1: U5.6 (6/PWM), U8.3 (AOUT), U15.1 (CLK), U16.11 (SRCLK)
LVDS_IN_2: U5.5 (5/PWM), U8.5 (BOUT), U16.14 (SER)
LVDS_OUT_1: U5.17/A3 (17/A3/T), U10.2 (AIN), U19.9 (QH)
LVDS_OUT_2: U5.7 (7/RX3), U10.3 (BIN), U19.2 (CLK)
LVDS_OUT_3: U5.20/A6 (20/A6/PWM), U11.2 (AIN)
unnamed: J1.SIG (1), J2.CLK (1)
unnamed: U5.11 (11/MOSI), U6.1X1111 (MOSI_IN)
unnamed: J3.SIG (1), J4.CLK (1)
unnamed: J13.SIG (1), J14.CLK (1)
unnamed: D1.C, Q1.2 (S), U1.1 (COIL+)
unnamed: U5.13 (13/SCK/LED), U6.1X1110 (SCK_IN)
unnamed: U5.10 (10/TX2/PWM), U6.1X119 (DC_IN)
unnamed: U5.14/A0, U6.1X118 (RESET_IN)
unnamed: U5.12 (12/MISO), U6.1X117 (OL_EDCS_IN)
unnamed: L2.2, U12.10 (OUTN)
unnamed: J45.2, SJ2.COM
unnamed: J45.15, SJ1.COM
unnamed: R25.2, U14.8 (RS)
unnamed: L1.2, U12.9 (OUTP)
unnamed: C5.2, U1.6 (NC_A)
unnamed: C13.1, J43.1, U9.8 (BVDD)
unnamed: C13.2, J43.5, U9.5 (BGND)
unnamed: J43.4, U9.6 (B1)
unnamed: J10.SIG (1), U2.5 (NO_A)
unnamed: U15.2 (D), U15.3 (!Q)
unnamed: U15.5 (Q), U17.1 (CLK)
unnamed: C6.1, R6.1
unnamed: R1.1, S1.1 (2)
unnamed: R29.1, U13.A4 (FB2)
unnamed: R27.1, U13.E4 (FB1)
unnamed: C27.2, U13.A3 (TRACK/SS2)
unnamed: C28.2, U13.E3 (TRACK/SS1)
unnamed: J9.SIG (1), U1.5 (NO_A)
unnamed: J5.CLK (1), U1.1X6 (COM_A)
unnamed: C5.1, R5.1
unnamed: C6.2, U2.6 (NC_A)
unnamed: D3.C, Q3.2 (S), U3.1 (COIL+)
unnamed: C7.1, R7.1
unnamed: J6.CLK (1), U2.1X6 (COM_A)
unnamed: R2.2, S2.1 (2)
unnamed: C7.2, U3.6 (NC_A)
unnamed: J11.SIG (1), U3.5 (NO_A)
unnamed: R3.2, S3.1 (2)
unnamed: D4.C, Q4.2 (S), U4.1 (COIL+)
unnamed: D2.C, Q2.2 (S), U2.1 (COIL+)
unnamed: C26.1, R24.1, R26.1, U14.5 (SPLIT)
unnamed: R9.2, U7.1 (_INT)
unnamed: J7.CLK (1), U3.1X6 (COM_A)
unnamed: R4.2, S4.1 (2)
unnamed: C8.1, R8.1
unnamed: C8.2, U4.6 (NC_A)
unnamed: J12.SIG (1), U4.5 (NO_A)
unnamed: J8.CLK (1), U4.1X6 (COM_A)
unnamed: U17.2 (D), U17.3 (!Q)
unnamed: U17.5 (Q), U18.1 (CLK)
unnamed: U18.2 (D), U18.3 (!Q)
unnamed: R28.1, U13.C4 (FREQ)
RELAY_SENSE_1: C1.2, Q1.1 (G), R1.2, U7.7 (P03)
RELAY_SENSE_2: C2.2, Q2.1 (G), R2.1, U7.6 (P02)
RELAY_SENSE_3: C3.2, Q3.1 (G), R3.1, U7.5 (P01)
RELAY_SENSE_4: C4.2, Q4.1 (G), R4.1, U7.4 (P00)
SD_MODE: R23.1, U12.4 (!SD_MODE)
SH/!LH: U5.9 (9/RX2/PWM), U19.1 (SH/!LH)
VBAT: U5.VBAT
VO+: C22.1, J44.1, J44.4, J46.2, L1.1
VO-: C19.1, J44.5, J46.1, L2.1

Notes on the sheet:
Use JLC2313 Stackup: https://jlcpcb.com/client/index.html#/impedance. 0.2 mm prepeg
Teensy 4.0
Quad 1
Quad 2
Quad 3
NB: For best performance, quads should only be input or output, not mixtures.
TP1
TP2
TP3
TP4
TP5
NB: P,N order matches SDR datasheet spec.
NB: Rs set to allow up to 4 Mbps.
NB: 3.16k = 12V output.
Power
Host AUX
RF switches
Analog IO
CLKOUT signal will have the serial comunication/protocol that will sync all the Harp devices.
HARP Bus
R1 Channel Selection: LEFT = VDD (0 Ohm) RIGHT = 370K (94*VDD-100) LEFT/2 + RIGHT/2 = 1.011M (222.2*VDD-100)
ToDo: Ferrite (select w/high Z at high F, low Z at low F). Try to block everything >1MHz or so.
Gain=9dB
Audio
IO Expander
OLED
User IO
CLK Feedthru
Digital IO

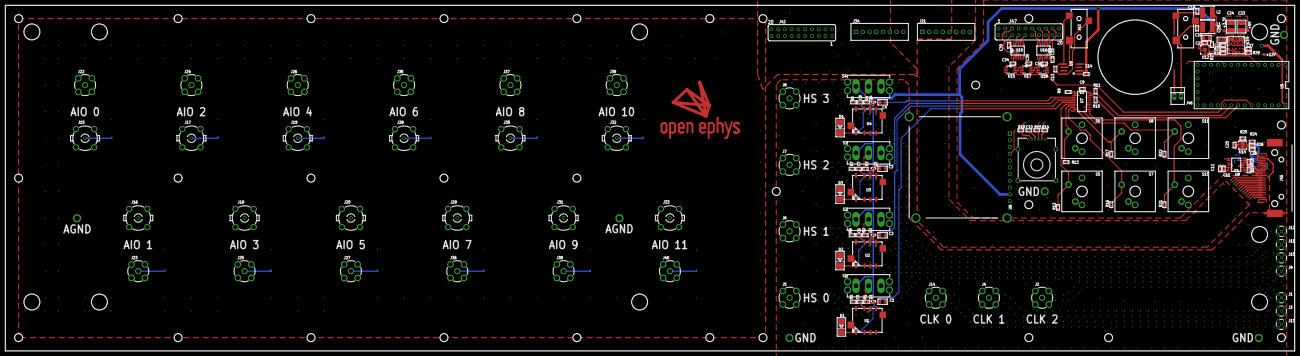
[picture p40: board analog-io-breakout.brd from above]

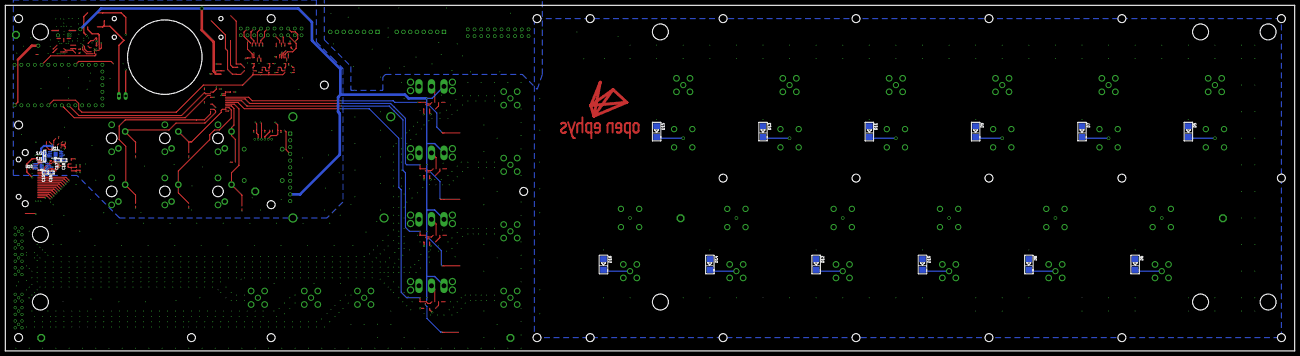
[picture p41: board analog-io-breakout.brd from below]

Board: 4 copper layers, 485.0 x 130.0 mm, 173 parts (20 on the bottom side), 130 nets.

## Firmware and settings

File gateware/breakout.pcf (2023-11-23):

###############################################################################
#
# TinyFPGA BX constraint file (.pcf)
#
###############################################################################
#
# Copyright (c) 2018, Luke Valenty
# All rights reserved.
#
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
# THIS SOFTWARE IS PROVIDED BY THE COPYRIGHT HOLDERS AND CONTRIBUTORS "AS IS" AND
# ANY EXPRESS OR IMPLIED WARRANTIES, INCLUDING, BUT NOT LIMITED TO, THE IMPLIED
# WARRANTIES OF MERCHANTABILITY AND FITNESS FOR A PARTICULAR PURPOSE ARE
# DISCLAIMED. IN NO EVENT SHALL THE COPYRIGHT OWNER OR CONTRIBUTORS BE LIABLE FOR
# ANY DIRECT, INDIRECT, INCIDENTAL, SPECIAL, EXEMPLARY, OR CONSEQUENTIAL DAMAGES
# (INCLUDING, BUT NOT LIMITED TO, PROCUREMENT OF SUBSTITUTE GOODS OR SERVICES;
# LOSS OF USE, DATA, OR PROFITS; OR BUSINESS INTERRUPTION) HOWEVER CAUSED AND
# ON ANY THEORY OF LIABILITY, WHETHER IN CONTRACT, STRICT LIABILITY, OR TORT
# (INCLUDING NEGLIGENCE OR OTHERWISE) ARISING IN ANY WAY OUT OF THE USE OF THIS
# SOFTWARE, EVEN IF ADVISED OF THE POSSIBILITY OF SUCH DAMAGE.
#
# The views and conclusions contained in the software and documentation are those
# of the authors and should not be interpreted as representing official policies,
# either expressed or implied, of the <project name> project.
#
###############################################################################

####
# TinyFPGA BX information: https://github.com/tinyfpga/TinyFPGA-BX/
# This PCF is for ONIX Breakout Revision 1.5
####

# Left side of board
set_io --warn-no-port D_OUT[7] A2           # Pin 1
set_io --warn-no-port D_OUT[6] A1           # Pin 2
set_io --warn-no-port D_OUT[5] B1           # Pin 3
set_io --warn-no-port D_OUT[4] C2           # Pin 4
set_io --warn-no-port D_OUT[3] C1           # Pin 5
set_io --warn-no-port D_OUT[2] D2           # Pin 6
set_io --warn-no-port D_OUT[1] D1           # Pin 7
set_io --warn-no-port D_OUT[0] E2           # Pin 8
set_io --warn-no-port D_IN3 E1              # Pin 9
set_io --warn-no-port D_IN4 G2              # Pin 10
set_io --warn-no-port D_IN5 H1              # Pin 11
set_io --warn-no-port D_IN6 J1              # Pin 12
set_io --warn-no-port D_IN7 H2              # Pin 13

# Right side of board
set_io --warn-no-port D_IN0 H9              # Pin 14
set_io --warn-no-port D_IN1 D9              # Pin 15
set_io --warn-no-port D_IN2 D8              # Pin 16
set_io --warn-no-port LVDS_IN[1] C9         # Pin 17
set_io --warn-no-port LVDS_IN[0] A9         # Pin 18
set_io --warn-no-port LVDS_OUT[0] B8        # Pin 19
set_io --warn-no-port LVDS_OUT[1] A8        # Pin 20
set_io --warn-no-port LVDS_OUT[2] B7        # Pin 21
set_io --warn-no-port I2C_SDA A7            # Pin 22
set_io --warn-no-port I2C_SCL B6            # Pin 23
set_io --warn-no-port HARP_CLK_IN A6        # Pin 24

# SPI flash interface on bottom of board
set_io --warn-no-port SPI_SS F7
set_io --warn-no-port SPI_SCK G7
set_io --warn-no-port SPI_IO0 G6
set_io --warn-no-port SPI_IO1 H7
set_io --warn-no-port SPI_IO2 H4
set_io --warn-no-port SPI_IO3 J8

# General purpose pins on bottom of board
set_io --warn-no-port NEOPIX G1             # Pin 25
set_io --warn-no-port PIN_26 J3
set_io --warn-no-port PIN_27 J4
set_io --warn-no-port PIN_28 G9
set_io --warn-no-port PIN_29 J9
set_io --warn-no-port UART E8               # Pin 30
set_io --warn-no-port PIN_31 J2

# LED
set_io --warn-no-port LED B3

# USB
set_io --warn-no-port USBP B4
set_io --warn-no-port USBN A4
set_io --warn-no-port USBPU A3

# 16MHz clock
set_io --warn-no-port XTAL B2 # input

# Clock constraints
set_frequency XTAL 16
set_frequency LVDS_IN[0] 10
set_frequency sys_clk 60
set_frequency LVDS_OUT[0] 12

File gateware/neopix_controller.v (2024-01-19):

// NB: colors.mem was generated using colors.py. There are lots of hardcoded
// constants in here that would need to be changed if the number of colors or
// their order is altered

`include "./ws2811/ws2811.v"

module neopix_controller # (
    parameter CLK_RATE_HZ = 50_000_000
) (
    // Clock and reset
    input   wire            i_clk,
    input   wire            i_reset,

    // Derived from host to breakout slow word
    input   wire            i_acq_running,
    input   wire            i_acq_reset_done,
    input   wire    [3:0]   i_ledlevel,
    input   wire    [1:0]   i_ledmode,
    input   wire    [1:0]   i_porta_status,
    input   wire    [1:0]   i_portb_status,
    input   wire    [1:0]   i_portc_status,
    input   wire    [1:0]   i_portd_status,
    input   wire    [11:0]  i_aio_dir,
    input   wire    [1:0]   i_harp_conf, // TODO
    input   wire    [15:0]  i_gpio_dir,  // TODO

    // Link power
    input   wire    [3:0]   i_link_pow,

    // HARP heartbeat
    input   wire            i_harp_hb,

    // Button press state
    input   wire    [5:0]   i_button,

    // Digital IO
    input   wire    [7:0]   i_din_state,
    input   wire    [7:0]   i_dout_state,

    // Neopixel control signal
    output  wire            o_neopix
);

//Timer for blinkenleds
parameter COUNTER_WIDTH = $clog2(CLK_RATE_HZ - 1);
reg [COUNTER_WIDTH - 1 : 0] counter = 'b0;
reg blink = 1'b1;

always @(posedge i_clk or posedge i_reset)
begin
    if (i_reset) begin
        counter <= 'b0;
        blink <= 1'b1;
    end else begin
        if (counter == CLK_RATE_HZ - 1) begin
            counter <= 'b0;
            blink <= ~blink;
        end else begin
            counter <= counter + 1'b1;
        end
    end
end

// Colors
reg [23:0] off,
           blue,
           orange,
           green,
           red,
           purple,
           brown ,
           pink ,
           white ,
           yellow,
           cyan;

// NB: This is hardcoded for the particular color set generated by colors.py
reg [23:0] colors [0:169];
reg [7:0] color_addr;
reg [3:0] color_idx, color_idx_last;
reg [23:0] color;

// Initialize RAM (produced by colors.py)
initial $readmemh("colors.mem", colors);
initial off = 0;

// RAM address
always @ (posedge i_clk) begin

    color_idx_last <= color_idx;

    if (i_reset) begin
        color_addr <= 0;
        color_idx <= 0;
    end else if (color_idx == 0) begin
        color_addr <= 153 + {4'b0000, i_ledlevel};
        color_idx <= 9;
    end else begin
        color_addr <= color_addr - 17;
        color_idx <= color_idx - 1;
    end
end

// RAM access
always @ (posedge i_clk) begin
    color <= colors[color_addr];
end

// Color update
always @ (posedge i_clk) begin
    case (color_idx_last)
        0: blue <= color;
        1: orange <= color;
        2: green <= color;
        3: red <= color;
        4: purple <= color;
        5: brown <= color;
        6: pink <= color;
        7: white <= color;
        8: yellow <= color;
        9: cyan <= color;
    endcase
end

// Neopixel color state
reg [23:0] rgb [0:40];

// LED on/off toggle 
reg dark = 1'b0;
reg [1:0] button0_history = 2'b00;

always @(posedge i_clk) begin

    button0_history <= {button0_history[0], i_button[0]};

    if (button0_history == 2'b01) begin
        dark <= dark + 1;
    end
end

// Port-specific running indicators
reg [3:0] port_running = 4'b0000;
reg [3:0] port_failed = 4'b0000;
reg last_acq_running = 1'b0;

always @(posedge i_clk) begin

    last_acq_running <= i_acq_running;

    // NB: Internal, port-specific running flag only changes on running start,
    // stop, or loss of lock or power
    if (!last_acq_running && i_acq_running) begin

        port_running <= {i_porta_status == 2'b11,
                         i_portb_status == 2'b11,
                         i_portc_status == 2'b11,
                         i_portd_status == 2'b11};
        port_failed <= 4'b0;

    end else if(!i_acq_running) begin

        port_running <= 4'b0;
        port_failed <= 4'b0;

    end else begin

        // Requires !i_acq_running to reset latch
        port_failed <= {port_failed[3] || (port_running[3] && i_porta_status != 2'b11),
                        port_failed[2] || (port_running[2] && i_portb_status != 2'b11),
                        port_failed[1] || (port_running[1] && i_portc_status != 2'b11),
                        port_failed[0] || (port_running[0] && i_portd_status != 2'b11)};
    end
end

wire leds_on = ~dark;

// LED color logic
always @(*) begin

    rgb[0] = leds_on ? yellow : off;

    rgb[1] = leds_on ?
            (i_acq_reset_done ?
            (i_acq_running ?
            (blink ?
            red : off) : red) : purple) : off;

    rgb[2] = (leds_on & i_button[5]) ? yellow : off;
    rgb[3] = (leds_on & i_button[4]) ? yellow : off;
    rgb[4] = (leds_on & i_button[3]) ? yellow : off;
    rgb[5] = (leds_on & i_button[2]) ? yellow : off;
    rgb[6] = (leds_on & i_button[1]) ? yellow : off;

    rgb[7] = (leds_on & i_harp_hb) ? red : off;
    rgb[8] = off; // TODO: "Host"

    rgb[9]  = (leds_on & i_dout_state[0]) ? blue : off;
    rgb[10] = (leds_on & i_dout_state[1]) ? blue : off;
    rgb[11] = (leds_on & i_dout_state[2]) ? blue : off;
    rgb[12] = (leds_on & i_dout_state[3]) ? blue : off;
    rgb[13] = (leds_on & i_dout_state[4]) ? blue : off;
    rgb[14] = (leds_on & i_dout_state[5]) ? blue : off;
    rgb[15] = (leds_on & i_dout_state[6]) ? blue : off;
    rgb[16] = (leds_on & i_dout_state[7]) ? blue : off;

    rgb[17] = (leds_on & i_din_state[7]) ? blue : off;
    rgb[18] = (leds_on & i_din_state[6]) ? blue : off;
    rgb[19] = (leds_on & i_din_state[5]) ? blue : off;
    rgb[20] = (leds_on & i_din_state[4]) ? blue : off;
    rgb[21] = (leds_on & i_din_state[3]) ? blue : off;
    rgb[22] = (leds_on & i_din_state[2]) ? blue : off;
    rgb[23] = (leds_on & i_din_state[1]) ? blue : off;
    rgb[24] = (leds_on & i_din_state[0]) ? blue : off;

    // NB: These if statements make heavy use of decending case priority
    // encoding

    // Port A (HS3 on the board)
    if (!leds_on || i_porta_status == 2'b00)            // Dark or power off
        rgb[25] = off;
    else if (port_failed[3])                            // Link issue in the middle of acquisition
        rgb[25] = orange;
    else if (port_running[3])                           // Acquisition running
        rgb[25] = blink ? red : off;
    else if (i_porta_status != 2'b01)                   // Locked
        rgb[25] = purple;
    else if (i_link_pow[3] && i_porta_status == 2'b01)  // Power on, waiting for lock
        rgb[25] = green;
    else
        rgb[25] = off;
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

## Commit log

2019-08-15 WIP on pcie system breakout board
    just started putting down some parts in the .sch and did some rough spacing tests
    [analog-io-breakout.GBL, analog-io-breakout.GBO, analog-io-breakout.GBS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]
2019-08-16 Breakout board WIP
    - added shiftreg to read keys and relay status
    - added power supply
    - added relays
    - added lvds/se converters
    [analog-io-breakout.brd, analog-io-breakout.sch]
2019-08-17 breakout board layout
    no routing but most of the basic connections are there
    [analog-io-breakout.brd, analog-io-breakout.sch]
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2019-08-18 Rough draft and fit test for breakout board case
    Likely going to go with 15mm face height frm pcb, measure adafruit oled for fit. This at least works well with the rocker switches, if soldered straight to PCB (requires full cutout on case, no trad.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
    [analog-io-breakout.step, analog-io-breakout_assembly.SLDASM, breakout_case_top_shell.SLDPRT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]
2019-08-19 Breakout board WIP
    -Basic PCB should be there, some open questions (see note on sch)
    - very rough sketch of housing spacing
    [Draw2.DXF, Draw2.SLDDRW, Part157.SLDPRT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]
2019-08-21 Breakout WIP
    -Switched to PCB mounted switches
    -Moved cherry keypad further away
    -Added LP filters and flyback diodes to RF switches
    [Draw2.SLDDRW, analog-io-breakout.brd, analog-io-breakout.sch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]
2019-08-22 WIP breakout board
    -added Harp interface
    -added little sudio amp for mono speaker output
    -lots of other little stuff
    -2do: add speaker as well, for bleep bloops
    [analog-io-breakout.brd, analog-io-breakout.sch]
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2019-08-22 speaker for breakout board
    added .1" header for small 28ish mm diameter speakers ( 433-1220-ND etc)
    [analog-io-breakout.brd, analog-io-breakout.sch]
2019-08-22 Adedd cutout for bigger skeaper to breakout board
    Should now barely fit a 2055-BGC-D40-22-4-002-ND
    [analog-io-breakout.brd]
2019-08-26 Breakout board layout and circuit fixes
    - Many fixes to schematic ERC and board layout
    - Added serial to parallel digital IO
    [analog-io-breakout.brd, analog-io-breakout.sch]
2019-08-26 Breakout version 1.0
    - This will be sent to fab
    - Very minor changes from last commit (one hole moved to prevent it from
    messing with the digital IO connector)
    [analog-io-breakout.GBL, analog-io-breakout.GBO, analog-io-breakout.GBS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]
2019-08-27 Final updates to breakout board r1.1 before fab
    - Fix OLED package
    - Double check teensy pins and update schematic with teensy 4.0 part
    - Minor routing changes
    [breakout.brd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]
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2019-09-05 More tweaks to breakout case
    Added more space for bottom side smd components
    [breakout_case_bottom_shell.SLDPRT, breakout_case_bottom_shell.STL, breakout_case_top_shell.STL]
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2019-09-23 Breakout board revision 1.1
    - Small changes to layout, routing, and footprints after assembly of rev
    1.0
    [analog-io-breakout.dxf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]
2019-09-23 Added custom knob for rotary encoder
    - Smaller than ones avaialable on DK and mcmaster
    [rotatary_knob.STL]
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2019-11-24 Breakout board revision 1.2
    - The breakout board is moving back to a much more passive device than
    in revision 1.0 and 1.1. The decision was made early for most logic to
    be carried out on host FMC board. We need to stick by this decision to
    prevent feature creep, maintenance issues, and synchronization bugs
    - Removed the OLED display
    - Removed rotary encoder
    - Teensy 4.0 was replaced with a Tiny FPGA Bx board so that LVDS outputs
    can be an ~0 delay shift-registered version of the digital input,
    output, and headstage power/connection state, and button pad state
    - Headstage status is now provided via a simple through-hole LED next to
    each rocker switch
    [breakout.GBL, breakout.GBO, breakout.GBS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]
2019-12-28 WIP breakout board
    updated PCB dimensions and started re-arranging parts
    - 2do: add audio jack
    - 2do: update shell
    - 2do: update mounting holes
    - 2do: split into two parts
    [1789472.SLDASM, 1789472_01.SLDPRT, 1789472_02.SLDPRT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]
2020-01-07 Basic sizing for updated breakout board case
    - Needs fit check
    - Needs draft angles
    - Needs to be split in 2 parts
    - Add cutouts for laser cut top panels?
    [CUI_DEVICES_SJ-3523-SMT-TR.sldprt, breakout_case_bottom_shell.SLDPRT, breakout_case_top_shell.SLDPRT]
2020-01-10 Breakout board rev. 1.2 ready for production
    - Minor changes to ERC and schematic
    [breakout.sch]
2020-02-07 Updated PCIe mounting bracket
    - Increased FMC standoff form 10 to 12mm
    - Added holes for LEDs
    - Fixed markings
2020-04-02 Added RGB LEDs and driver to breakout-board
    - The old circuit, with single green LEDs driven by the TCA9555 is still
    there and functional if this circuit is not populated
    - If it is, the LED outputs on the TCA should be set to hiZ
    [breakout.brd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]
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2020-04-09 Updates to breakout revision 1.3 during testing
    - Added input protection to digital IO after blowin up my FPGA during
    testing
    - Moved analog TVS diodes to top side to reduce manufacturing costs
    [breakout.GBL, breakout.GBO, breakout.GBS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]
2020-04-25 Replaced RGB LED driver with neopixels
    - This way we can have all kinds of status indicators on the board
    - I added 41 of the 1.5x1.5mm neopixels for indicating power, harp, pll
    lock, digital in, digital out, and analog IO state
    - The control signal for these is going to have to come from one of the
    SMD pads on the bottom of the TinyFPGA Bx. I just put a general purpose
    jumper pad in there so that soder wire or 0.1" connector to wire can be
    used instead of having a full connector under the FPGA board for a
    single wire.
    [breakout.brd, breakout.sch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]
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2020-05-01 Added lightpipe cutouts to breakout case top
    - Added cutouts for lightpipes, for using 350-3723-ND
    in 6.35 (.25) and 15.24 (.6) mm heights see http://www.dialightsignalsandcomponents.com/Assets/Brochures_And_Catalogs/Indication/Opto_new/Dialight_CBI_data_515_OptoVPM_3mm_Jan2019.pdf
    - 2do: split bottom half
    [Body1.STL, Body1.sldprt, Body2.STL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]
2020-05-27 Fixed typos in breakout board doc
2020-06-04 Increased minimum hole size to 0.3 mm on breakout rev 1.3
    - Ready for production
    [breakout.brd, breakout.sch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]
2020-06-10 Added frozen breakout/revisions/rev-1.3
    - This was just sent out for production and therefore needs a revision
    here
    - Eventually, the firmware and case should be included in this revision
    folder once it has stabized
    [breakout.GBL, breakout.GBO, breakout.GBS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]
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2020-07-02 clroni version 3.1.1
    - Replaced device map naming with device table
    - contex.DeviceTable is now a Dictionary rather than a List
    - Update nuget package
2020-08-10 Move random breakout board CAD files into case directory
    - They look old, and should pobably be removed anyway
    [Draw2.DXF, Draw2.SLDDRW, Part157.SLDPRT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]
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2020-08-10 Initial commit of breakout rev 1.4
    - Fixes to analog routing to maintain consistancy of analog and digital
    pin ordering in the screw terminals and IDC headers
    - Switch the ordering of BNC analog connector to row major and aligned
    in column direction.
    - Add a secondary, internally controlled FET in series with the coil on
    each headstage relay so that certain ports can be disabled when
    instructed from host.
    - Changed the optical table mounting holes to slots that can accomidate
    both metric and imperial spacing.
    [breakout.GBL, breakout.GBO, breakout.GBS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]
2020-08-28 Changes to breakout rev 1.4 after case fit test with rev 1.3
    - Moved components to prevent them from being smashed by case
    - More clearance around M3 holes
    - Smaller font on analog BNC labels
    - Moved the terminal blocks so that there spacing makes more sense for
    related signals.
    - Modeled screw terminal blocks correctly
    [breakout.brd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]
2020-09-01 Minore updates to breakout rev 1.4
    - Address issues found during the construction of the case
    - DOUT IDC and terminal block switch positions to match the other two IO
    banks
    [breakout.brd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]
2020-09-01 Breakout case WIP
    non functional, needs to be updated to newer pcb
    [breakout.dxf, breakout_case_pcb_3.SLDPRT, breakout_case_top_shell.SLDPRT]
2020-09-01 More updates to breakout rev. 1.4 to fit case
    - Swiched 2x 8 pin screw terminals for a single 16 pin screw terminal.
    - Moved m3 clearance holes in front of IDC connectors up a bit
    [breakout.brd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]
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2020-09-04 case redesign WIP
    [breakout_assembly_bottom_only_lasercut.SLDASM, pcb_spacer_lasercut_4mm_plastic.DXF]
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2020-10-07 Breakout board rev. 1.5
    - Very minor changes to 1.4 after a full fit test.
    - The M6/14-20 mount slots were made larger
    - The M3 holes were turned into slots to allow some slop
    - The power neopixel was moved down by 3.5 mm
    [breakout.GBL, breakout.GBO, breakout.GBS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]
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2020-10-09 Increased space between IDC headers and wire terminals on breakout
    - Moved by 2mm so that an IDC connector can actually plug into the
    header.
    [breakout.brd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]
2020-10-09 Updated case to fix a number of mechanics issues
    [Body1.sldprt, Body2.sldprt, Body3.sldprt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]
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2021-02-11 Added more room for caps in breakout case
    Changed circular cutouts on bottom side of the case facing the PCB to longer slots to make more room for components. Should fix issue that filipe just encountered on first test assembly for beta-test.
    [Body1.sldprt, Body2.sldprt]
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2021-03-16 Added color block RAM initialization file
    - Added colors.mem so it does not need to be generated with colors.py to
    generate a bit file
    - Increase power-on & PLL-lock reset duration which seems to allow hot
    plugging of the SDR cable without issue
    - Other minor fixes
    [breakout.pcf, neopix_controller.v]
2021-03-16 Added more tolerance to the case design
    [Body3.sldprt, Body4.sldprt, breakout_assembly_bottom_only_lasercut.SLDASM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]
2021-03-16 Fixed case STL naming
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2021-04-06 Fully functional breakout firmware
    - Integrated preprocessor switches into the code so that changes do not
    need to be made to run simulations
    - Digital input sampling now occurs on falling edge of LVDS_OUT[0] which
    put it 180 deg. out of phase with when its latched to prevent
    metastability
    - Other very small changes
    - Need to figure out LED color scheme still
    [user_io.v]
2021-04-26 Remove incorrect link to BOM in breakout/README
    - Replace with a generic link to its documentation page.
    - This sould be done for all other boards at some point
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2021-05-26 breakout rev. 1.6
    - Minor revision that addes a load switch driven by the LM4622's PGOOD2
    output between 5V and FPGA Vin. This improves the power-on behavior of
    the board and prevents it from entering an unstable state that requires
    a manual reset via pushing the reset button.
    [breakout.brd, breakout.sch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]
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2021-10-26 Add digital input synchronizer stages to improve performance and stability
2021-11-02 Replace LVDS protocol by a 60Mhz 8b10b scheme
    [lvds_8b10b_receive.v]
2021-11-02 Fix switched digital inputs and output LED indicators
    [neopix_controller.v]
2022-06-26 Host and harp indication LEDs were swapped.
    [neopix_controller.v]
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2022-12-29 Updated the schematic to use Harp timestamp bus as input.
    The layout (.brd) is not ready yet.
    Replaced U48 SI8610 with U48 TLV70033DDCR (adds extra BOM line. PN TLV70033DDCR)
    Replaced C41 0402 0.1uF with C41 0805 10uF (same PN as C40 to not add extra BOM line)
    Replaced C43 0402 0.1uF with C43 0805 10uF (same PN as C40 to not add extra BOM line)
    Added R44 0402 13.3k (same PN as R19 to not add extra BOM line)
    Added R45 0402 10R (adds extra BOM line. PN CRCW040210R0FKEDHP)
    New BOM lines: 2
    Replaced components: 3
    [breakout.brd, breakout.sch]
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2023-05-15 Increase diameter of SMA holes
    - For headstage and clock connections to prevent SMA shell from rubbing
    on case
    [breakout_case_top_shell_2-headstage_b.SLDPRT]
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2024-01-19 Fix LEDs not blinking without HARP producer
    [neopix_controller.v]
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2024-06-20 Fix buttons not working with previous patch
    [user_io.v]

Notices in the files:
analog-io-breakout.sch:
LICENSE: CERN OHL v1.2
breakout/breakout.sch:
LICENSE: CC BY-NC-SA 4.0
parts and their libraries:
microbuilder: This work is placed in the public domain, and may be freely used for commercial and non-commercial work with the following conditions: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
